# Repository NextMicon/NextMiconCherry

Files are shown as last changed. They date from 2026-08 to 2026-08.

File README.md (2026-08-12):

# NextMicon FPGA

**This repository has been split into per-board repositories and is archived.**
Development continues at
[NextMicon/cherry](https://github.com/NextMicon/cherry),
[NextMicon/grape](https://github.com/NextMicon/grape), and
[NextMicon/melon](https://github.com/NextMicon/melon).

NextMicon is a family of open-source FPGA development boards. Choose the compact Cherry to get started, or Grape for a larger FPGA and more I/O.

| | [🍒 Cherry](boards/cherry/) | [🍇 Grape](boards/grape/) | [🍈 Melon](boards/melon/) |
| ----- | --- | --- | --- |
| FPGA  | Lattice iCE40HX8K-BG121 | AMD Spartan-7 XC7S50-CSGA324 | AMD Artix-7 XC7A100T-1FGG676C |
| Logic | 7,680 (4-input LUT) | 32,600 (6-input LUT) | 63,400 (6-input LUT) |
| BRAM  | 128 Kbit | 2,700 Kbit | 4,860 Kbit |
| DSP | — | 120 | 240 |
| GPIO  | 64 | 128 | 256 |

## 🍒 NextMicon Cherry

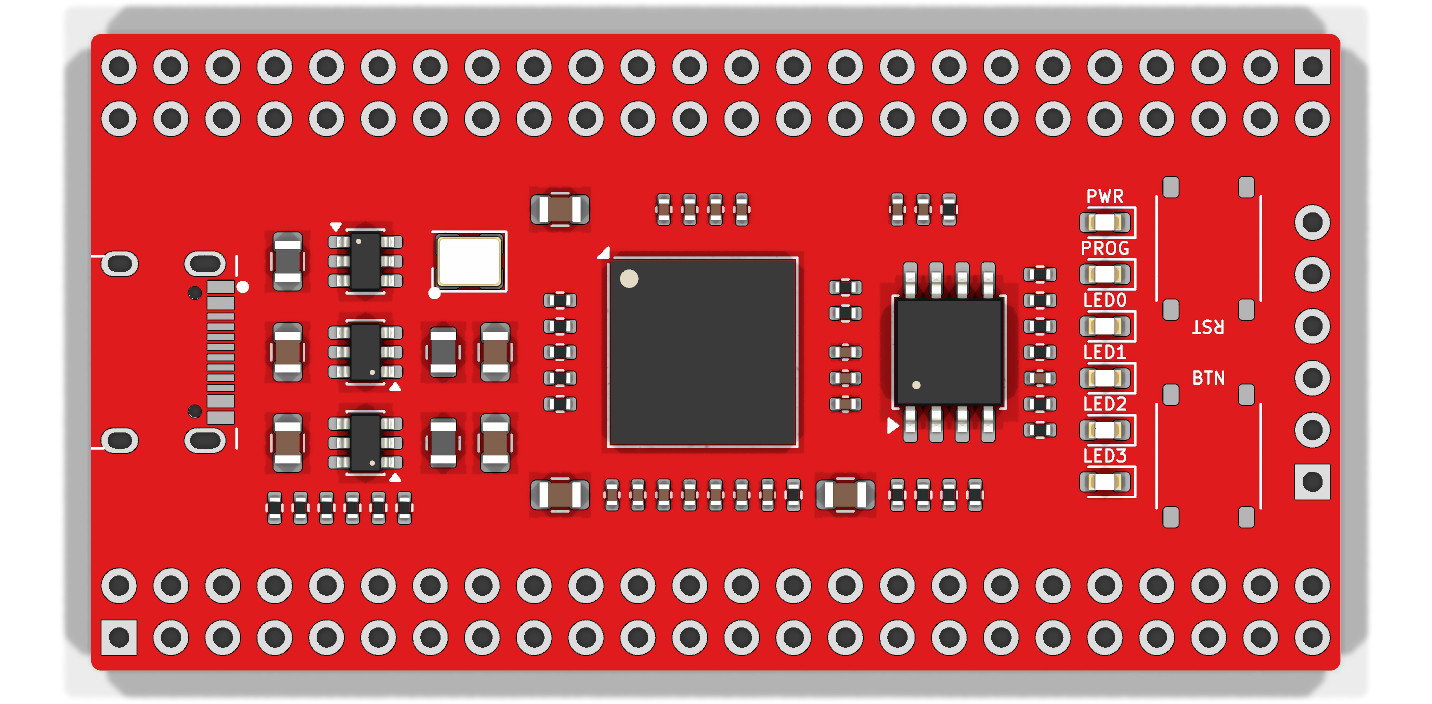
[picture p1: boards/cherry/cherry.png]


**A compact board for learning and small projects.** Cherry is built around the Lattice iCE40HX8K-BG121, with 7,680 LUTs, 64 GPIO pins, native USB Full-Speed, and protected `boot` plus writable `user` FPGA images. The repository includes its KiCad PCB design, fabrication outputs, bootloader HDL, and host application.

[Explore Cherry →](boards/cherry/)

Cherry firmware can be managed with the [`nmb` CLI](flash/cli/README.md) or the
[Web Serial flasher](flash/web/README.md).

## 🍇 NextMicon Grape

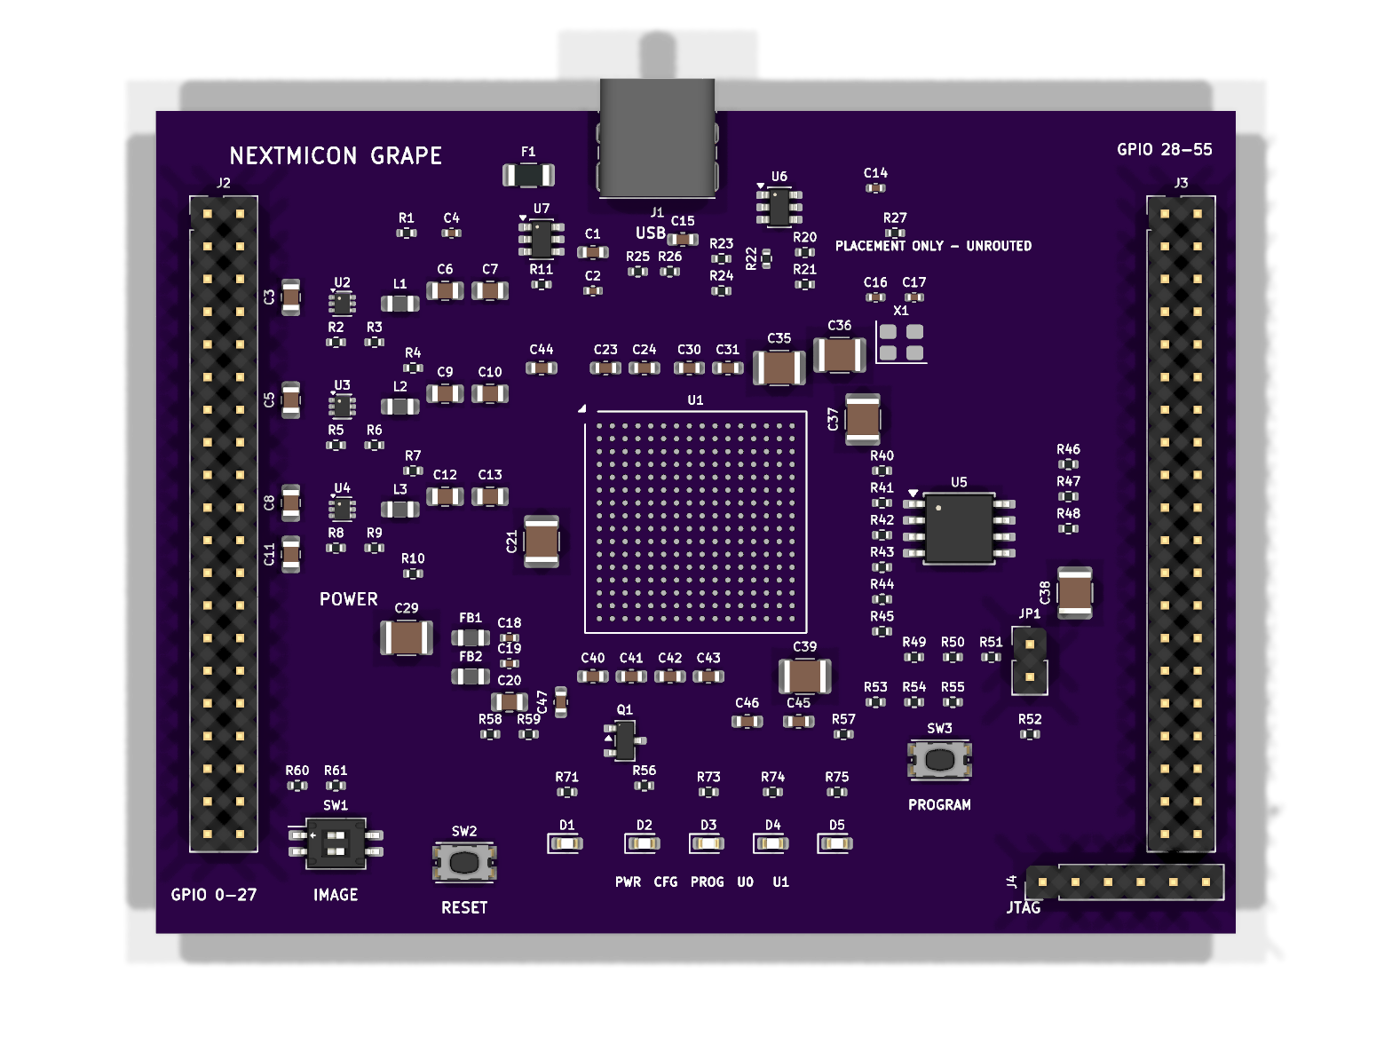
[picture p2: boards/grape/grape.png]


**A mid-range board for multi-channel phased-array acoustic field generation.** Grape uses the AMD Spartan-7 XC7S50-CSGA324 with 128 GPIO outputs and a 128-Mbit QSPI flash. Firmware is built and programmed with a fully open-source Yosys, nextpnr-xilinx, Project X-Ray, and openFPGALoader stack. Its schematic and PCB are being migrated from the earlier Artix-7 prototype.

[Explore Grape →](boards/grape/)

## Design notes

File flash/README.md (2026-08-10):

# NextMicon Flash CLI

`nmb` is the host-side programmer and image manager for NextMicon Cherry. Both
FPGA images enumerate as the same CDC ACM serial device. COBS-delimited frames
inside that serial stream provide independent BOOT, FLASH, and UART channels.

The complete wire format, including Web Serial usage, is documented in
[`doc/flash.md`](../../doc/flash.md).

## Build

```sh
cargo build --release
```

The executable is `target/release/nmb`. Linux users need permission to open the
CDC device, typically through the distribution's serial-port group or a udev
rule. Windows and macOS use their CDC ACM drivers.

### WebAssembly library

The library can also be built for the Web flasher:

```sh
wasm-pack build --target web --out-dir ../web/src/wasm/pkg --release
```

It exports `encodeMessageJson`, `decodeMessageJson`, and `crc32`.
`encodeMessageJson` converts a JSON message to the COBS-delimited wire frame;
`decodeMessageJson` validates and converts a wire frame back to JSON. The
generated package is consumed by `flash/web` and is not committed.

## Commands

List connected boards:

```console
$ nmb ls
cherry-0123

$ nmb ls --verbose
cherry-0123    boot    1234:0001    /dev/ttyACM0    NextMicon Cherry
```

Production VID/PID values are not allocated yet. By default `nmb` recognizes
the `NextMicon` manufacturer and `NextMicon Cherry` product strings. Discovery
can be restricted explicitly:

```sh
nmb --usb-id 1234:0001 ls
```

Warm boot either role:

```sh
nmb boot <board> <boot|user>
```

Erase, program, manifest, and read back the user image:

```sh
nmb flash <board> <bitstream.bin>
```

Start the image after successful verification:

```sh
nmb flash <board> <bitstream.bin> --boot
```

Before programming, `nmb` queries GET_INFO. If `user` is active, it requests
`boot`, waits for the same USB serial number to re-enumerate, verifies GET_INFO,
and then programs the single user image. `boot` is always protected;
factory/recovery updates use the external SPI header.

Use `nmb --help` or `nmb <command> --help` for all options. One framed request
defaults to a 30-second timeout and re-enumeration defaults to 15 seconds.

## Implementation

- `protocol.rs`: COBS framing, CRC32, channels, commands, and flash constants
- `message.rs`: validated JSON representation of a protocol frame
- `wasm.rs`: WASM exports for wire/JSON conversion and CRC32
- `serial.rs`: CDC port discovery, opening, streaming frame parser, and response matching
- `client.rs`: GET_INFO, BOOT, protected FLASH programming, and readback verification
- `manifest.rs`: 32-byte `NMF1` image manifest

The Rust host implementation and mock-device tests are complete. The matching
CDC ACM and frame engine still need to be implemented in Cherry HDL before a
physical board can answer the commands.

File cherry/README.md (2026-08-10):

# 🍒 NextMicon Cherry 🍒

FPGA Board for Beginners

## Schematic





## Specs

- FPGA: Lattice iCE40HX8K-BG121 (7680 LUTs, 9x9mm, 0.8mm pitch)
- GPIO: 36 pins (3.3V logic), 2x24 PinHeader x2 (paired contacts)
- Clock: 48MHz
- Flash: 32Mbit SPI Flash (30MB user area)
- Power: USB 5V → 3.3V → 1.2V
- Signal: 3.3V
- USB ESD Protection
- Switch: RESET / USER buttons, 2-bit Bitstream selector
- LED: PWR / CFG / USER0 / USER1 / PROG
- Board: 61mm x 31mm, 4-layer FR4

## Pinout

| Header | Pins |
| --- | --- |
| J2 (bottom rows, pin 1 = USB side) | 1 = 5V, 2 = 3V3, 3-5 = GND, 6 = CRESET_B, 7-24 = GPIO_1..18 |
| J3 (top rows, pin 24 = USB side) | 24 = 5V, 23 = 3V3, 22-19 = GND, 1-18 = GPIO_19..36 |
| J5 (right edge, pin 1 = bottom) | 1 = GND, 2 = CRESET_B, 3 = QSPI_CS_B, 4 = QSPI_SCK, 5 = QSPI_IO0, 6 = QSPI_IO1 |

J2 and J3 have two contacts for every pin number; the inner and outer contacts at the same position are electrically common.

## BOM

| Ref | Part | Package | Description | Cost | Buy |
| --- | --- | --- | --- | --- | --- |
| U2 | [W25Q32JVSSIM](data/W25Q32JV.pdf) | SOIC-8 208mil | 32Mbit SPI Flash | - | [digikey](https://www.digikey.com/en/products/result?keywords=W25Q32JVSSIM) |
| U3 | [iCE40HX8K-BG121](../parts/iCE40.pdf) | caBGA-121 0.8mm | FPGA 7680 LUTs | - | [digikey](https://www.digikey.com/en/products/result?keywords=ICE40HX8K-BG121) |
| U4-U5 | [TPS62A02](data/TPS62A02.pdf) | SOT-23-6 | 2A DC-DC Converter | $0.25  | [digikey](https://www.digikey.jp/ja/products/detail/texas-instruments/TPS62A02PDDCR/22147220)  |
| Q1 | BSS138 | SOT-23 | CDONE LED buffer | - | generic |
| D5 | USBLC6-2SC6 | SOT-23-6 | USB ESD protection | - | [digikey](https://www.digikey.jp/ja/products/result?keywords=USBLC6-2SC6) |
| X1 | OXETDLJANF-48.000000MHz | 3.2x2.5mm | 48MHz XO | - | generic |
| FB1 | BLM21AG601SH1D | 0805 | Ferrite bead (USB VBUS)| $0.19  | [digikey](https://www.digikey.jp/ja/products/detail/murata-electronics/BLM21AG601SH1D/2588067) |
| J1 | USB4085-GF-A | SMD 16pin | USB-C connector | $1.01  | [digikey](https://www.digikey.jp/ja/products/detail/gct/USB4085-GF-A/9859662) |
| J2-J3 | Pin header 2x24, paired contacts  | 2.54mm Pitch  | GPIO | - | generic |
| J5 | Pin header 1x06 | 2.54mm Pitch  | External SPI programming | - | generic |
### Passives

| Ref | Value | Pkg  | Qty | Notes |
| --- | ----- | ---- | --- | --- |
| C1-C2 | 10uF  | 0805 | 2 | 5V input bulk |
| C3-C4 | 22uF  | 0805 | 2 | 3V3 / 1V2 Buck output |
| C5-C7 | 10uF  | 0805 | 3 | Rail bulk (+3V3A / +1V2 / +3V3) |
| C8-C25  | 100nF | 0402 | 18  | IC Decoupling |
| C27 | 10uF  | 0805 | 1 | FPGA rail bulk |
| C28 | 100nF | 0402 | 1 | iCE40 VCCPLL filter |
| L1-L2 | 1uH | 0805 | 2 | Buck inductor (pick Isat >= 1.5A) |
| R1 | 100k  | 0402 | 1 | 3.3V feedback divider (1%) |
| R2 | 22k | 0402 | 1 | 3.3V feedback divider (1%) |
| R3-R4 | 100k  | 0402 | 2 | 1.2V feedback divider (1%) |
| R5-R6 | 5.1k  | 0402 | 2 | USB-C CC pull-down |
| R8-R11  | 10k | 0402 | 4 | Configuration and button pull-ups |
| R12 | 1k | 0402 | 1 | CDONE pull-up |
| R13 | 100 | 0402 | 1 | iCE40 VCCPLL filter |
| R14-R15 | 68 | 0402 | 2 | USB D+/D- series termination |
| R16 | 1.5k  | 0402 | 1 | Software-controlled USB D+ pull-up |
| R17 | 10k | 0402 | 1 | CRESET_B pull-up |
| R19-R22 | 1k | 0402 | 4 | LED current limiting |
| D1-D4 | LED | 0603 | 4 | PWR / CFG / USER0 / USER1 |
| SW1,SW3 | Tact  | SMD  | 2 | RESET / USER button |
| SW2 | DIP x2| SMD  | 1 | IMAGE cold-boot selector |

## Build

Toolchain: [Yosys](https://github.com/YosysHQ/yosys) + [nextpnr-ice40](https://github.com/YosysHQ/nextpnr) + [icestorm](https://github.com/YosysHQ/icestorm)

The pin and timing constraint files are [`src/cherry.pcf`](src/cherry.pcf) and
[`src/cherry.sdc`](src/cherry.sdc). Yosys produces the JSON netlist and nextpnr
consumes the PCF/SDC:

```bash
mkdir -p build
yosys -p 'synth_ice40 -top top -json build/top.json' rtl/top.v
nextpnr-ice40 --hx8k --package bg121 --freq 48 \
  --json build/top.json --pcf src/cherry.pcf --sdc src/cherry.sdc \
  --asc build/top.asc
icepack build/top.asc build/top.bin
```

Only ports present in the top-level HDL need to be used; nextpnr reports the
other PCF entries as harmless `unmatched constraint` warnings. Keep `clk_48m`
as an input. The commented SPI-flash constraints are intentionally reserved
because the flash and FPGA configuration controller share those four nets.

For recovery programming, power the board from USB and connect a 3.3V SPI
programmer to J5. Hold `CRESET_B` low while accessing the W25Q32, then release
it to boot the newly written image.

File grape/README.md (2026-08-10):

# 🍇 NextMicon Grape 🍇

NextMicon Grape is a FPGA Board for cyuukyusya.
Xilinx Artix-7 has more LUT cores and more fast signal processing units.

## Current design

- FPGA: AMD Artix-7 `XC7A35T-1FTG256C`
- Configuration: W25Q128JV 128-Mbit QSPI, four 4-MiB image slots
- Boot: Golden image at address zero, then `WBSTAR`/`IPROG` through `ICAPE2`
- USB: USB-C Full-Speed device connected directly to 3.3-V FPGA I/O
- Clock: 48 MHz oscillator on an SRCC input
- Power: USB 5 V to sequenced 1.0 V, 1.8 V and 3.3 V TPS62A02 rails
- I/O: 56 named 3.3-V GPIO signals on two 2x20 headers
- Recovery: external six-pin JTAG header, `PROGRAM_B`, and true cold-reset
- FPGA package and decoupling: FTG256, based on AMD UG475/UG483

The KiCad project is in [`pcb/src`](pcb/src).  No PCB layout has been created
yet.

## Important design choices

`M[2:0]` is strapped to `001` for Master SPI.  All VCCO banks, the
configuration bank, and the flash operate at 3.3 V; `CFGBVS` is therefore tied
to 3.3 V.  The two-bit `IMAGE` switch is normal FPGA GPIO sampled by the
Golden image—it is not a direct configuration-mode selector.

`JP1 GOLDEN_LOCK` pulls the flash `/WP/IO2` signal low.  Fit the jumper for
hardware-assisted x1-SPI Golden protection after setting the Winbond block and
status-register protection bits.  Remove it for factory update or future x4
QSPI operation.  Firmware must keep the FPGA IO2 pin high-impedance while the
jumper is fitted.

The TPS22917 load switch limits USB attach inrush into the regulator input
capacitors.  Its CT capacitor `C2` returns to `VBUS_FUSED` as required by the
device topology and is deliberately marked `TUNE`; its final value must be
selected from measured inrush and rise time.  The present design must remain
inside the current advertised by the connected USB-C source.  High-power user
images may require a later auxiliary-power option.

The Master-SPI mode straps and `PUDC_B` use 1-kohm resistors.  Flash IO2 and
IO3 use 4.7-kohm pull-ups for x4 configuration.  The XADC uses its on-chip
reference, with `VREFP`/`VREFN` returned locally to filtered analog ground.

## Generate and check

Requires KiCad 10.0.x and Python 3.  The generated schematic embeds its symbols.

```bash
python3 grape/pcb/tools/generate_schematic.py
kicad-cli sch upgrade --force grape/pcb/src/grape.kicad_sch
kicad-cli sch erc --severity-all \
  -o grape/pcb/erc.rpt grape/pcb/src/grape.kicad_sch
kicad-cli sch export pdf \
  -o grape/pcb/schematic.pdf grape/pcb/src/grape.kicad_sch
```

## Before PCB fabrication

- Recheck every FTG256 ball against the AMD package pin file and UG475.
- Run Xilinx Power Estimator with the intended maximum application image.
- Validate regulator stability, inductors, capacitor DC bias and startup order.
- Tune USB series resistors and load-switch rise time from measurements.
- Decide whether x1 physical Golden protection or x4 boot speed is the product
  default.
- Extend and validate the OSS bitstream writer for configuration rate, x4 SPI,
  CRC watchdog and automatic fallback.

## Primary references

- [AMD UG470: 7 Series FPGAs Configuration User Guide](https://docs.amd.com/v/u/en-US/ug470_7Series_Config)
- [AMD UG475: 7 Series FPGAs Packaging and Pinout](https://docs.amd.com/v/u/en-US/ug475_7Series_Pkg_Pinout)
- [AMD UG480: 7 Series XADC User Guide](https://docs.amd.com/r/en-US/ug480_7Series_XADC)
- [AMD UG483: 7 Series FPGAs PCB Design Guide](https://docs.amd.com/v/u/en-US/ug483_7Series_PCB)
- [TI TPS62A02 data sheet](https://www.ti.com/lit/ds/symlink/tps62a02.pdf)
- [TI TPS22917 data sheet](https://www.ti.com/lit/ds/symlink/tps22917.pdf)
- [Winbond W25Q128JV data sheet](https://www.winbond.com/resource-files/w25q128jv%20revf%2003272018%20plus.pdf)

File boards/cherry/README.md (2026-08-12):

# 🍒 NextMicon Cherry 🍒

FPGA Board for Beginners

## Repository layout

- [`board`](board/): KiCad design and fabrication outputs
- [`breakout`](breakout/): PMod breakout board
- [`firmware`](firmware/): FPGA HDL and constraints

## Schematic





## Specs

- FPGA: Lattice iCE40HX8K-BG121 (7680 LUTs, 9x9mm, 0.8mm pitch)
- GPIO: 64 pins (3.3V logic)
- PLL: 2x sysCLOCK PLL, external reference inputs broken out on J3 position 22 (PLL0_IN/PLL1_IN)
- Clock: 48MHz
- Flash: 32Mbit SPI Flash (3.5 MiB user-data area)
- Power: USB 5V → 3.3V → 1.2V
- Signal: 3.3V
- USB ESD Protection
- Switch: CRESET_B reset / USER buttons
- LED: PWR / PROG / USER0-USER3
- Board: 61mm x 31mm, 4-layer FR4

## Pinout

J2 and J3 are standard 2x24 headers. Each connector position `k` (1..24) has an
inner-row pad `2k-1` (odd) and an outer-row pad `2k` (even); the two rows carry
independent signals.

GPIOs are grouped in blocks of eight: D0-D3 sit on the inner row and D4-D7 sit
directly opposite on the outer row of the same four positions, so every block
forms one contiguous 2x4 window flanked by GND (inner) / 3V3 (outer) columns.
J2 carries GPIO_1..32 and J3 carries GPIO_33..64.

J2 (bottom edge, position 1 = USB side):

| Position | Inner row (odd pads) | Outer row (even pads) |
| --- | --- | --- |
| 1 | 5V | 5V |
| 2 | 3V3 | 3V3 |
| 3 | CRESET_B | 3V3 |
| 4 | GND | 3V3 |
| 5-8 | GPIO_1..4 | GPIO_5..8 |
| 9 | GND | 3V3 |
| 10-13 | GPIO_9..12 | GPIO_13..16 |
| 14 | GND | 3V3 |
| 15-18 | GPIO_17..20 | GPIO_21..24 |
| 19 | GND | 3V3 |
| 20-23 | GPIO_25..28 | GPIO_29..32 |
| 24 | GND | 3V3 |

J3 (top edge, position 24 = USB side):

| Position | Inner row (odd pads) | Outer row (even pads) |
| --- | --- | --- |
| 1 | GND | 3V3 |
| 2-5 | GPIO_33..36 | GPIO_37..40 |
| 6 | GND | 3V3 |
| 7-10 | GPIO_41..44 | GPIO_45..48 |
| 11 | GND | 3V3 |
| 12-15 | GPIO_49..52 | GPIO_53..56 |
| 16 | GND | 3V3 |
| 17-20 | GPIO_57..60 | GPIO_61..64 |
| 21 | GND | 3V3 |
| 22 | PLL0_IN | PLL1_IN |
| 23 | 3V3 | 3V3 |
| 24 | 5V | 5V |

| Header | Pins |
| --- | --- |
| J4 (right edge, pin 1 = bottom) | 1 = GND, 2 = CRESET_B, 3 = QSPI_CS_B, 4 = QSPI_SCK, 5 = QSPI_IO0, 6 = QSPI_IO1 |

The breakout board ([`breakout/`](breakout/)) accepts the Cherry via female
pin sockets (J2/J3/J4 plug straight in) and brings the 64 GPIOs out as eight
standard Pmod ports (8 GPIO each), plus an SPI header and a power/CRESET
utility header.

## BOM

| Ref | Part | Package | Description | Cost  | Buy |
| ----- | --- | --- | --- | ----- | --- |
| U1 | [W25Q32JVSSIQ](../../parts/W25Q32JV.pdf) | SOIC-8 208mil | 32Mbit SPI Flash | - | [digikey](https://www.digikey.com/en/products/result?keywords=W25Q32JVSSIQ) |
| U2 | [iCE40HX8K-BG121](../../parts/iCE40.pdf) | caBGA-121 0.8mm | FPGA 7680 LUTs | - | [digikey](https://www.digikey.com/en/products/result?keywords=ICE40HX8K-BG121) |
| U3-U4 | [TPS62A02](../../parts/TPS62A02.pdf) | SOT-23-6 | 2A DC-DC Converter | $0.25 | [digikey](https://www.digikey.jp/ja/products/detail/texas-instruments/TPS62A02PDDCR/22147220) |
| D1 | USBLC6-2SC6 | SOT-23-6 | USB ESD protection | - | [digikey](https://www.digikey.jp/ja/products/result?keywords=USBLC6-2SC6) |
| X1 | OXETDLJANF-48.000000MHz | 3.2x2.5mm | 48MHz XO | - | generic |
| FB1 | GZ2012D601TF | 0805 | Ferrite bead (USB VBUS)  | - | [lcsc](https://www.lcsc.com/search?q=GZ2012D601TF) |
| J1 | USB4085-GF-A | SMD 16pin | USB-C connector | $1.01 | [digikey](https://www.digikey.jp/ja/products/detail/gct/USB4085-GF-A/9859662) |
| J2-J3 | Pin header 2x24 | 2.54mm Pitch | GPIO | - | generic |
| J4 | Pin header 1x06 | 2.54mm Pitch | External SPI programming | - | generic |
### Passives

| Ref | Value | Pkg  | Qty |
| --- | --- | ---- | --- |
| C1,C3,C5,C14,C17 | 10uF | 0805 | 5 |
| C4,C6 | 22uF | 0805 | 2 |
| C2,C7-C13,C15-C16,C18-C24 | 100nF | 0402 | 17  |
| L1-L2 | TFM201208ALD-1R0MTCA | 0805 | 2 |
| R1-R2 | 5.1k | 0402 | 2 |
| R3,R5-R6 | 100k | 0402 | 3 |
| R4 | 22k | 0402 | 1 |
| R7 | 1.5k | 0402 | 1 |
| R8-R9 | 68 | 0402 | 2 |
| R10-R13,R16-R17,R22-R23 | 10k | 0402 | 8 |
| R14,R18-R21,R24-R25 | 1k | 0402 | 7 |
| R15 | 100 | 0402 | 1 |
| D2-D4,D6-D7 | KT-0603R | 0603 | 5 |
| D5 | LED_AMBER_0603 | 0603 | 1 |
| SW1-SW2 | TS-1187A-B-A-B | SMD  | 2 |
| JP1-JP2 | Solder jumper | SMD  | 2 |

## Build

Toolchain: [Yosys](https://github.com/YosysHQ/yosys) + [nextpnr-ice40](https://github.com/YosysHQ/nextpnr) + [icestorm](https://github.com/YosysHQ/icestorm)

The pin and timing constraint files are
[`firmware/cherry.pcf`](firmware/cherry.pcf) and
[`firmware/cherry.sdc`](firmware/cherry.sdc). Yosys produces the JSON netlist
and nextpnr consumes the PCF/SDC:

```bash
mkdir -p build
yosys -p 'synth_ice40 -top top -json build/top.json' rtl/top.v
nextpnr-ice40 --hx8k --package bg121 --freq 48 \
  --json build/top.json --pcf firmware/cherry.pcf --sdc firmware/cherry.sdc \
  --asc build/top.asc
icepack build/top.asc build/top.bin
```

Only ports present in the top-level HDL need to be used; nextpnr reports the
other PCF entries as harmless `unmatched constraint` warnings. Keep `clk_48m`
as an input. The commented SPI-flash constraints are intentionally reserved
because the flash and FPGA configuration controller share those four nets.

For recovery programming, power the board from USB and connect a 3.3V SPI
programmer to J4. Hold `CRESET_B` low while accessing the W25Q32, then release
it to boot the newly written image.

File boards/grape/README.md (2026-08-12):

# 🍇 NextMicon Grape 🍇

Mid-range FPGA board for multi-channel phased-array acoustic field generation.

## Repository layout

- [`board`](board/): KiCad design and fabrication outputs
- [`breakout`](breakout/): breakout and test-fixture designs
- [`firmware`](firmware/): FPGA HDL and constraints

## Schematic



## Target specs

- FPGA: AMD Spartan-7 `XC7S50-1CSGA324C`
  - 52,160 logic cells
  - 120 DSP48E1 slices
  - 2,764,800 bits of Block RAM
  - 210 user I/O pins in the CSGA324 package
- GPIO: 128 pins reserved for phased-array channel outputs
- GPIO logic level: 3.3 V
- Channel count: 128 channels with one GPIO per channel
- Clock: 100 MHz onboard oscillator; USB 48 MHz and application clocks generated by MMCM/PLL
- Configuration: 128-Mbit QSPI flash
- USB: USB-C for power and control
- Power: USB 5 V input with FPGA core, auxiliary, and I/O rails
- Recovery: external JTAG and `PROGRAM_B`
- FPGA package: CSGA324, 15 mm x 15 mm, 0.8 mm ball pitch
- GPIO connectors: four 2x24, 2.54 mm headers using the Cherry 8-pin group geometry
- Placement study: 140 mm x 70 mm, four layers, deliberately unrouted
- Final regulator sizing: pending electrical implementation verification

The 128 GPIO signals are logic-level timing outputs. External level shifters,
gate drivers, and power stages must be used to drive acoustic transducers; the
transducers must not be driven directly from FPGA pins.

## Intended architecture

Grape receives phase and optional amplitude parameters from a host and produces
phase-synchronous waveforms for up to 128 acoustic channels. The baseline
firmware uses a common phase accumulator and per-channel phase offsets stored in
Block RAM. All channel parameters are double-buffered so that an update can be
applied to every output on the same clock boundary.

The baseline design targets externally calculated phase values. Coordinate-to-
phase calculation, multi-focus synthesis, and closed-loop field control are
reserved for higher-end boards such as Melon.

## I/O allocation

The CSGA324 package provides up to 210 user I/O pins. The checked allocation is:

| Function | Pins | Notes |
| --- | ---: | --- |
| Phased-array outputs | 128 | Banks 15, 34 and 35; 3.3 V |
| Clock and USB | 3 | Bank 14; 100 MHz plus USB D+/D- |
| User strap, button and LEDs | 4 | Bank 14 |
| Configuration and JTAG | Dedicated | Bank 0 and Bank 14 configuration pins |

The generated and machine-checked mapping is [`board/pinout.csv`](board/pinout.csv).
Each set of 32 GPIOs uses one 2x24 header. As on Cherry, every group of eight is
a contiguous 2x4 window with four inner-row and four outer-row signals; group
separators carry GND on the inner row and 3.3 V on the outer row. The mapping
is generated from AMD's official `xc7s50csga324pkg.csv` by
[`board/tools/generate_pinout.py`](board/tools/generate_pinout.py).

If complementary high-side/low-side signals are generated directly by the
FPGA, 128 GPIOs provide 64 channels. The preferred 128-channel implementation
uses one FPGA output per channel and generates complementary drive signals in
the external driver stage.

## Current hardware status

The existing KiCad files under [`board/src`](board/src) describe the earlier
Artix-7 `XC7A35T-1FTG256C`, 56-GPIO prototype. They do not yet implement this
Spartan-7 target specification. The schematic, PCB, power tree, FPGA symbol,
pin assignments, decoupling, and constraints must be migrated to
`XC7S50-1CSGA324C` before fabrication.

The replacement six-unit KiCad symbol
[`board/src/grape-fpga.kicad_sym`](board/src/grape-fpga.kicad_sym) is generated
from AMD's production `xc7s50csga324pkg.csv`; it contains all 324 unique package
balls and uses the matching `Package_BGA:Xilinx_CSGA324` footprint. Regenerate
it with [`board/tools/generate_fpga_symbol.py`](board/tools/generate_fpga_symbol.py).
The symbol and checked 128-GPIO pinout are ready; integration into the new
schematic and PCB is in progress. The old schematic and placement board remain
non-fabrication references until that migration is complete.

## Build

Grape is developed with a fully open-source FPGA toolchain. AMD Vivado is not
used or required by the intended build and programming workflow.

- HDL synthesis: [Yosys](https://github.com/YosysHQ/yosys)
- Place and route: [nextpnr-xilinx](https://github.com/gatecat/nextpnr-xilinx)
- 7-series device database and bitstream support:
  [Project X-Ray](https://github.com/f4pga/prjxray)
- Timing constraints: XDC
- Bitstream and QSPI programming:
  [openFPGALoader](https://github.com/trabucayre/openFPGALoader)

The repository will provide reproducible command-line build scripts and pinned
tool/database revisions. The exact `xc7s50csga324-1` part is present in the
Project X-Ray database; the complete build and programming flow must still be
validated on Grape hardware before release.

The final top-level port names, XDC pin constraints, clock constraints, and
bitstream/flash programming procedure will be documented after the schematic
and connector pinout are fixed.

## Before PCB fabrication

- Assign all 128 outputs using the official CSGA324 package pin file.
- Reserve configuration, JTAG, clock, USB/control, and debug pins first.
- Check every I/O bank voltage and the simultaneous-switching-output limits.
- Establish a worst-case power budget from AMD data-sheet values and measured
  activity from the open-source implementation.
- Verify regulator capacity, startup sequencing, thermal margin, and decoupling.
- Validate that the external driver input load is within the FPGA I/O limits.
- Add source-series termination where signal-integrity analysis requires it.
- Complete schematic ERC and routed-board DRC before generating fabrication data.

## Primary references

- [AMD DS189: Spartan-7 FPGAs Data Sheet](https://docs.amd.com/v/u/en-US/ds189-spartan-7-data-sheet)
- [AMD DS180: 7 Series FPGAs Overview](https://docs.amd.com/v/u/en-US/ds180_7Series_Overview)
- [AMD UG470: 7 Series FPGAs Configuration User Guide](https://docs.amd.com/v/u/en-US/ug470_7Series_Config)
- [AMD UG475: 7 Series FPGAs Packaging and Pinout](https://docs.amd.com/v/u/en-US/ug475_7Series_Pkg_Pinout)
- [AMD UG479: 7 Series DSP48E1 Slice User Guide](https://docs.amd.com/v/u/en-US/ug479_7Series_DSP48E1)
- [AMD UG483: 7 Series FPGAs PCB Design Guide](https://docs.amd.com/v/u/en-US/ug483_7Series_PCB)

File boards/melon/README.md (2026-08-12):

# 🍈 NextMicon Melon 🍈

High-density NextMicon FPGA board placement study.

## Target

- FPGA: AMD Artix-7 `XC7A100T-1FGG676C`
- GPIO: 256 pins, 3.3 V logic
- GPIO connectors: eight 2x24, 2.54 mm headers
- GPIO geometry: 32 groups of eight, using the same contiguous 2x4 windows as Cherry and Grape
- Configuration: protected boot image followed by an ICAPE2/WBSTAR/IPROG user image
- Default user selection: back-side `DEFAULT_USER` solder jumper
- Clock: independent onboard oscillator; not required to match Cherry or Grape
- Placement PCB: 150 mm x 120 mm, six layers, deliberately unrouted

## Placement

The current [`board/src/melon.kicad_pcb`](board/src/melon.kicad_pcb) is a
placement-only board with no schematic nets, tracks, vias, planes, or copper
zones. The eight headers are arranged two per row across four rows. Adjacent
header rows use 7.62 mm center spacing, leaving one 2.54 mm pin-row interval
between their bodies. They provide
32 GPIO positions each, for 256 GPIOs total;
the remaining 16 contacts on every 2x24 header are reserved for GND, 3.3 V and
board utility connections following the Cherry grouping pattern.

The checked FPGA-to-header allocation is [`board/pinout.csv`](board/pinout.csv).
It is generated from AMD's production `xc7a100tfgg676pkg.csv` by
[`board/tools/generate_pinout.py`](board/tools/generate_pinout.py).

Regulator footprints are placement reservations only. Parts and thermal/current
ratings must be selected from a final power estimate before fabrication.

## Regeneration

```bash
python3 board/tools/generate_pinout.py
python3 board/tools/generate_placement.py
kicad-cli pcb drc --all-track-errors \
  -o board/placement-drc.rpt board/src/melon.kicad_pcb
```

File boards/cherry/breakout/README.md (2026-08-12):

# Cherry Pmod breakout board

Cherryのピンヘッダ(J2/J3/J4)を上から**ピンソケット(S2/S3/S4)に挿し込み**、全64本のGPIOを8ポートのPmod(2×6、12ピン)として引き出すブレークアウト基板です。工場テスト(factory-test.sh)と、Pmodモジュールを挿しての動作確認の両方に使えます。

## ポート構成

| ポート | GPIO | 位置 |
| --- | --- | --- |
| PMOD1  | GPIO_1-8 | 下辺 左 |
| PMOD2  | GPIO_9-16  | 下辺 中左 |
| PMOD3  | GPIO_17-24 | 下辺 中右 |
| PMOD4  | GPIO_25-32 | 下辺 右 |
| PMOD5  | GPIO_33-40 | 上辺 右 |
| PMOD6  | GPIO_41-48 | 上辺 中右 |
| PMOD7  | GPIO_49-56 | 上辺 中左 |
| PMOD8  | GPIO_57-64 | 上辺 左 |

Cherry側のGPIOはブロック対配置(D0-D3が内側列、D4-D7がその対向の外側列)なので、各Pmodポートは Cherry の1つの2×4ブロックにそのまま対応します。各ポートのピン配置はPmod標準どおり: 1-4 = D0-D3、5 = GND、6 = 3V3、7-10 = D4-D7、11 = GND、12 = 3V3。D0が各ブロックの最小GPIO番号です(例: PMOD5のD0 = GPIO_33)。Pmodソケットは2×6のライトアングル・メスを基板端向きに実装します(実装前にピン1の向きをシルクの角パッドで確認してください)。

- S2/S3: 2×24ピンソケット。Cherry J2/J3が挿さります(ソケットのピン番号 = Cherryのパッド番号)。
- S4: 1×6ピンソケット。Cherry J4が挿さります。
- J5: Cherry J4のSPI/CRESET/GNDを引き出す1×6ピンヘッダ(右辺)。
- J6: +5V / +3V3 / GND / CRESET_B のユーティリティ、1×6ピンヘッダ(左辺)。
- USB-CはCherry本体へ直接接続します。基板にはUSB回路を載せません。
- F.Fabレイヤの破線はCherry外形、MH1--MH4はM3スタンドオフ用です。

電源はGND(裏面ベタ)と+3V3(表面ベタ)のゾーンで配電し、Cherryの全GND/3V3ピンとPmodの電源ピンを共通ネットに接続しています。GPIOと SPI/CRESET は1:1配線です。ソケットピンと引き出し先の対応は[`pinmap.csv`](pinmap.csv)を参照してください(`fixture_ref`はソケット:パッド番号、`dut_pin`はコネクタ位置1..24、`breakout_pin`は引き出し先)。

[`src/fixture.kicad_pcb`](src/fixture.kicad_pcb)は[`tools/gen_fixture.py`](tools/gen_fixture.py)で生成しています(配線・ゾーン込み。再生成後は pcbnew Python でゾーンを塗り直してください)。座標や割当を変えるときは手編集せずスクリプトを直して再生成してください。

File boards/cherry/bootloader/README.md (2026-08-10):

# NextMicon Cherry firmware

Native USB management, boot, flash, and runtime HDL for the iCE40HX8K-BG121.

## USB transport

Every image enumerates as one CDC ACM serial device with the same endpoint
layout:

| Purpose | Endpoint | Transfer |
| --- | --- | --- |
| CDC notification | EP1 IN (`0x81`) | Interrupt |
| CDC serial host-to-FPGA | EP2 OUT (`0x02`) | Bulk |
| CDC serial FPGA-to-host | EP2 IN (`0x82`) | Bulk |

The CDC byte stream carries COBS-delimited frames. A channel byte inside each
frame selects BOOT, FLASH, or UART, so arbitrary UART data is never scanned for
a reboot escape sequence. The protected `boot` image reports BOOT and FLASH
capabilities; the writable `user` image reports BOOT and UART capabilities.

The protocol constants are in `src/protocol.veryl` and the complete wire
format is documented in [`doc/flash.md`](../../../doc/flash.md).

The current code defines the shared constants, endpoint policy, and final
warm-boot request controller. The USB physical engine, CDC standard/class
request handler, COBS frame codec, flash commands, and UART FIFOs remain to be
implemented.

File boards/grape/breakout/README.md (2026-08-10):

# NextMicon Grape breakout

Grape用のbreakout boardおよびfactory-test fixtureをこのディレクトリで管理します。
設計はまだ未着手です。

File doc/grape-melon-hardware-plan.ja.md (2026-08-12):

# Grape / Melon ハードウェア設計判断

作成日: 2026-08-12

この文書は、Cherryを基準にGrapeおよびMelonの回路図・基板を設計する前に固定した
ハードウェア要件である。対象デバイスはGrapeが`XC7S50-1CSGA324C`、Melonが
`XC7A100T-1FGG676C`である。

## 調査資料

取得したAMD公式資料は[`../parts/amd/`](../parts/amd/)に保存した。

- DS180: 7 Series FPGAs Overview
- DS181: Artix-7 DC and AC Switching Characteristics
- UG470: 7 Series FPGAs Configuration User Guide
- UG475: 7 Series FPGAs Packaging and Pinout
- UG483: 7 Series FPGAs PCB Design Guide
- GrapeのSpartan-7電気特性は[DS189](https://docs.amd.com/r/en-US/ds189-spartan-7-data-sheet)
  revision 1.11も参照する。
- QSPIフラッシュは[`../parts/W25Q128JV.pdf`](../parts/W25Q128JV.pdf)を参照する。

回路図のピン割当を確定する際は、UG475の概略図だけでなく対象デバイス・パッケージの
公式ASCII package pin fileと照合する。Grapeの既存`board/pinout.csv`は照合元を明記して
再生成し、Melonにも同じ生成・検査手順を用いる。

## 固定する構成

### 電源

- USB VBUSから`1.0 V`（VCCINT/VCCBRAM）、`1.8 V`（VCCAUX）、`3.3 V`
  （VCCO）を生成する。
- 推奨投入順序は`VCCINT/VCCBRAM`、`VCCAUX`、`VCCO`、切断時は逆順とする。
- 全GPIOバンクは3.3 V HR I/Oとして用いる。Bank 0も3.3 Vとし、`CFGBVS`は
  `VCCO_0`へ接続する。Master SPIで使うBank 14/15もコンフィグ時の電圧整合を取る。
- 各レールの容量、過渡応答、起動時間、FPGA直下のデカップリング配置は、最終I/O
  トグル率を入力した電力見積り後に確定する。Grape旧回路のレギュレーター定格を
  Melonへ無条件にコピーしない。
- Grapeは4層を最低構成、MelonのFGG676は電源島とBGA escapeの都合から6層以上を
  初期案とし、4層へ縮小しない。

### コンフィグレーションとブート

- モードはMaster SPI x4、フラッシュは128 Mbit以上とする。
- アドレス0に書換え保護した`boot`（AMD文書でいうgolden image）を置く。
- 電源投入時は常に`boot`をコンフィグレーションする。`boot`がUSB Full-Speed CDC
  デバイスとして列挙し、ユーザーイメージの検査・書込みを行う。
- userを起動するときは`boot`内の`ICAPE2`から`WBSTAR`へuser先頭アドレスを書き、
  `IPROG`を発行する。userのコンフィグレーション失敗時はアドレス0のbootへ
  fallbackする。
- 裏面に`DEFAULT_USER`はんだジャンパーを置く。オープンはboot待機、ブリッジは
  bootがUSB D+プルアップを有効にする前に検査済みuserへ進む。これは7-seriesの
  モードピンではなく、bootコンフィグレーション後に読む専用GPIOである。
- `DEFAULT_USER`をブリッジしていてもboot自体は最初に必ずロードされる。復旧のため、
  userマニフェスト不正時と指定ボタン押下時はbootに留まる。
- bootとuserは同じUSB VID/PID、descriptorおよびCDC endpoint構成を使う。切替え前に
  USBを論理切断し、user起動後に再列挙する。
- `PROGRAM_B`は4.7 kΩ以下でpull-upし、押しボタンとJTAGヘッダーへ出す。
  `INIT_B`も4.7 kΩ以下でpull-upする。`DONE`、`INIT_B`は状態確認できるようにする。
- `PROGRAM_B`を電源投入時からLowに保持してコンフィグを止める設計にはしない。
  UG470の指定どおり、必要なら`INIT_B`で初期化後の進行を止める。
- JTAG、QSPI、PROGRAM_B、GND、3.3 Vを復旧用ヘッダーまたはテストパッドへ出す。

### クロック

- GrapeおよびMelonの外部基準クロックをCherryと同じ48 MHzには固定しない。
- USB Full-Speed PHY/プロトコル処理に必要なクロックドメインは、外部基準クロックから
  FPGA内蔵MMCM/PLLで生成する。生成可能な周波数、VCO範囲、入力ジッタ、起動・lock時間を
  実装前に確認する。
- 外部発振器はGrapeとMelonで個別に選定できる。位相配列出力の時間分解能、DSP処理、
  クロック対応ピン、ジッタ、消費電力、部品入手性を比較して周波数を決める。
- 発振器は対象bankのclock-capable inputへ接続し、単端／差動方式とI/O電圧は選定部品に
  合わせる。XDCには入力クロック周期と生成クロックを明記する。
- bootとuserは同じ外部発振器設定およびUSBクロック生成条件を共有する。

### GPIOヘッダー

- Cherryと同じ2列2.54 mmヘッダーを用い、GPIO 8本を連続した`2x4`窓にする。
- 各グループは内列4本、対向する外列4本とし、グループ間に内列GND／外列3.3 Vの
  電源位置を置く。コネクター端にもGND、3.3 V、必要な5 Vを置く。
- Grapeは16グループ、合計128 GPIO、Melonは32グループ、合計256 GPIOとする。
- 1グループを可能な限り同一I/O bankに収める。差動対は対向ピンへ分断せず、クロック
  capable pin、VREF、コンフィグ兼用ピンを先に予約する。
- 初期XDCは`LVCMOS33`、`DRIVE 4`、`SLEW SLOW`とし、128/256本同時スイッチングを
  想定したSSO確認なしに駆動力やslewを上げない。

## 現行ファイルの扱い

Grapeの現行回路図は`XC7A35T-1FTG256C`用であり、目的のSpartan-7 CSGA324回路として
製造してはならない。現行PCBは部品配置のみで、配線、via、plane、zoneがない。
新しい回路図へ移行後、ネットリストから基板を作り直す。

Melonはまだボードディレクトリがないため、Grapeの完成済み共通ブロックをテンプレートに
する。ただしFGG676の電源ピン、bank構成、BGA escape、デカップリングは専用設計にする。

## 完了条件

回路図・基板を「完成」とする条件は次のとおり。

1. 公式package pin fileとの全BGA ball自動照合
2. KiCad ERCエラー0（意図した例外は文書化）
3. 全GPIO、USB、QSPI、JTAG、電源ネットのnetlist検査
4. PCB上の未配線0、DRCエラー0
5. 電源plane、帰路、差動USB、クロック、QSPIの配線レビュー
6. 電源・熱・SSO見積りと、レギュレーター起動順序の確認
7. 製造用出力とは別に回路図PDF、基板表裏PDF、BOM、pinout、XDCを生成

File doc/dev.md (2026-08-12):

# Development guide

KiCad Version = 10.0.3

```
boards/cherry/
├── board/      # KiCad project, libraries, and fabrication outputs
├── breakout/   # Breakout and factory-test fixture
├── firmware/   # FPGA HDL and constraints
└── README.md
```

## 1. Install KiCad

```bash
$ sudo add-apt-repository --yes ppa:kicad/kicad-10.0-releases
$ sudo apt update
$ sudo apt install --install-recommends kicad
$ kicad-cli version
10.0.3
```

## 2. Setup KiCad MCP

TBD

## 3. Open KiCad project

```
$ kicad boards/cherry/board/src/cherry.kicad_pro
```

## 4. Render board image

```bash
$ kicad-cli pcb render -o boards/cherry/cherry.png \
    --side top --width 1440 --height 720 --zoom 1.8 --quality high \
    boards/cherry/board/src/cherry.kicad_pcb
```

# Development Notes

Commands for regenerating documents and fabrication data.
All commands run from the repository root.

## Requirements

- KiCad 10.0+ (`kicad-cli` in PATH)
- On WSL: the Linux `kicad-cli` may fail to read this project's file format.
  Use the Windows binary instead:

```bash
alias kicad-cli='"/mnt/c/Program Files/KiCad/10.0/bin/kicad-cli.exe"'
# Pass Windows-style paths via: $(wslpath -w <path>)
```

## Design checks (run before committing)

```bash
# ERC (expect 0 violations)
kicad-cli sch erc --severity-all -o erc.rpt src/cherry.kicad_sch

# DRC + schematic parity (expect 0 parity issues; baseline warnings are
# 11x lib_footprint_mismatch (intentional local overrides) + 2x silk_edge_clearance)
kicad-cli pcb drc --schematic-parity --severity-all -o drc.rpt src/cherry.kicad_pcb
```

## PDF / images (committed at repo root)

```bash
# Schematic PDF
kicad-cli sch export pdf -o schematic.pdf src/cherry.kicad_sch

# Board PDF (one page per layer, board outline on every page)
kicad-cli pcb export pdf --mode-multipage \
  -l "F.Cu,In1.Cu,In2.Cu,B.Cu,F.Silkscreen,B.Silkscreen,F.Mask,B.Mask,F.Fab,B.Fab" \
  --cl "Edge.Cuts" --include-border-title \
  -o board.pdf src/cherry.kicad_pcb

# Board render for README
kicad-cli pcb render --side top --width 1432 --height 704 \
  -o doc/img/board.png src/cherry.kicad_pcb
```

## Fabrication data (JLCPCB PCBA)

Output goes to `out/` (gitignored). Three deliverables: gerber zip, BOM CSV, CPL CSV.

### 1. Gerbers + drill

```bash
mkdir -p out/gerber

kicad-cli pcb export gerbers \
  -l "F.Cu,In1.Cu,In2.Cu,B.Cu,F.Silkscreen,B.Silkscreen,F.Mask,B.Mask,F.Paste,B.Paste,Edge.Cuts" \
  --no-x2 --subtract-soldermask --use-drill-file-origin \
  -o out/gerber src/cherry.kicad_pcb

kicad-cli pcb export drill \
  --format excellon --excellon-units mm --excellon-separate-th \
  --generate-map --map-format gerberx2 \
  -o out/gerber src/cherry.kicad_pcb

(cd out && zip -r cherry-gerber.zip gerber)
```

### 2. BOM (JLC format)

LCSC part numbers live in an `LCSC` field on each schematic symbol (populated
2026-08-10). Intentionally blank fields:

- `X1` (Abracon ASE XO): not stocked at LCSC - use JLC Global Sourcing /
  consignment, or pick an LCSC-stocked 12 MHz 3225 XO (+/-25 ppm or better).
- `L1-L2`: select a 0805 1 uH inductor with Isat >= 1.5 A at order time.
- `D1-D4`: pick LED colors (0603).
- `J2-J6`: generic headers, normally left unpopulated.

Substitutions used for LCSC availability (same footprint / spec family):
`U2` = C179173 (W25Q32JVSSIQ; SSIM is not listed on LCSC),
`FB1-FB2` = C85837 (BLM21AG601SN1D standard grade; BOM names SH1D).

```bash
kicad-cli sch export bom \
  --fields "Value,Reference,Footprint,LCSC" \
  --labels "Comment,Designator,Footprint,LCSC Part #" \
  --group-by "Value,Footprint" --exclude-dnp \
  -o out/cherry-bom.csv src/cherry.kicad_sch
```

### 3. CPL (component placement)

```bash
kicad-cli pcb export pos \
  --format csv --units mm --side front \
  --use-drill-file-origin --exclude-dnp --smd-only \
  -o out/cherry-cpl.csv src/cherry.kicad_pcb

# Rename header to JLC column names
sed -i '1s/.*/Designator,Val,Package,Mid X,Mid Y,Rotation,Layer/' out/cherry-cpl.csv
```

### Ordering notes

- 4-layer stackup: JLC04161H-7628 (matches the board's stackup settings, ~1.6 mm).
- All SMD parts are on the top side (single-side assembly). Pin headers
  (J2-J6) are through-hole: order unpopulated or add JLC hand-soldering service.
- Component rotations for polarized parts (U1 pin 1, LEDs D1-D4, D5/U4/U5,
  U3 BGA) must be verified in the JLCPCB order preview - JLC rotation
  conventions differ from KiCad for some packages.
- FT2232HL / iCE40 are Extended parts (loading fee applies); most 0402/0805
  passives map to Basic parts.

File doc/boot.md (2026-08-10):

# Boot Sequence

[日本語](boot.ja.md)

Wire protocol: [CDC Flash Protocol](flash.md)

This document defines the intended Cherry boot behavior for the hardware, FPGA
images, and host tool. It does not imply that every transport and manifest
check is already implemented. The flash layout remains subject to final
bitstream-size and `icemulti` verification.

## Images and cold-boot selection

The W25Q32 stores two FPGA images with fixed roles:

| `CBSEL0` | Role | Contents | Framed channels |
| ---: | --- | --- | --- |
| `0` | `boot` | Protected programmer and recovery image | BOOT and FLASH |
| `1` | `user` | User application | BOOT and UART |

The board has one `CBSEL0` solder jumper. Open selects `boot`; bridging it
selects `user`. `CBSEL1` is permanently held low, so cold boot cannot select
the unused iCE40 vectors 2 and 3. Changing the jumper does not affect the
running image; the new value is sampled at the next rail reset.

## Cold boot

1. USB VBUS powers the board. Releasing `RESET` enables the 3.3 V and 1.2 V
   regulators and lets both rails start from a discharged state.
2. The iCE40 configuration controller reads the cold-boot applet and vector
   table at flash address `0x000000`.
3. The controller samples `CBSEL0`. An open jumper loads `boot`; a bridge loads
   `user` directly. The boot image does not run first when `user` is selected.
4. After a valid configuration has loaded, the open-drain `CDONE` pin releases
   high through its pull-up.
5. The selected image initializes its 48 MHz USB logic and asserts the
   controllable D+ pull-up. Both images enumerate with the same CDC ACM
   identity and endpoint layout.

`boot` turns on the amber `PROG` LED and waits indefinitely for a host command.
It never times out into `user`. The `user` image keeps `PROG` off and provides
the common BOOT manager plus the framed UART byte-stream channel.

## USB transport relevant to boot

Both images expose one CDC ACM serial function. EP1 IN carries CDC
notifications and EP2 OUT/IN carries the framed byte stream. Frames contain a
channel number, so BOOT, FLASH, and UART never inspect one another's payload.

| Channel | `boot` | `user` |
| --- | --- | --- |
| BOOT (`0x01`) | Available | Available |
| FLASH (`0x02`) | Available | Unavailable |
| UART (`0x03`) | Unavailable | Available |

GET_INFO reports the active role and capabilities in-band. USB descriptors,
VID/PID, product string, and serial number remain the same in both images.

## Host-requested warm boot

Both valid images implement the BOOT service. A warm boot uses internal
`S1:S0` inputs to `SB_WARMBOOT`; it does not resample the solder jumper. `S1`
is always `0`, and `S0` selects `boot` (`0`) or `user` (`1`).

1. The host sends a framed BOOT SELECT_IMAGE command containing one target
   byte: `0` for `boot` or `1` for `user`.
2. The active image validates the role and, for `user`, its manifest. The
   response contains one status byte:

   | Status | Meaning |
   | ---: | --- |
   | `0` | Request accepted |
   | `1` | Invalid image byte or payload |
   | `2` | Invalid user manifest |
   | `3` | Manager busy |

3. For an accepted request, the response frame and CDC IN transfer finish
   before USB or QSPI is quiesced.
4. The manager blocks new QSPI work, waits for current work and the flash WIP
   bit to clear, restores ordinary one-bit SPI command mode, and raises flash
   `/CS`.
5. The manager disconnects USB, registers the target on `S0` while holding
   `S1=0`, and asserts `SB_WARMBOOT` on a later clock.
6. The selected image loads and enumerates again with the same USB identity.

Selecting the active role deliberately restarts it. Warm boot does not change
the physical jumper, so the next `RESET` again uses the jumper value.

## Development programming loop

1. Open the selector jumper and press `RESET` to start `boot`.
2. Through its FLASH channel, erase the single `user` slot and write the
   bitstream and manifest.
3. Verify the manifest, CRC, and flash readback.
4. Send SELECT_IMAGE `1`; after acknowledgement, wait for `user` to enumerate.
5. To program again, send SELECT_IMAGE `0` and wait for `boot` to enumerate.

The host tools therefore never ask for a destination slot: `user` is the only
USB-writable FPGA image.

## Flash layout

The 4 MiB W25Q32 contains two 256 KiB image regions and a 3.5 MiB user-data
region.

| Flash range | Size | Contents | Write policy |
| --- | ---: | --- | --- |
| `0x000000-0x03FFFF` | 256 KiB | Cold-boot table and protected `boot` image | Factory/recovery tool only |
| `0x040000-0x07FFFF` | 256 KiB | `user` image and manifest | `boot` programmer only |
| `0x080000-0x3FFFFF` | 3.5 MiB | User data | Explicit user-data operations only |

The factory image is assembled at 256 KiB alignment:

```bash
icemulti -c -a18 -o factory.bin boot.bin user.bin
```

Normal USB programming must never erase or program `boot`. User code must not
leave the W25Q32 in persistent QPI mode because cold boot requires ordinary SPI
command framing.

## RESET, external programming, and recovery

The front-panel `RESET` button is a rail reset, not a direct `CRESET_B` reset.
While held, it disables both regulators through `PWR_EN`; releasing it restarts
the rails and samples the selector again. Supplying 3.3 V externally can bypass
this behavior and is not a supported normal operating mode.

`CRESET_B` is pulled high and exposed on J5 for factory programming and
last-resort recovery:

1. Power the board from USB and connect a 3.3 V SPI programmer to J5.
2. Pull `CRESET_B` low so the shared configuration pins are high impedance.
3. Program and verify the complete factory image through CS/SCK/MOSI/MISO.
4. Release `CRESET_B`; the FPGA follows the normal jumper-selected cold boot.

If `user` is invalid or cannot process SELECT_IMAGE `0`, open the jumper and
press `RESET` to start protected `boot`. If `boot` or the cold-boot table is
damaged, use the external SPI procedure.

## Boot-time hardware constraints

- Do not externally drive K10 (`/CS`), L10 (`SCK`), K9 (`IO0`), or J9 (`IO1`)
  during cold boot.
- After configuration, the active image owns all six QSPI signals and must
  quiesce them before warm boot.
- FPGA ball E10 is driven by the 48 MHz oscillator and must remain an HDL clock
  input.

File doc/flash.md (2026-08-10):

# CDC Flash Protocol

[日本語](flash.ja.md)

This document defines the serial framing, boot management, flash programming,
and user-data channels shared by NextMicon Cherry FPGA images, the `nmb` host
tool, and Web Serial applications. The multiboot sequence and flash map are
described in [boot.md](boot.md).

The Rust host in `flash/cli` and the static Web Serial application in
`flash/web` implement this protocol. The corresponding CDC ACM USB engine and
frame handlers in the Cherry HDL remain to be implemented.

## Transport choice

Every image enumerates as the same USB CDC ACM serial device. BOOT, FLASH, and
UART are logical channels inside a framed serial byte stream; they are not
separate USB endpoints. This lets native applications use the operating
system's serial driver and lets compatible browsers program a board through
Web Serial.

The stream is always framed. User UART bytes are carried as UART-channel frame
payloads and are never scanned for a reboot escape sequence.

## USB CDC ACM profile

Cherry is a USB 2.0 Full-Speed, bus-powered device. It uses a 48 MHz FPGA clock
and operates at 12 Mbit/s.

| Purpose | Interface/endpoint | Type | Max packet |
| --- | --- | --- | ---: |
| Standard and CDC requests | EP0 | Control | 64 bytes |
| CDC notification | EP1 IN `0x81` | Interrupt | 16 bytes |
| CDC serial host-to-FPGA | EP2 OUT `0x02` | Bulk | 64 bytes |
| CDC serial FPGA-to-host | EP2 IN `0x82` | Bulk | 64 bytes |

The CDC function contains one Communication Class interface and one Data Class
interface with Header, Call Management, ACM, and Union functional descriptors.
It supports at least:

- standard USB enumeration and endpoint-halt requests;
- `SET_LINE_CODING` and `GET_LINE_CODING`;
- `SET_CONTROL_LINE_STATE`;
- CDC `SERIAL_STATE` notification on EP1 IN.

The nominal host setting is 115200, 8 data bits, no parity, and 1 stop bit.
Because this is a synchronous USB stream, the baud-rate field does not control
wire speed. DTR, RTS, baud-rate changes, and BREAK must never select an FPGA
image or erase flash.

### Stable device identity

The `boot` and `user` images use the same VID, PID, manufacturer, product, and serial
number. Active image and capabilities are obtained with the framed GET_INFO
command. Keeping one USB identity simplifies OS and Web Serial permission
handling across FPGA reconfiguration.

| String | Value/requirement |
| --- | --- |
| Manufacturer | `NextMicon` |
| Product | `NextMicon Cherry` |
| Serial number | Stable and unique for one physical board |

Production VID/PID values are not allocated yet. Example or borrowed IDs must
not ship in a product. Until allocation, `nmb` can recognize the manufacturer
and product strings; `--usb-id VID:PID` provides an explicit filter.

The D+ pull-up remains disabled until the selected image has initialized USB.
For warm boot, the device finishes the response frame and its CDC IN transfer,
disables the pull-up, reconfigures, and enumerates again with the same identity.

## Wire framing

Each message is COBS encoded and terminated by one `0x00` byte:

```text
COBS(decoded frame) 00
```

COBS encoded data never contains zero, so a receiver can recover frame
boundaries after an error by scanning for the next `0x00`. USB read boundaries
have no protocol meaning; a read may contain a partial frame or several frames.

### Decoded frame

| Offset | Size | Field |
| ---: | ---: | --- |
| 0 | 1 | Protocol version, currently `0x01` |
| 1 | 1 | Channel |
| 2 | 1 | Opcode |
| 3 | 1 | Sequence number |
| 4 | 2 | Payload length, little-endian |
| 6 | 0-256 | Payload |
| 6+length | 4 | CRC-32/ISO-HDLC, little-endian |

CRC covers the six-byte header and payload, but not the CRC field, COBS
overhead, or trailing delimiter. Parameters are polynomial `0x04c11db7`,
initial value `0xffffffff`, reflected input/output, and final XOR
`0xffffffff`.

| Limit | Value |
| --- | ---: |
| Maximum payload | 256 bytes |
| Maximum decoded frame | 266 bytes |
| Maximum encoded frame including delimiter | 269 bytes |

A receiver silently discards an invalid COBS frame, unsupported version,
length mismatch, oversized frame, or CRC mismatch. It must continue scanning
at the next delimiter.

### Channels, opcodes, and sequencing

| Channel | Value | `boot` | `user` |
| --- | ---: | --- | --- |
| BOOT | `0x01` | Available | Available |
| FLASH | `0x02` | Available | Unavailable |
| UART | `0x03` | Unavailable | Available |

For BOOT and FLASH, the host sends only one request at a time. The response
copies the channel and sequence number and sets bit 7 of the request opcode:

```text
response opcode = request opcode | 0x80
```

The sequence number wraps modulo 256. It prevents a delayed or stale frame
from satisfying a newer request. UART DATA is unacknowledged; its sequence
number is diagnostic and may wrap independently.

## BOOT channel `0x01`

### GET_INFO `0x00`

Request payload is empty. Response opcode is `0x80` and its payload is:

| Offset | Size | Field |
| ---: | ---: | --- |
| 0 | 1 | BOOT status; `0x00` on success |
| 1 | 1 | Active image: `0` (`boot`) or `1` (`user`) |
| 2 | 1 | Capability bitmap |

Capability bits are `0x01` BOOT, `0x02` FLASH, and `0x04` UART. `boot` reports
`0x03`; `user` reports `0x05`. Reserved bits are zero.

### SELECT_IMAGE `0x01`

Request payload is one target-image byte: `0` for `boot` or `1` for `user`.
Values 2 through 255 are invalid. Response opcode is `0x81`; response payload
is one BOOT status byte.

| Status | Meaning |
| ---: | --- |
| `0x00` | Accepted |
| `0x01` | Invalid image or malformed payload |
| `0x02` | Destination manifest or CRC is invalid |
| `0x03` | Boot/flash manager is busy |

For Accepted, the complete response frame must reach the host before USB is
disconnected. The FPGA then quiesces QSPI, exits persistent QPI mode, raises
flash `/CS`, and asserts `SB_WARMBOOT`. A rejected command leaves the current
image running.

## FLASH channel `0x02`

Every FLASH response payload starts with one status byte.

| Status | Meaning |
| ---: | --- |
| `0x00` | Accepted/completed |
| `0x01` | Invalid or unavailable command |
| `0x02` | Invalid address, length, or slot |
| `0x03` | Write-protected region |
| `0x04` | Flash/boot manager busy |
| `0x05` | SPI flash I/O failure |

### ERASE_SLOT `0x01`

Request payload is the fixed user-slot byte `1`. Response opcode is `0x81` with
one status byte. On success, the complete 256 KiB user slot is erased and WIP
is clear before the response is sent. The boot region is always protected.

### WRITE `0x02`

| Payload offset | Size | Field |
| ---: | ---: | --- |
| 0 | 3 | 24-bit flash address, little-endian |
| 3 | 1-253 | Data |

Response opcode is `0x82` with one status byte. On success, all data is
programmed and WIP is clear before the response. The FPGA splits a frame at SPI
page boundaries when necessary. USB writes are restricted to the user image
(`0x040000-0x07ffff`). The boot region is protected in hardware.

### READ `0x03`

| Payload offset | Size | Field |
| ---: | ---: | --- |
| 0 | 3 | 24-bit flash address, little-endian |
| 3 | 2 | Requested length, little-endian (`1` through `255`) |

Response opcode is `0x83`. Its payload is status `0x00` followed by exactly the
requested bytes. The range must remain inside the 4 MiB main flash. `nmb`
verifies the complete bitstream and manifest through READ.

User-data erase/write commands are reserved for a future protocol revision.

## Image manifest

The final 32 bytes of the 256 KiB user image contain a manifest. Raw
bitstreams may be at most 262,112 bytes. The manifest is programmed last.

| Offset | Size | Field |
| ---: | ---: | --- |
| 0 | 4 | ASCII `NMF1` |
| 4 | 1 | Manifest version `1` |
| 5 | 1 | User image number, always `1` |
| 6 | 2 | Flags, zero |
| 8 | 4 | Bitstream length, little-endian |
| 12 | 4 | CRC-32/ISO-HDLC, little-endian |
| 16 | 16 | Reserved, all `0xff` |

Manifest CRC covers exactly the bitstream-length bytes from the slot base.
Erased padding and the manifest are excluded. BOOT validates magic, version,
image number, bounded nonzero length, and CRC before accepting a target.

## UART channel `0x03`

UART DATA opcode is `0x01`. Its payload contains 0 through 256 user bytes.
Frames in either direction are unacknowledged. Packet and frame boundaries
have no meaning to the user byte stream; bytes remain ordered and must not be
silently dropped. FIFO backpressure must propagate to the CDC Bulk endpoints.

The UART channel is not directly terminal-compatible because its bytes are
framed. A host console must add and remove UART frames. This prevents arbitrary
user data from ever being interpreted as a BOOT command.

## Native `nmb` workflow

`nmb` enumerates CDC ports, filters by USB identity or NextMicon strings, and
uses the stable serial number as `cherry-<serial>`.

```sh
nmb ls
nmb boot cherry-0123 user
nmb flash cherry-0123 image.bin --boot
```

Before flashing, `nmb` sends GET_INFO. If `user` is active, it requests `boot`,
waits for the same serial number to re-enumerate, confirms `boot` with GET_INFO,
then erases, writes, manifests, and reads back the user image. There is no
destination argument because only one user image exists.

## Web Serial flashing

`flash/web` is a pnpm-managed React and Tailwind CSS application. It compiles
the Rust protocol library used by `nmb` to WebAssembly, while JavaScript owns
Web Serial transport and UI state. No native USB driver is required. Browser
requirements and API behavior are defined by the
[Web Serial specification](https://wicg.github.io/serial/). It asks the user
for a serial port and opens the CDC port at the nominal baud rate:

```js
const port = await navigator.serial.requestPort();
await port.open({ baudRate: 115200, bufferSize: 4096 });
```

The application does the following:

1. reads arbitrary chunks from `port.readable` and splits them at `0x00`;
2. passes each frame to Rust WASM for COBS decoding and CRC checking;
3. matches management responses by channel, response opcode, and sequence;
4. selects a local bitstream with a file picker;
5. uses GET_INFO, SELECT_IMAGE, ERASE_SLOT, WRITE, and READ exactly as `nmb`;
6. closes readers/writers on disconnect and reopens after warm-boot enumeration.

Install dependencies and start Vite from a secure localhost context, then open
the displayed URL in a supporting Chromium-based browser:

```sh
cd flash/web
pnpm install
pnpm dev
```

`pnpm build` rebuilds the Rust WASM package and writes a production bundle to
`flash/web/dist`.

### WASM JSON boundary

The WASM library exports `encodeMessageJson`, `decodeMessageJson`, and `crc32`.
The first two functions convert between a complete wire frame and this JSON
representation:

```json
{"version":1,"channel":2,"opcode":3,"sequence":7,"payload":[0,0,4,255,0]}
```

All fields are required, unknown fields are rejected, and `payload` is an array
of byte values. `encodeMessageJson` returns COBS-encoded bytes with the trailing
`0x00`; `decodeMessageJson` validates COBS, length, version, channel, and CRC
before returning JSON. This keeps wire-format validation identical in `nmb`
and the browser.

Web Serial is available only in supporting browsers and secure contexts. Port
selection requires explicit user permission and normally a user gesture.
`navigator.serial.getPorts()` may return previously authorized ports, but a
browser may require the user to select the device again after disconnect. A
web flasher must detect this and present a reconnect action instead of assuming
automatic access.

The app waits up to 15 seconds for an already-authorized port with the same
USB VID/PID and confirms the active image using GET_INFO. If multiple boards
with the same USB identity are authorized, attach only the board being flashed
during automatic re-enumeration.

The web page cannot bypass device-side protection: `boot` remains unwritable,
addresses are checked by the FPGA, and every written byte is read back. The
bitstream can remain entirely local to the browser; uploading it to a server is
not required.

## Incomplete implementation items

- Production USB VID/PID allocation and final power descriptor
- FPGA USB Full-Speed physical/packet engine
- CDC ACM descriptors, standard requests, and notification endpoint
- COBS encoder/decoder and CRC32 frame engine in HDL
- BOOT/FLASH/UART channel dispatch and FIFOs in HDL
- Framed UART console command in `nmb`

These items must preserve the frame and flash formats defined here.

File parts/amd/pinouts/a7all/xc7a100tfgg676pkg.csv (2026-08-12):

Device/Package xc7a100tfgg676 6/6/2012 10:07:15
Pin | Pin Name | Memory Byte Group | Bank | VCCAUX Group | Super Logic Region | I/O Type | No-Connect
W10 | DONE_0 | NA | 0 | NA | NA | CONFIG | NA
H12 | TCK_0 | NA | 0 | NA | NA | CONFIG | NA
G14 | VCCBATT_0 | NA | 0 | NA | NA | CONFIG | NA
P11 | VN_0 | NA | 0 | NA | NA | CONFIG | NA
P12 | VREFP_0 | NA | 0 | NA | NA | CONFIG | NA
M11 | GNDADC_0 | NA | 0 | NA | NA | CONFIG | NA
M12 | VCCADC_0 | NA | 0 | NA | NA | CONFIG | NA
R12 | DXP_0 | NA | 0 | NA | NA | CONFIG | NA
H13 | CCLK_0 | NA | 0 | NA | NA | CONFIG | NA
N12 | VP_0 | NA | 0 | NA | NA | CONFIG | NA
N11 | VREFN_0 | NA | 0 | NA | NA | CONFIG | NA
R11 | DXN_0 | NA | 0 | NA | NA | CONFIG | NA
J10 | TDO_0 | NA | 0 | NA | NA | CONFIG | NA
H10 | TDI_0 | NA | 0 | NA | NA | CONFIG | NA
V11 | INIT_B_0 | NA | 0 | NA | NA | CONFIG | NA
Y9 | M1_0 | NA | 0 | NA | NA | CONFIG | NA
AB7 | M0_0 | NA | 0 | NA | NA | CONFIG | NA
H11 | TMS_0 | NA | 0 | NA | NA | CONFIG | NA
AE16 | PROGRAM_B_0 | NA | 0 | NA | NA | CONFIG | NA
AB15 | CFGBVS_0 | NA | 0 | NA | NA | CONFIG | NA
W9 | M2_0 | NA | 0 | NA | NA | CONFIG | NA
U24 | IO_0_13 | NA | 13 | NA | NA | HR | NA
U25 | IO_L1P_T0_13 | 0 | 13 | NA | NA | HR | NA
U26 | IO_L1N_T0_13 | 0 | 13 | NA | NA | HR | NA
V26 | IO_L2P_T0_13 | 0 | 13 | NA | NA | HR | NA
W26 | IO_L2N_T0_13 | 0 | 13 | NA | NA | HR | NA
AB26 | IO_L3P_T0_DQS_13 | 0 | 13 | NA | NA | HR | NA
AC26 | IO_L3N_T0_DQS_13 | 0 | 13 | NA | NA | HR | NA
W25 | IO_L4P_T0_13 | 0 | 13 | NA | NA | HR | NA
Y26 | IO_L4N_T0_13 | 0 | 13 | NA | NA | HR | NA
Y25 | IO_L5P_T0_13 | 0 | 13 | NA | NA | HR | NA
AA25 | IO_L5N_T0_13 | 0 | 13 | NA | NA | HR | NA
V24 | IO_L6P_T0_13 | 0 | 13 | NA | NA | HR | NA
W24 | IO_L6N_T0_VREF_13 | 0 | 13 | NA | NA | HR | NA
AA24 | IO_L7P_T1_13 | 1 | 13 | NA | NA | HR | NA
AB25 | IO_L7N_T1_13 | 1 | 13 | NA | NA | HR | NA
AA22 | IO_L8P_T1_13 | 1 | 13 | NA | NA | HR | NA
AA23 | IO_L8N_T1_13 | 1 | 13 | NA | NA | HR | NA
AB24 | IO_L9P_T1_DQS_13 | 1 | 13 | NA | NA | HR | NA
AC24 | IO_L9N_T1_DQS_13 | 1 | 13 | NA | NA | HR | NA
V23 | IO_L10P_T1_13 | 1 | 13 | NA | NA | HR | NA
W23 | IO_L10N_T1_13 | 1 | 13 | NA | NA | HR | NA
Y22 | IO_L11P_T1_SRCC_13 | 1 | 13 | NA | NA | HR | NA
Y23 | IO_L11N_T1_SRCC_13 | 1 | 13 | NA | NA | HR | NA
U22 | IO_L12P_T1_MRCC_13 | 1 | 13 | NA | NA | HR | NA
V22 | IO_L12N_T1_MRCC_13 | 1 | 13 | NA | NA | HR | NA
U21 | IO_L13P_T2_MRCC_13 | 2 | 13 | NA | NA | HR | NA
V21 | IO_L13N_T2_MRCC_13 | 2 | 13 | NA | NA | HR | NA
W21 | IO_L14P_T2_SRCC_13 | 2 | 13 | NA | NA | HR | NA
Y21 | IO_L14N_T2_SRCC_13 | 2 | 13 | NA | NA | HR | NA
T20 | IO_L15P_T2_DQS_13 | 2 | 13 | NA | NA | HR | NA
U20 | IO_L15N_T2_DQS_13 | 2 | 13 | NA | NA | HR | NA
W20 | IO_L16P_T2_13 | 2 | 13 | NA | NA | HR | NA
Y20 | IO_L16N_T2_13 | 2 | 13 | NA | NA | HR | NA
T19 | IO_L17P_T2_13 | 2 | 13 | NA | NA | HR | NA
U19 | IO_L17N_T2_13 | 2 | 13 | NA | NA | HR | NA
V19 | IO_L18P_T2_13 | 2 | 13 | NA | NA | HR | NA
W19 | IO_L18N_T2_13 | 2 | 13 | NA | NA | HR | NA
V18 | IO_L19P_T3_13 | 3 | 13 | NA | NA | HR | NA
W18 | IO_L19N_T3_VREF_13 | 3 | 13 | NA | NA | HR | NA
T14 | IO_L20P_T3_13 | 3 | 13 | NA | NA | HR | NA
T15 | IO_L20N_T3_13 | 3 | 13 | NA | NA | HR | NA
T17 | IO_L21P_T3_DQS_13 | 3 | 13 | NA | NA | HR | NA
T18 | IO_L21N_T3_DQS_13 | 3 | 13 | NA | NA | HR | NA
U15 | IO_L22P_T3_13 | 3 | 13 | NA | NA | HR | NA
U16 | IO_L22N_T3_13 | 3 | 13 | NA | NA | HR | NA
U14 | IO_L23P_T3_13 | 3 | 13 | NA | NA | HR | NA
V14 | IO_L23N_T3_13 | 3 | 13 | NA | NA | HR | NA
V16 | IO_L24P_T3_13 | 3 | 13 | NA | NA | HR | NA
V17 | IO_L24N_T3_13 | 3 | 13 | NA | NA | HR | NA
U17 | IO_25_13 | NA | 13 | NA | NA | HR | NA
M19 | IO_0_14 | NA | 14 | NA | NA | HR | NA
R14 | IO_L1P_T0_D00_MOSI_14 | 0 | 14 | NA | NA | HR | NA
R15 | IO_L1N_T0_D01_DIN_14 | 0 | 14 | NA | NA | HR | NA
P14 | IO_L2P_T0_D02_14 | 0 | 14 | NA | NA | HR | NA
N14 | IO_L2N_T0_D03_14 | 0 | 14 | NA | NA | HR | NA
P15 | IO_L3P_T0_DQS_PUDC_B_14 | 0 | 14 | NA | NA | HR | NA
P16 | IO_L3N_T0_DQS_EMCCLK_14 | 0 | 14 | NA | NA | HR | NA
N16 | IO_L4P_T0_D04_14 | 0 | 14 | NA | NA | HR | NA
N17 | IO_L4N_T0_D05_14 | 0 | 14 | NA | NA | HR | NA
R16 | IO_L5P_T0_D06_14 | 0 | 14 | NA | NA | HR | NA
R17 | IO_L5N_T0_D07_14 | 0 | 14 | NA | NA | HR | NA
P18 | IO_L6P_T0_FCS_B_14 | 0 | 14 | NA | NA | HR | NA
N18 | IO_L6N_T0_D08_VREF_14 | 0 | 14 | NA | NA | HR | NA
K25 | IO_L7P_T1_D09_14 | 1 | 14 | NA | NA | HR | NA
K26 | IO_L7N_T1_D10_14 | 1 | 14 | NA | NA | HR | NA
M20 | IO_L8P_T1_D11_14 | 1 | 14 | NA | NA | HR | NA
L20 | IO_L8N_T1_D12_14 | 1 | 14 | NA | NA | HR | NA
L24 | IO_L9P_T1_DQS_14 | 1 | 14 | NA | NA | HR | NA
L25 | IO_L9N_T1_DQS_D13_14 | 1 | 14 | NA | NA | HR | NA
M24 | IO_L10P_T1_D14_14 | 1 | 14 | NA | NA | HR | NA
M25 | IO_L10N_T1_D15_14 | 1 | 14 | NA | NA | HR | NA
L22 | IO_L11P_T1_SRCC_14 | 1 | 14 | NA | NA | HR | NA
L23 | IO_L11N_T1_SRCC_14 | 1 | 14 | NA | NA | HR | NA
M21 | IO_L12P_T1_MRCC_14 | 1 | 14 | NA | NA | HR | NA
M22 | IO_L12N_T1_MRCC_14 | 1 | 14 | NA | NA | HR | NA
N21 | IO_L13P_T2_MRCC_14 | 2 | 14 | NA | NA | HR | NA
N22 | IO_L13N_T2_MRCC_14 | 2 | 14 | NA | NA | HR | NA
P20 | IO_L14P_T2_SRCC_14 | 2 | 14 | NA | NA | HR | NA
P21 | IO_L14N_T2_SRCC_14 | 2 | 14 | NA | NA | HR | NA
N23 | IO_L15P_T2_DQS_RDWR_B_14 | 2 | 14 | NA | NA | HR | NA
N24 | IO_L15N_T2_DQS_DOUT_CSO_B_14 | 2 | 14 | NA | NA | HR | NA
P19 | IO_L16P_T2_CSI_B_14 | 2 | 14 | NA | NA | HR | NA
N19 | IO_L16N_T2_A15_D31_14 | 2 | 14 | NA | NA | HR | NA
P23 | IO_L17P_T2_A14_D30_14 | 2 | 14 | NA | NA | HR | NA
P24 | IO_L17N_T2_A13_D29_14 | 2 | 14 | NA | NA | HR | NA
R20 | IO_L18P_T2_A12_D28_14 | 2 | 14 | NA | NA | HR | NA
R21 | IO_L18N_T2_A11_D27_14 | 2 | 14 | NA | NA | HR | NA
R25 | IO_L19P_T3_A10_D26_14 | 3 | 14 | NA | NA | HR | NA
P25 | IO_L19N_T3_A09_D25_VREF_14 | 3 | 14 | NA | NA | HR | NA
N26 | IO_L20P_T3_A08_D24_14 | 3 | 14 | NA | NA | HR | NA
M26 | IO_L20N_T3_A07_D23_14 | 3 | 14 | NA | NA | HR | NA
T24 | IO_L21P_T3_DQS_14 | 3 | 14 | NA | NA | HR | NA
T25 | IO_L21N_T3_DQS_A06_D22_14 | 3 | 14 | NA | NA | HR | NA
R26 | IO_L22P_T3_A05_D21_14 | 3 | 14 | NA | NA | HR | NA
P26 | IO_L22N_T3_A04_D20_14 | 3 | 14 | NA | NA | HR | NA
T22 | IO_L23P_T3_A03_D19_14 | 3 | 14 | NA | NA | HR | NA
R22 | IO_L23N_T3_A02_D18_14 | 3 | 14 | NA | NA | HR | NA
T23 | IO_L24P_T3_A01_D17_14 | 3 | 14 | NA | NA | HR | NA
R23 | IO_L24N_T3_A00_D16_14 | 3 | 14 | NA | NA | HR | NA
R18 | IO_25_14 | NA | 14 | NA | NA | HR | NA
K18 | IO_0_15 | NA | 15 | NA | NA | HR | NA
K15 | IO_L1P_T0_AD0P_15 | 0 | 15 | NA | NA | HR | NA
J16 | IO_L1N_T0_AD0N_15 | 0 | 15 | NA | NA | HR | NA
J14 | IO_L2P_T0_AD8P_15 | 0 | 15 | NA | NA | HR | NA
J15 | IO_L2N_T0_AD8N_15 | 0 | 15 | NA | NA | HR | NA
K16 | IO_L3P_T0_DQS_AD1P_15 | 0 | 15 | NA | NA | HR | NA
K17 | IO_L3N_T0_DQS_AD1N_15 | 0 | 15 | NA | NA | HR | NA
M14 | IO_L4P_T0_15 | 0 | 15 | NA | NA | HR | NA
L14 | IO_L4N_T0_15 | 0 | 15 | NA | NA | HR | NA
M15 | IO_L5P_T0_AD9P_15 | 0 | 15 | NA | NA | HR | NA
L15 | IO_L5N_T0_AD9N_15 | 0 | 15 | NA | NA | HR | NA
M16 | IO_L6P_T0_15 | 0 | 15 | NA | NA | HR | NA
M17 | IO_L6N_T0_VREF_15 | 0 | 15 | NA | NA | HR | NA
J19 | IO_L7P_T1_AD2P_15 | 1 | 15 | NA | NA | HR | NA
H19 | IO_L7N_T1_AD2N_15 | 1 | 15 | NA | NA | HR | NA
L17 | IO_L8P_T1_AD10P_15 | 1 | 15 | NA | NA | HR | NA
L18 | IO_L8N_T1_AD10N_15 | 1 | 15 | NA | NA | HR | NA
K20 | IO_L9P_T1_DQS_AD3P_15 | 1 | 15 | NA | NA | HR | NA
J20 | IO_L9N_T1_DQS_AD3N_15 | 1 | 15 | NA | NA | HR | NA
J18 | IO_L10P_T1_AD11P_15 | 1 | 15 | NA | NA | HR | NA
H18 | IO_L10N_T1_AD11N_15 | 1 | 15 | NA | NA | HR | NA
G20 | IO_L11P_T1_SRCC_15 | 1 | 15 | NA | NA | HR | NA
G21 | IO_L11N_T1_SRCC_15 | 1 | 15 | NA | NA | HR | NA
K21 | IO_L12P_T1_MRCC_15 | 1 | 15 | NA | NA | HR | NA
J21 | IO_L12N_T1_MRCC_15 | 1 | 15 | NA | NA | HR | NA
H21 | IO_L13P_T2_MRCC_15 | 2 | 15 | NA | NA | HR | NA
H22 | IO_L13N_T2_MRCC_15 | 2 | 15 | NA | NA | HR | NA
J23 | IO_L14P_T2_SRCC_15 | 2 | 15 | NA | NA | HR | NA
H23 | IO_L14N_T2_SRCC_15 | 2 | 15 | NA | NA | HR | NA
G22 | IO_L15P_T2_DQS_15 | 2 | 15 | NA | NA | HR | NA
F22 | IO_L15N_T2_DQS_ADV_B_15 | 2 | 15 | NA | NA | HR | NA
J24 | IO_L16P_T2_A28_15 | 2 | 15 | NA | NA | HR | NA
H24 | IO_L16N_T2_A27_15 | 2 | 15 | NA | NA | HR | NA
F23 | IO_L17P_T2_A26_15 | 2 | 15 | NA | NA | HR | NA
E23 | IO_L17N_T2_A25_15 | 2 | 15 | NA | NA | HR | NA
K22 | IO_L18P_T2_A24_15 | 2 | 15 | NA | NA | HR | NA
K23 | IO_L18N_T2_A23_15 | 2 | 15 | NA | NA | HR | NA
G24 | IO_L19P_T3_A22_15 | 3 | 15 | NA | NA | HR | NA
F24 | IO_L19N_T3_A21_VREF_15 | 3 | 15 | NA | NA | HR | NA
E25 | IO_L20P_T3_A20_15 | 3 | 15 | NA | NA | HR | NA
D25 | IO_L20N_T3_A19_15 | 3 | 15 | NA | NA | HR | NA
E26 | IO_L21P_T3_DQS_15 | 3 | 15 | NA | NA | HR | NA
D26 | IO_L21N_T3_DQS_A18_15 | 3 | 15 | NA | NA | HR | NA
H26 | IO_L22P_T3_A17_15 | 3 | 15 | NA | NA | HR | NA
G26 | IO_L22N_T3_A16_15 | 3 | 15 | NA | NA | HR | NA
G25 | IO_L23P_T3_FOE_B_15 | 3 | 15 | NA | NA | HR | NA
F25 | IO_L23N_T3_FWE_B_15 | 3 | 15 | NA | NA | HR | NA
J25 | IO_L24P_T3_RS1_15 | 3 | 15 | NA | NA | HR | NA
J26 | IO_L24N_T3_RS0_15 | 3 | 15 | NA | NA | HR | NA
L19 | IO_25_15 | NA | 15 | NA | NA | HR | NA
H17 | IO_0_16 | NA | 16 | NA | NA | HR | NA
H14 | IO_L1P_T0_16 | 0 | 16 | NA | NA | HR | NA
H15 | IO_L1N_T0_16 | 0 | 16 | NA | NA | HR | NA
G17 | IO_L2P_T0_16 | 0 | 16 | NA | NA | HR | NA
F17 | IO_L2N_T0_16 | 0 | 16 | NA | NA | HR | NA
F18 | IO_L3P_T0_DQS_16 | 0 | 16 | NA | NA | HR | NA
F19 | IO_L3N_T0_DQS_16 | 0 | 16 | NA | NA | HR | NA
G15 | IO_L4P_T0_16 | 0 | 16 | NA | NA | HR | NA
F15 | IO_L4N_T0_16 | 0 | 16 | NA | NA | HR | NA
G19 | IO_L5P_T0_16 | 0 | 16 | NA | NA | HR | NA
F20 | IO_L5N_T0_16 | 0 | 16 | NA | NA | HR | NA
H16 | IO_L6P_T0_16 | 0 | 16 | NA | NA | HR | NA
G16 | IO_L6N_T0_VREF_16 | 0 | 16 | NA | NA | HR | NA
C17 | IO_L7P_T1_16 | 1 | 16 | NA | NA | HR | NA
B17 | IO_L7N_T1_16 | 1 | 16 | NA | NA | HR | NA
E16 | IO_L8P_T1_16 | 1 | 16 | NA | NA | HR | NA
D16 | IO_L8N_T1_16 | 1 | 16 | NA | NA | HR | NA
A17 | IO_L9P_T1_DQS_16 | 1 | 16 | NA | NA | HR | NA
A18 | IO_L9N_T1_DQS_16 | 1 | 16 | NA | NA | HR | NA
B19 | IO_L10P_T1_16 | 1 | 16 | NA | NA | HR | NA
A19 | IO_L10N_T1_16 | 1 | 16 | NA | NA | HR | NA
E17 | IO_L11P_T1_SRCC_16 | 1 | 16 | NA | NA | HR | NA
E18 | IO_L11N_T1_SRCC_16 | 1 | 16 | NA | NA | HR | NA
D18 | IO_L12P_T1_MRCC_16 | 1 | 16 | NA | NA | HR | NA
C18 | IO_L12N_T1_MRCC_16 | 1 | 16 | NA | NA | HR | NA
D19 | IO_L13P_T2_MRCC_16 | 2 | 16 | NA | NA | HR | NA
C19 | IO_L13N_T2_MRCC_16 | 2 | 16 | NA | NA | HR | NA
E20 | IO_L14P_T2_SRCC_16 | 2 | 16 | NA | NA | HR | NA
D20 | IO_L14N_T2_SRCC_16 | 2 | 16 | NA | NA | HR | NA
B20 | IO_L15P_T2_DQS_16 | 2 | 16 | NA | NA | HR | NA
A20 | IO_L15N_T2_DQS_16 | 2 | 16 | NA | NA | HR | NA
C21 | IO_L16P_T2_16 | 2 | 16 | NA | NA | HR | NA
B21 | IO_L16N_T2_16 | 2 | 16 | NA | NA | HR | NA
B22 | IO_L17P_T2_16 | 2 | 16 | NA | NA | HR | NA
A22 | IO_L17N_T2_16 | 2 | 16 | NA | NA | HR | NA
E21 | IO_L18P_T2_16 | 2 | 16 | NA | NA | HR | NA
D21 | IO_L18N_T2_16 | 2 | 16 | NA | NA | HR | NA
C22 | IO_L19P_T3_16 | 3 | 16 | NA | NA | HR | NA
C23 | IO_L19N_T3_VREF_16 | 3 | 16 | NA | NA | HR | NA
B25 | IO_L20P_T3_16 | 3 | 16 | NA | NA | HR | NA
A25 | IO_L20N_T3_16 | 3 | 16 | NA | NA | HR | NA
A23 | IO_L21P_T3_DQS_16 | 3 | 16 | NA | NA | HR | NA
A24 | IO_L21N_T3_DQS_16 | 3 | 16 | NA | NA | HR | NA
C26 | IO_L22P_T3_16 | 3 | 16 | NA | NA | HR | NA
B26 | IO_L22N_T3_16 | 3 | 16 | NA | NA | HR | NA
C24 | IO_L23P_T3_16 | 3 | 16 | NA | NA | HR | NA
B24 | IO_L23N_T3_16 | 3 | 16 | NA | NA | HR | NA
D23 | IO_L24P_T3_16 | 3 | 16 | NA | NA | HR | NA
D24 | IO_L24N_T3_16 | 3 | 16 | NA | NA | HR | NA
E22 | IO_25_16 | NA | 16 | NA | NA | HR | NA
N8 | IO_0_34 | NA | 34 | NA | NA | HR | NA
K3 | IO_L1P_T0_34 | 0 | 34 | NA | NA | HR | NA
J3 | IO_L1N_T0_34 | 0 | 34 | NA | NA | HR | NA
M7 | IO_L2P_T0_34 | 0 | 34 | NA | NA | HR | NA
L7 | IO_L2N_T0_34 | 0 | 34 | NA | NA | HR | NA
M4 | IO_L3P_T0_DQS_34 | 0 | 34 | NA | NA | HR | NA
L4 | IO_L3N_T0_DQS_34 | 0 | 34 | NA | NA | HR | NA
L5 | IO_L4P_T0_34 | 0 | 34 | NA | NA | HR | NA
K5 | IO_L4N_T0_34 | 0 | 34 | NA | NA | HR | NA
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

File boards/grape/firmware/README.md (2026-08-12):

# NextMicon Grape firmware

AMD Spartan-7 `XC7S50-1CSGA324C`向けのHDL、XDC制約ファイル、
フルOSSビルド設定をこのディレクトリで管理します。対象デバイスは
Project X-Rayの`xc7s50csga324-1`データベースを使用します。
実装はまだ未着手です。

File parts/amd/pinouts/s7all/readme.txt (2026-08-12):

*******************************************************************************
** © Copyright 2018 Xilinx, Inc. All rights reserved.
** This file contains confidential and proprietary information of Xilinx, Inc. and 
** is protected under U.S. and international copyright and other intellectual property laws.
*******************************************************************************
**   ____  ____ 
**  /   /\/   / 
** /___/  \  /   Vendor: Xilinx 
** \   \   \/    
**  \   \        readme.txt Version: 1.4
**  /   /        Date Last Modified: 08/10/18
** /___/   /\    Date Created: 12/05/16
** \   \  /  \   Associated Filename: s7all.zip
**  \___\/\___\ 
** 
**  Device: Spartan-7 FPGA
**  Revision History:
**	v1.0 (12/05/2016):	Initial release
**				Added x7s50csg324
**	v1.1 (01/25/2017):	Replaced x7s50csg324 with x7s50csga324
**				Added x7s50fgga484
**	v1.2 (09/26/2017):	Added packages:
**					xc7s100fgga484
**					xc7s100fgga676
**					xc7s25csga324
**					xc7s25ftgb196
**					xc7s50ftgb196
**					xc7s75fgga484
**					xc7s75fgga676
**				Updated packages:
**					xc7s50csga324
**					xc7s50fgga484
**	v1.3 (12/05/17):	Added packages:
**					xc7s25csga225
**					xc7s6cpga196
**					xc7s6csga225
**					xc7s6ftgb196
**					xc7s15cpga196
**					xc7s15csga225
**					xc7s15ftgb196
**				Updated packages:
**					xc7s25csga324
**					xc7s25ftgb196
**					xc7s50ftgb196
**	v1.4 (08/10/18):	Updated to Production:
**					xc7s100fgga484
**					xc7s100fgga676
**					xc7s15cpga196
**					xc7s15csga225
**					xc7s15ftgb196
**					xc7s6cpga196
**					xc7s6csga225
**					xc7s6ftgb196
**					xc7s75fgga484
**					xc7s75fgga676
*******************************************************************************
**
**  Disclaimer: 
**
**	This disclaimer is not a license and does not grant any rights to the materials 
**             	distributed herewith. Except as otherwise provided in a valid license issued to you 
**	by Xilinx, and to the maximum extent permitted by applicable law: 
**	(1) THESE MATERIALS ARE MADE AVAILABLE "AS IS" AND WITH ALL FAULTS, 
**	AND XILINX HEREBY DISCLAIMS ALL WARRANTIES AND CONDITIONS, EXPRESS, IMPLIED, OR STATUTORY, 
**	INCLUDING BUT NOT LIMITED TO WARRANTIES OF MERCHANTABILITY, NON-INFRINGEMENT, OR 
**	FITNESS FOR ANY PARTICULAR PURPOSE; and (2) Xilinx shall not be liable (whether in contract 
**	or tort, including negligence, or under any other theory of liability) for any loss or damage 
**	of any kind or nature related to, arising under or in connection with these materials, 
**	including for any direct, or any indirect, special, incidental, or consequential loss 
**	or damage (including loss of data, profits, goodwill, or any type of loss or damage suffered 
**	as a result of any action brought by a third party) even if such damage or loss was 
**	reasonably foreseeable or Xilinx had been advised of the possibility of the same.

**  Critical Applications:
**
**	Xilinx products are not designed or intended to be fail-safe, or for use in any application 
**	requiring fail-safe performance, such as life-support or safety devices or systems, 
**	Class III medical devices, nuclear facilities, applications related to the deployment of airbags,
**	or any other applications that could lead to death, personal injury, or severe property or 
**	environmental damage (individually and collectively, "Critical Applications"). Customer assumes 
**	the sole risk and liability of any use of Xilinx products in Critical Applications, subject only 
**	to applicable laws and regulations governing limitations on product liability.

**  THIS COPYRIGHT NOTICE AND DISCLAIMER MUST BE RETAINED AS PART OF THIS FILE AT ALL TIMES.

*******************************************************************************
** IMPORTANT NOTES **

1) These package files contain advance information and are subject to change without notice and are provided solely for information purposes.

2) Please refer to the Spartan-7 Package Files section of UG475, 7-Series Packaging and Pinouts, for detailed information on the contents of the package files.

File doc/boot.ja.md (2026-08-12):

# ブートシーケンス

[English](boot.md)

通信仕様：[CDCフラッシュ・プロトコル](flash.ja.md)

この文書はNextMicon Cherryのハードウェア、FPGAイメージ、ホストツールで共通となる
ブート動作を定義します。フラッシュ配置は、最終ビットストリームのサイズと`icemulti`での
確認が完了するまでは暫定です。

## イメージとコールドブート選択

W25Q32には、役割を固定した2個のFPGAイメージを格納します。

| `CBSEL0` | 役割 | 内容 | フレーム・チャンネル |
| ---: | --- | --- | --- |
| `0` | `boot` | 保護された書き込み・復旧用イメージ | BOOTとFLASH |
| `1` | `user` | ユーザーアプリケーション | BOOTとUART |

基板上のはんだジャンパーは `CBSEL0` です。オープンなら `boot` ブリッジすると `user` を選択します。ジャンパーの変更は次回の電源レール・リセット時に反映され、実行中のイメージには影響しません。`CBSEL1` はオプショナルでユーザイメージを増やせます。

## コールドブート

1. USB VBUSから給電します。`RESET`を離すと3.3 Vと1.2 Vのレギュレーターが有効になり、両電源レールが放電状態から立ち上がります。
2. iCE40のコンフィグレーション・コントローラーが、`0x000000`にあるコールドブート・アプレットとベクターテーブルを読み取ります。
3. `CBSEL[0:1]` をサンプリングしブートイメージを選択します。
4. 有効なコンフィグレーションのロード後、オープンドレインの `CDONE` がプルアップで High になります。
5. 選択されたイメージが 48 MHz の USB ロジックと D+ プルアップを有効にします。両イメージは同じ CDC ACM 識別情報とエンドポイント構成で列挙されます。

`boot` は橙色の `PROG` LEDを点灯し、ホストコマンドを無期限に待ちます。タイムアウトで `user` へ移行しません。`user` は `PROG` を消灯し、共通 BOOT マネージャーとフレーム化 UART バイトストリームを提供します。

## ブートに関係するUSBトランスポート

両イメージが 1 個の CDC ACM シリアル機能を公開します。EP1 IN は CDC 通知 EP2 OUT/IN はフレーム化バイトストリームです。

| チャンネル | `boot` | `user` |
| --- | --- | --- |
| BOOT（`0x01`）  | 利用可 | 利用可 |
| FLASH（`0x02`） | 利用可 | 利用不可 |
| UART（`0x03`）  | 利用不可 | 利用可 |

GET_INFOが実行中の役割とcapabilityを返します。USB descriptor、VID/PID、Product、
Serial Numberは両イメージで同じです。

## ホスト要求によるウォームブート

両イメージがBOOTサービスを実装します。ウォームブートは`SB_WARMBOOT`の内部入力
`S1:S0`を使い、はんだジャンパーを再サンプリングしません。`S1`は常に`0`、`S0`は
`boot`（`0`）または`user`（`1`）を選択します。

1. ホストが対象を1バイト含むBOOT SELECT_IMAGEを送信します。`0`は`boot`、`1`は
   `user`です。
2. 実行中のイメージが役割と、`user`の場合はマニフェストを検証します。

   | ステータス | 意味                          |
   | ---------: | ----------------------------- |
   |        `0` | 要求を受理                    |
   |        `1` | イメージ値またはpayloadが不正 |
   |        `2` | userマニフェストが不正        |
   |        `3` | マネージャーがビジー          |

3. 受理時はUSBやQSPIを停止する前に、レスポンス・フレームとCDC IN転送を完了します。
4. 新しいQSPI処理を禁止し、実行中処理とWIPビットのクリアを待ち、通常の1ビットSPI
   コマンドモードへ戻して`/CS`をHighにします。
5. USBを切断し、`S1=0`のまま対象を`S0`へ登録した後、`SB_WARMBOOT`をアサートします。
6. 選択されたイメージがロードされ、同じUSB識別情報で再列挙されます。

実行中と同じ役割を選択した場合も再起動します。ウォームブートは物理ジャンパーを変更しないため、次回の`RESET`では再びジャンパー値を使います。

## 開発時の書き込み手順

1. ジャンパーをオープンにして`RESET`を押し、`boot`を起動します。
2. FLASHチャンネルで唯一の`user`領域を消去し、ビットストリームとマニフェストを書き込みます。
3. マニフェスト、CRC、フラッシュreadbackを検証します。
4. SELECT_IMAGE `1`を送信し、受理後に`user`の再列挙を待ちます。
5. 再度書き込む場合はSELECT_IMAGE `0`を送り、`boot`の再列挙を待ちます。

USBから書き込めるFPGAイメージは`user`だけなので、ホストツールで書き込み先を指定する
必要はありません。

## フラッシュ配置

4 MiBのW25Q32を、2個の256 KiBイメージ領域と3.5 MiBのユーザーデータ領域に分割します。

| フラッシュ範囲 |  サイズ | 内容 | 書き込み方針 |
| --- | ---: | --- | --- |
| `0x000000-0x03FFFF` | 256 KiB | コールドブート・テーブルと保護された`boot` | 工場／復旧ツールのみ |
| `0x040000-0x07FFFF` | 256 KiB | `user`とマニフェスト | `boot`の書き込み機能のみ |
| `0x080000-0x3FFFFF` | 3.5 MiB | ユーザーデータ | 明示的なユーザーデータ操作のみ |

工場出荷用イメージは 256 KiB 境界に揃えて作成します。

```bash
icemulti -c -a18 -o factory.bin boot.bin user.bin
```

通常のUSB書き込みで`boot`を消去または書き換えてはいけません。コールドブートには通常の
SPIコマンド・フレーミングが必要なため、ユーザーコードはW25Q32を永続QPIモードのままに
してはいけません。

## RESET、外部書き込み、復旧

`RESET`は電源レール・リセットであり、`CRESET_B`を直接操作するリセットではありません。
押している間は`PWR_EN`で両レギュレーターを無効にし、離すと電源レールを再起動して
ジャンパーをサンプリングします。3.3 Vレールの外部給電は通常動作としてサポートしません。

`CRESET_B`はプルアップされ、工場書き込みと復旧用にJ5へ接続されています。

1. USB から給電し 3.3 V 対応 SPI プログラマーを J5 へ接続します。
2. `CRESET_B` を Low にして共有コンフィグレーション・ピンをハイインピーダンスにします。
3. `CS/SCK/MOSI/MISO` で工場出荷用イメージ全体を書き込みます。
4. `CRESET_B` を解放し通常のジャンパー選択によるコールドブートを行います。

`user` が不正、またはSELECT_IMAGE `0` を処理できない場合は、ジャンパーをオープンにして `RESET` を押します。`boot` またはコールドブート・テーブルが破損した場合は外部 SPI で復旧します。

## ブート時のハードウェア制約

- コールドブート中は SPI ピンを外部から駆動してはいけません。
- コンフィグレーション後は実行中イメージが6本のQSPI信号を使用し、ウォームブート前に停止する必要があります。
- FPGAのE10ボールは48 MHz発振器で駆動されるため、HDLではクロック入力にします。

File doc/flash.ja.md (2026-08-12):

# CDCフラッシュ・プロトコル

[English](flash.md)

この文書は NextMicon Cherry の FPGA イメージ、ホストツール`nmb`、Web Serialアプリケーションで共通に使用するシリアル・フレーム、ブート管理、フラッシュ書き込み、ユーザーデータ・チャンネルを定義します。マルチブート手順とフラッシュ配置は[boot.ja.md](boot.ja.md)を参照してください。

`flash/cli`のRustホストと`flash/web`の静的Web Serialアプリケーションは本プロトコルを実装済みです。Cherry HDLのCDC ACM USBエンジンとフレーム処理はまだ未実装です。

## トランスポート方式

すべてのイメージが同一のUSB CDC ACMシリアルデバイスとして列挙されます。BOOT、FLASH、UARTはフレーム化されたシリアル・バイトストリーム内の論理チャンネルであり、個別のUSBエンドポイントではありません。これにより、ネイティブアプリケーションはOS標準の
シリアルドライバーを使用でき、対応ブラウザではWeb Serialから書き込めます。

ストリームは常にフレーム化します。ユーザーUARTデータもUARTチャンネルのpayloadとして運び、再起動用エスケープシーケンスを検索しません。

## USB CDC ACMプロファイル

CherryはUSB VBUSから給電されるUSB 2.0 Full-Speedデバイスです。48 MHzのFPGAクロックを使用し、12 Mbit/sで動作します。

| 用途 | インターフェース／EP | 転送形式  | 最大パケット |
| --- | --- | --- | ---: |
| 標準／CDCリクエスト | EP0 | Control | 64バイト |
| CDC通知 | EP1 IN `0x81` | Interrupt | 16バイト |
| CDCシリアル・ホスト→FPGA | EP2 OUT `0x02` | Bulk | 64バイト |
| CDCシリアル・FPGA→ホスト | EP2 IN `0x82` | Bulk | 64バイト |

CDC機能はCommunication ClassインターフェースとData Classインターフェースを1個ずつ持ち、
Header、Call Management、ACM、Union Functional Descriptorを含みます。少なくとも次を
実装します。

- USB列挙とエンドポイントHALT復旧に必要な標準リクエスト
- `SET_LINE_CODING`と`GET_LINE_CODING`
- `SET_CONTROL_LINE_STATE`
- EP1 INによるCDC `SERIAL_STATE`通知

ホストの公称設定は115200 baud、8 data bits、no parity、1 stop bitです。同期USB
ストリームなのでbaud rateは実際の転送速度を制御しません。DTR、RTS、baud rate変更、
BREAKをイメージ選択やフラッシュ消去に使用してはいけません。

### 不変のデバイス識別情報

`boot`と`user`は同じVID、PID、Manufacturer、Product、Serial Numberを使用します。実行中の
イメージと利用可能機能はフレーム化GET_INFOコマンドで取得します。同じUSB識別情報を使う
ことで、FPGA再コンフィグレーションをまたぐOSとWeb Serialの権限処理を簡単にします。

| 文字列 | 値／要件 |
| --- | --- |
| Manufacturer  | `NextMicon` |
| Product | `NextMicon Cherry` |
| Serial Number | 物理基板ごとに一意かつ不変 |

製品用VID/PIDは未割当です。サンプル値や他製品のIDを使用したまま出荷してはいけません。
割当完了までは`nmb`がManufacturer／Product文字列から検出でき、
`--usb-id VID:PID`で明示的に限定できます。

選択イメージのUSB初期化が終わるまでD+プルアップを無効にします。ウォームブートでは応答
フレームとCDC IN転送を完了し、D+プルアップを無効にして再コンフィグレーションした後、
同じ識別情報で再列挙します。

## ワイヤ・フレーム

各メッセージをCOBSでエンコードし、末尾へ`0x00`を1バイト付けます。

```text
COBS(decoded frame) 00
```

COBSデータ内にはゼロが現れないため、受信エラー後も次の`0x00`を探してフレーム境界へ
復帰できます。USB readの区切りにプロトコル上の意味はなく、1回のreadにフレームの一部、
または複数フレームが含まれることがあります。

### デコード後のフレーム

| オフセット | サイズ | フィールド |
| ---: | -----: | --- |
| 0 | 1 | プロトコル・バージョン、現在`0x01`  |
| 1 | 1 | チャンネル |
| 2 | 1 | オペコード |
| 3 | 1 | シーケンス番号 |
| 4 | 2 | payload長、リトルエンディアン |
| 6 | 0～256 | payload |
| 6+length | 4 | CRC-32/ISO-HDLC、リトルエンディアン |

CRCの対象は6バイトのheaderとpayloadです。CRCフィールド、COBS overhead、末尾delimiterは
除外します。パラメーターは多項式`0x04c11db7`、初期値`0xffffffff`、入出力反転あり、
最終XOR`0xffffffff`です。

| 上限 | 値 |
| --- | ---: |
| 最大payload | 256バイト |
| 最大decoded frame | 266バイト |
| delimiterを含む最大encoded frame | 269バイト |

不正なCOBS、未対応version、length不一致、oversize、CRC不一致のフレームは応答せず破棄し、
次のdelimiterから受信を継続します。

### チャンネル、オペコード、シーケンス

| チャンネル | 値 | `boot` | `user` |
| --- | -----: | --- | --- |
| BOOT | `0x01` | 利用可 | 利用可 |
| FLASH | `0x02` | 利用可 | 利用不可 |
| UART | `0x03` | 利用不可  | 利用可 |

BOOTとFLASHでは、ホストは一度に1個だけリクエストを送ります。レスポンスは同じチャンネルと
シーケンス番号を持ち、リクエスト・オペコードのbit 7をセットします。

```text
response opcode = request opcode | 0x80
```

シーケンス番号は256でwrapし、古いレスポンスと新しいリクエストの誤対応を防ぎます。
UART DATAはACKなしで、独立してwrapできます。

## BOOTチャンネル`0x01`

### GET_INFO `0x00`

リクエストpayloadは空です。レスポンス・オペコードは`0x80`で、payloadは次の3バイトです。

| オフセット | サイズ | フィールド |
| ---: | -----: | --- |
| 0 | 1 | BOOT status、成功時`0x00` |
| 1 | 1 | 実行中イメージ：`0`（`boot`）または`1`（`user`） |
| 2 | 1 | capability bitmap |

Capability bitは`0x01` BOOT、`0x02` FLASH、`0x04` UARTです。`boot`は`0x03`、
`user`は`0x05`を返し、予約bitはゼロです。

### SELECT_IMAGE `0x01`

リクエストpayloadは対象イメージの1バイトで、`0`は`boot`、`1`は`user`です。2～255は
不正です。レスポンス・オペコードは`0x81`、payloadはBOOT statusの1バイトです。

| Status | 意味 |
| -----: | --- |
| `0x00` | Accepted |
| `0x01` | イメージまたはpayloadが不正 |
| `0x02` | 対象マニフェストまたはCRCが不正 |
| `0x03` | Boot／Flash managerがbusy |

Acceptedでは、完全なレスポンス・フレームをホストへ送ってからUSBを切断します。その後QSPIを
停止し、永続QPIモードを終了し、フラッシュ`/CS`をHighにして`SB_WARMBOOT`をアサートします。
拒否した場合は現在のイメージを継続します。

## FLASHチャンネル`0x02`

FLASHレスポンスpayloadの先頭は常にstatusです。

| Status | 意味 |
| -----: | --- |
| `0x00` | Accepted／完了 |
| `0x01` | 不正または利用不可のコマンド |
| `0x02` | アドレス、長さ、スロットが不正 |
| `0x03` | 書き込み保護領域 |
| `0x04` | Flash／Boot managerがbusy |
| `0x05` | SPIフラッシュI/O失敗 |

### ERASE_SLOT `0x01`

リクエストpayloadは固定のuserスロット値`1`です。レスポンス・オペコードは`0x81`で、statusを
1バイト返します。成功時は256 KiBのuser領域全体を消去し、WIPクリア後に応答します。
boot領域は常に保護します。

### WRITE `0x02`

| Payload offset | サイズ | フィールド |
| ---: | -----: | --- |
| 0 | 3 | 24ビット・フラッシュアドレス、リトルエンディアン |
| 3 | 1～253 | データ |

レスポンス・オペコードは`0x82`でstatusを1バイト返します。成功時は全データのprogramと
WIPクリア後に応答します。SPI page境界をまたぐ場合はFPGA内部で分割します。USB書き込みは
user（`0x040000-0x07ffff`）に限定し、boot領域はハードウェアで保護します。

### READ `0x03`

| Payload offset | サイズ | フィールド |
| ---: | -----: | --- |
| 0 | 3 | 24ビット・フラッシュアドレス、リトルエンディアン |
| 3 | 2 | 読み出し長、リトルエンディアン（`1`～`255`） |

レスポンス・オペコードは`0x83`です。payloadはstatus `0x00`と要求したデータで、4 MiBの
メインフラッシュ範囲を越えてはいけません。`nmb`はREADでビットストリームとマニフェスト
全体を検証します。ユーザーデータ領域の消去／書き込みは将来のrevisionへ予約します。

## イメージ・マニフェスト

256 KiBのuser領域の最後の32バイトをマニフェストに使用します。生の
ビットストリームは最大262,112バイトで、マニフェストを最後に書き込みます。

| オフセット | サイズ | フィールド |
| ---: | -----: | --- |
| 0 | 4 | ASCII `NMF1` |
| 4 | 1 | Manifest version `1` |
| 5 | 1 | userイメージ番号、常に`1` |
| 6 | 2 | Flags、ゼロ |
| 8 | 4 | ビットストリーム長、リトルエンディアン |
| 12 | 4 | CRC-32/ISO-HDLC、リトルエンディアン |
| 16 | 16 | 予約、すべて`0xff` |

Manifest CRCはスロット先頭からbitstream lengthで示すデータだけを対象とし、消去済みpaddingと
manifestは除外します。BOOTはmagic、version、image number、範囲内でゼロでないlength、CRCを
検証してから対象を受理します。

## UARTチャンネル`0x03`

UART DATAのオペコードは`0x01`で、payloadは0～256バイトです。双方向ともACKはありません。
packet／frame境界はユーザー・バイトストリーム上の意味を持たず、順序を維持して暗黙に
破棄してはいけません。FIFOのバックプレッシャーをCDC Bulkエンドポイントまで伝えます。

UARTデータもフレーム化されるため、シリアルターミナルを直接接続することはできません。
ホストconsoleがUARTフレームを付加／除去します。これにより任意のユーザーデータがBOOT
コマンドとして解釈されることを防ぎます。

## `nmb`による書き込み

`nmb`はCDCポートを列挙し、USB IDまたはNextMicon文字列で絞り込み、不変のSerial Numberを
`cherry-<serial>`として使用します。

```sh
nmb ls
nmb boot cherry-0123 user
nmb flash cherry-0123 image.bin --boot
```

書き込み前にGET_INFOを送ります。`user`が動作中なら`boot`を要求し、同じSerial Numberの
再列挙を待ち、GET_INFOで`boot`を確認してからerase、write、manifest、readbackを実行します。
user領域は一意なので書き込み先引数はありません。

## Web Serialによる書き込み

`flash/web`はpnpmで管理するReact／Tailwind CSSアプリケーションです。`nmb`と同じRust
プロトコルライブラリをWebAssemblyへコンパイルし、JavaScriptはWeb Serialトランスポートと
UI状態を管理します。ネイティブUSBドライバーは不要です。ブラウザ要件とAPI動作は
[Web Serial仕様](https://wicg.github.io/serial/)で定義されています。

```js
const port = await navigator.serial.requestPort();
await port.open({ baudRate: 115200, bufferSize: 4096 });
```

Webアプリケーションは次を実行します。

1. `port.readable`の任意サイズのchunkを`0x00`で分割します。
2. 各フレームをRust WASMへ渡し、COBS decodeとCRC確認を行います。
3. channel、response opcode、sequenceで管理レスポンスを対応付けます。
4. File Pickerでローカルのbitstreamを選択します。
5. `nmb`と同じGET_INFO、SELECT_IMAGE、ERASE_SLOT、WRITE、READを実行します。
6. 切断時にreader／writerを閉じ、ウォームブート後の再列挙でportを再度開きます。

依存関係をインストールし、Secure ContextになるlocalhostでViteを起動します。対応する
Chromium系ブラウザで表示されたURLを開きます。

```sh
cd flash/web
pnpm install
pnpm dev
```

`pnpm build`はRust WASMを再生成し、本番用bundleを`flash/web/dist`へ出力します。

### WASM JSON境界

WASMライブラリは`encodeMessageJson`、`decodeMessageJson`、`crc32`を公開します。先頭2関数は
完全なwire frameと次のJSON表現を相互変換します。

```json
{"version":1,"channel":2,"opcode":3,"sequence":7,"payload":[0,0,4,255,0]}
```

すべてのフィールドが必須で、未知のフィールドは拒否します。`payload`はbyte値の配列です。
`encodeMessageJson`は末尾`0x00`を含むCOBS encoded bytesを返します。
`decodeMessageJson`はCOBS、length、version、channel、CRCを検証してからJSONを返すため、
`nmb`とブラウザでwire format検証を共通化できます。

Web Serialは対応ブラウザかつSecure Contextでのみ利用できます。ポート選択には明示的な
ユーザー許可と通常はユーザー操作が必要です。`navigator.serial.getPorts()`から許可済み
ポートを取得できる場合がありますが、切断後に再選択が必要なブラウザ動作も考慮し、Web
flasherは自動アクセスを前提にせず「再接続」操作を表示します。

アプリは許可済みで同じUSB VID/PIDを持つportを最大15秒待ち、GET_INFOで実行中イメージを
確認します。同じUSB識別情報の基板を複数許可している場合、自動再列挙中は書き込み対象の
基板だけを接続してください。

Webページからもデバイス側保護は迂回できません。`boot`は書き込み不可で、FPGAが
アドレスを検証し、書き込んだ全バイトをreadbackします。bitstreamはブラウザ内だけで処理
でき、サーバーへのuploadは不要です。

## 未実装項目

- 製品用USB VID/PID割当と最終Power Descriptor
- FPGAのUSB Full-Speed物理層／packet engine
- CDC ACM descriptor、標準request、notification endpoint
- HDLのCOBS codecとCRC32 frame engine
- HDLのBOOT／FLASH／UART dispatchとFIFO
- `nmb`のフレーム化UART consoleコマンド

これらは本書のフレーム形式とフラッシュ形式を維持して実装します。

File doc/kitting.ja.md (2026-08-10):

# キッティング手順

## 1. USB -> QSPI 変換デバイスを用意する

## 2. 基板上のフラッシュピンと接続する

## 3. flash.nextmicon.com で書き込む

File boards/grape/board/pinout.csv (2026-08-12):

channel | signal | fpga_ball | fpga_pin_name | bank | connector | position | connector_pad | row | group
1 | GPIO_001 | G13 | IO_0_15 | 15 | J2 | 5 | 9 | inner | 1
2 | GPIO_002 | B13 | IO_L1P_T0_AD0P_15 | 15 | J2 | 6 | 11 | inner | 1
3 | GPIO_003 | A13 | IO_L1N_T0_AD0N_15 | 15 | J2 | 7 | 13 | inner | 1
4 | GPIO_004 | B14 | IO_L2P_T0_AD8P_15 | 15 | J2 | 8 | 15 | inner | 1
5 | GPIO_005 | A14 | IO_L2N_T0_AD8N_15 | 15 | J2 | 5 | 10 | outer | 1
6 | GPIO_006 | B15 | IO_L3P_T0_DQS_AD1P_15 | 15 | J2 | 6 | 12 | outer | 1
7 | GPIO_007 | A15 | IO_L3N_T0_DQS_AD1N_15 | 15 | J2 | 7 | 14 | outer | 1
8 | GPIO_008 | B16 | IO_L4P_T0_15 | 15 | J2 | 8 | 16 | outer | 1
9 | GPIO_009 | A16 | IO_L4N_T0_15 | 15 | J2 | 10 | 19 | inner | 2
10 | GPIO_010 | E12 | IO_L5P_T0_AD9P_15 | 15 | J2 | 11 | 21 | inner | 2
11 | GPIO_011 | D12 | IO_L5N_T0_AD9N_15 | 15 | J2 | 12 | 23 | inner | 2
12 | GPIO_012 | C13 | IO_L6P_T0_15 | 15 | J2 | 13 | 25 | inner | 2
13 | GPIO_013 | C14 | IO_L6N_T0_VREF_15 | 15 | J2 | 10 | 20 | outer | 2
14 | GPIO_014 | B17 | IO_L7P_T1_AD2P_15 | 15 | J2 | 11 | 22 | outer | 2
15 | GPIO_015 | A17 | IO_L7N_T1_AD2N_15 | 15 | J2 | 12 | 24 | outer | 2
16 | GPIO_016 | C17 | IO_L8P_T1_AD10P_15 | 15 | J2 | 13 | 26 | outer | 2
17 | GPIO_017 | B18 | IO_L8N_T1_AD10N_15 | 15 | J2 | 15 | 29 | inner | 3
18 | GPIO_018 | D16 | IO_L9P_T1_DQS_AD3P_15 | 15 | J2 | 16 | 31 | inner | 3
19 | GPIO_019 | D17 | IO_L9N_T1_DQS_AD3N_15 | 15 | J2 | 17 | 33 | inner | 3
20 | GPIO_020 | E16 | IO_L10P_T1_AD11P_15 | 15 | J2 | 18 | 35 | inner | 3
21 | GPIO_021 | E17 | IO_L10N_T1_AD11N_15 | 15 | J2 | 15 | 30 | outer | 3
22 | GPIO_022 | D18 | IO_L11P_T1_SRCC_15 | 15 | J2 | 16 | 32 | outer | 3
23 | GPIO_023 | C18 | IO_L11N_T1_SRCC_15 | 15 | J2 | 17 | 34 | outer | 3
24 | GPIO_024 | D14 | IO_L12P_T1_MRCC_15 | 15 | J2 | 18 | 36 | outer | 3
25 | GPIO_025 | D15 | IO_L12N_T1_MRCC_15 | 15 | J2 | 20 | 39 | inner | 4
26 | GPIO_026 | F14 | IO_L13P_T2_MRCC_15 | 15 | J2 | 21 | 41 | inner | 4
27 | GPIO_027 | F15 | IO_L13N_T2_MRCC_15 | 15 | J2 | 22 | 43 | inner | 4
28 | GPIO_028 | G16 | IO_L14P_T2_SRCC_15 | 15 | J2 | 23 | 45 | inner | 4
29 | GPIO_029 | G17 | IO_L14N_T2_SRCC_15 | 15 | J2 | 20 | 40 | outer | 4
30 | GPIO_030 | E14 | IO_L15P_T2_DQS_15 | 15 | J2 | 21 | 42 | outer | 4
31 | GPIO_031 | E15 | IO_L15N_T2_DQS_15 | 15 | J2 | 22 | 44 | outer | 4
32 | GPIO_032 | F18 | IO_L16P_T2_15 | 15 | J2 | 23 | 46 | outer | 4
33 | GPIO_033 | E18 | IO_L16N_T2_15 | 15 | J3 | 5 | 9 | inner | 5
34 | GPIO_034 | F13 | IO_L17P_T2_15 | 15 | J3 | 6 | 11 | inner | 5
35 | GPIO_035 | E13 | IO_L17N_T2_15 | 15 | J3 | 7 | 13 | inner | 5
36 | GPIO_036 | H15 | IO_L18P_T2_15 | 15 | J3 | 8 | 15 | inner | 5
37 | GPIO_037 | G15 | IO_L18N_T2_15 | 15 | J3 | 5 | 10 | outer | 5
38 | GPIO_038 | K16 | IO_L19P_T3_15 | 15 | J3 | 6 | 12 | outer | 5
39 | GPIO_039 | J16 | IO_L19N_T3_VREF_15 | 15 | J3 | 7 | 14 | outer | 5
40 | GPIO_040 | H13 | IO_L20P_T3_15 | 15 | J3 | 8 | 16 | outer | 5
41 | GPIO_041 | H14 | IO_L20N_T3_15 | 15 | J3 | 10 | 19 | inner | 6
42 | GPIO_042 | H18 | IO_L21P_T3_DQS_15 | 15 | J3 | 11 | 21 | inner | 6
43 | GPIO_043 | G18 | IO_L21N_T3_DQS_15 | 15 | J3 | 12 | 23 | inner | 6
44 | GPIO_044 | H16 | IO_L22P_T3_15 | 15 | J3 | 13 | 25 | inner | 6
45 | GPIO_045 | H17 | IO_L22N_T3_15 | 15 | J3 | 10 | 20 | outer | 6
46 | GPIO_046 | K14 | IO_L23P_T3_15 | 15 | J3 | 11 | 22 | outer | 6
47 | GPIO_047 | J15 | IO_L23N_T3_15 | 15 | J3 | 12 | 24 | outer | 6
48 | GPIO_048 | J13 | IO_L24P_T3_RS1_15 | 15 | J3 | 13 | 26 | outer | 6
49 | GPIO_049 | J14 | IO_L24N_T3_RS0_15 | 15 | J3 | 15 | 29 | inner | 7
50 | GPIO_050 | K13 | IO_25_15 | 15 | J3 | 16 | 31 | inner | 7
51 | GPIO_051 | J6 | IO_0_34 | 34 | J3 | 17 | 33 | inner | 7
52 | GPIO_052 | K4 | IO_L1P_T0_34 | 34 | J3 | 18 | 35 | inner | 7
53 | GPIO_053 | L4 | IO_L1N_T0_34 | 34 | J3 | 15 | 30 | outer | 7
54 | GPIO_054 | K3 | IO_L2P_T0_34 | 34 | J3 | 16 | 32 | outer | 7
55 | GPIO_055 | K2 | IO_L2N_T0_34 | 34 | J3 | 17 | 34 | outer | 7
56 | GPIO_056 | K1 | IO_L3P_T0_DQS_34 | 34 | J3 | 18 | 36 | outer | 7
57 | GPIO_057 | L1 | IO_L3N_T0_DQS_34 | 34 | J3 | 20 | 39 | inner | 8
58 | GPIO_058 | K6 | IO_L4P_T0_34 | 34 | J3 | 21 | 41 | inner | 8
59 | GPIO_059 | L6 | IO_L4N_T0_34 | 34 | J3 | 22 | 43 | inner | 8
60 | GPIO_060 | L5 | IO_L5P_T0_34 | 34 | J3 | 23 | 45 | inner | 8
61 | GPIO_061 | M4 | IO_L5N_T0_34 | 34 | J3 | 20 | 40 | outer | 8
62 | GPIO_062 | M6 | IO_L6P_T0_34 | 34 | J3 | 21 | 42 | outer | 8
63 | GPIO_063 | M5 | IO_L6N_T0_VREF_34 | 34 | J3 | 22 | 44 | outer | 8
64 | GPIO_064 | M3 | IO_L7P_T1_34 | 34 | J3 | 23 | 46 | outer | 8
65 | GPIO_065 | M2 | IO_L7N_T1_34 | 34 | J4 | 5 | 9 | inner | 9
66 | GPIO_066 | M1 | IO_L8P_T1_34 | 34 | J4 | 6 | 11 | inner | 9
67 | GPIO_067 | N1 | IO_L8N_T1_34 | 34 | J4 | 7 | 13 | inner | 9
68 | GPIO_068 | N3 | IO_L9P_T1_DQS_34 | 34 | J4 | 8 | 15 | inner | 9
69 | GPIO_069 | N2 | IO_L9N_T1_DQS_34 | 34 | J4 | 5 | 10 | outer | 9
70 | GPIO_070 | N5 | IO_L10P_T1_34 | 34 | J4 | 6 | 12 | outer | 9
71 | GPIO_071 | N4 | IO_L10N_T1_34 | 34 | J4 | 7 | 14 | outer | 9
72 | GPIO_072 | P2 | IO_L11P_T1_SRCC_34 | 34 | J4 | 8 | 16 | outer | 9
73 | GPIO_073 | P1 | IO_L11N_T1_SRCC_34 | 34 | J4 | 10 | 19 | inner | 10
74 | GPIO_074 | R2 | IO_L12P_T1_MRCC_34 | 34 | J4 | 11 | 21 | inner | 10
75 | GPIO_075 | R1 | IO_L12N_T1_MRCC_34 | 34 | J4 | 12 | 23 | inner | 10
76 | GPIO_076 | R3 | IO_L13P_T2_MRCC_34 | 34 | J4 | 13 | 25 | inner | 10
77 | GPIO_077 | T2 | IO_L13N_T2_MRCC_34 | 34 | J4 | 10 | 20 | outer | 10
78 | GPIO_078 | T1 | IO_L14P_T2_SRCC_34 | 34 | J4 | 11 | 22 | outer | 10
79 | GPIO_079 | U1 | IO_L14N_T2_SRCC_34 | 34 | J4 | 12 | 24 | outer | 10
80 | GPIO_080 | U3 | IO_L15P_T2_DQS_34 | 34 | J4 | 13 | 26 | outer | 10
81 | GPIO_081 | U2 | IO_L15N_T2_DQS_34 | 34 | J4 | 15 | 29 | inner | 11
82 | GPIO_082 | V3 | IO_L16P_T2_34 | 34 | J4 | 16 | 31 | inner | 11
83 | GPIO_083 | V2 | IO_L16N_T2_34 | 34 | J4 | 17 | 33 | inner | 11
84 | GPIO_084 | V5 | IO_L17P_T2_34 | 34 | J4 | 18 | 35 | inner | 11
85 | GPIO_085 | V4 | IO_L17N_T2_34 | 34 | J4 | 15 | 30 | outer | 11
86 | GPIO_086 | R4 | IO_L18P_T2_34 | 34 | J4 | 16 | 32 | outer | 11
87 | GPIO_087 | T3 | IO_L18N_T2_34 | 34 | J4 | 17 | 34 | outer | 11
88 | GPIO_088 | P6 | IO_L19P_T3_34 | 34 | J4 | 18 | 36 | outer | 11
89 | GPIO_089 | P5 | IO_L19N_T3_VREF_34 | 34 | J4 | 20 | 39 | inner | 12
90 | GPIO_090 | V7 | IO_L20P_T3_34 | 34 | J4 | 21 | 41 | inner | 12
91 | GPIO_091 | V6 | IO_L20N_T3_34 | 34 | J4 | 22 | 43 | inner | 12
92 | GPIO_092 | R5 | IO_L21P_T3_DQS_34 | 34 | J4 | 23 | 45 | inner | 12
93 | GPIO_093 | T4 | IO_L21N_T3_DQS_34 | 34 | J4 | 20 | 40 | outer | 12
94 | GPIO_094 | T6 | IO_L22P_T3_34 | 34 | J4 | 21 | 42 | outer | 12
95 | GPIO_095 | T5 | IO_L22N_T3_34 | 34 | J4 | 22 | 44 | outer | 12
96 | GPIO_096 | R7 | IO_L23P_T3_34 | 34 | J4 | 23 | 46 | outer | 12
97 | GPIO_097 | R6 | IO_L23N_T3_34 | 34 | J5 | 5 | 9 | inner | 13
98 | GPIO_098 | U7 | IO_L24P_T3_34 | 34 | J5 | 6 | 11 | inner | 13
99 | GPIO_099 | U6 | IO_L24N_T3_34 | 34 | J5 | 7 | 13 | inner | 13
100 | GPIO_100 | P7 | IO_25_34 | 34 | J5 | 8 | 15 | inner | 13
101 | GPIO_101 | F6 | IO_0_35 | 35 | J5 | 5 | 10 | outer | 13
102 | GPIO_102 | A8 | IO_L1P_T0_AD4P_35 | 35 | J5 | 6 | 12 | outer | 13
103 | GPIO_103 | A7 | IO_L1N_T0_AD4N_35 | 35 | J5 | 7 | 14 | outer | 13
104 | GPIO_104 | C5 | IO_L2P_T0_AD12P_35 | 35 | J5 | 8 | 16 | outer | 13
105 | GPIO_105 | B5 | IO_L2N_T0_AD12N_35 | 35 | J5 | 10 | 19 | inner | 14
106 | GPIO_106 | D7 | IO_L3P_T0_DQS_AD5P_35 | 35 | J5 | 11 | 21 | inner | 14
107 | GPIO_107 | C7 | IO_L3N_T0_DQS_AD5N_35 | 35 | J5 | 12 | 23 | inner | 14
108 | GPIO_108 | B7 | IO_L4P_T0_35 | 35 | J5 | 13 | 25 | inner | 14
109 | GPIO_109 | A6 | IO_L4N_T0_35 | 35 | J5 | 10 | 20 | outer | 14
110 | GPIO_110 | E6 | IO_L5P_T0_AD13P_35 | 35 | J5 | 11 | 22 | outer | 14
111 | GPIO_111 | D6 | IO_L5N_T0_AD13N_35 | 35 | J5 | 12 | 24 | outer | 14
112 | GPIO_112 | E5 | IO_L6P_T0_35 | 35 | J5 | 13 | 26 | outer | 14
113 | GPIO_113 | D5 | IO_L6N_T0_VREF_35 | 35 | J5 | 15 | 29 | inner | 15
114 | GPIO_114 | C4 | IO_L7P_T1_AD6P_35 | 35 | J5 | 16 | 31 | inner | 15
115 | GPIO_115 | B4 | IO_L7N_T1_AD6N_35 | 35 | J5 | 17 | 33 | inner | 15
116 | GPIO_116 | C3 | IO_L8P_T1_AD14P_35 | 35 | J5 | 18 | 35 | inner | 15
117 | GPIO_117 | B3 | IO_L8N_T1_AD14N_35 | 35 | J5 | 15 | 30 | outer | 15
118 | GPIO_118 | A5 | IO_L9P_T1_DQS_AD7P_35 | 35 | J5 | 16 | 32 | outer | 15
119 | GPIO_119 | A4 | IO_L9N_T1_DQS_AD7N_35 | 35 | J5 | 17 | 34 | outer | 15
120 | GPIO_120 | A3 | IO_L10P_T1_AD15P_35 | 35 | J5 | 18 | 36 | outer | 15
121 | GPIO_121 | A2 | IO_L10N_T1_AD15N_35 | 35 | J5 | 20 | 39 | inner | 16
122 | GPIO_122 | C2 | IO_L11P_T1_SRCC_35 | 35 | J5 | 21 | 41 | inner | 16
123 | GPIO_123 | B2 | IO_L11N_T1_SRCC_35 | 35 | J5 | 22 | 43 | inner | 16
124 | GPIO_124 | C1 | IO_L12P_T1_MRCC_35 | 35 | J5 | 23 | 45 | inner | 16
125 | GPIO_125 | B1 | IO_L12N_T1_MRCC_35 | 35 | J5 | 20 | 40 | outer | 16
126 | GPIO_126 | F4 | IO_L13P_T2_MRCC_35 | 35 | J5 | 21 | 42 | outer | 16
127 | GPIO_127 | E4 | IO_L13N_T2_MRCC_35 | 35 | J5 | 22 | 44 | outer | 16
128 | GPIO_128 | E1 | IO_L14P_T2_SRCC_35 | 35 | J5 | 23 | 46 | outer | 16

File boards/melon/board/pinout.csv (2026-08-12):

channel | signal | fpga_ball | fpga_pin_name | bank | connector | position | connector_pad | row | group
1 | GPIO_001 | U24 | IO_0_13 | 13 | J2 | 5 | 9 | inner | 1
2 | GPIO_002 | U25 | IO_L1P_T0_13 | 13 | J2 | 6 | 11 | inner | 1
3 | GPIO_003 | U26 | IO_L1N_T0_13 | 13 | J2 | 7 | 13 | inner | 1
4 | GPIO_004 | V26 | IO_L2P_T0_13 | 13 | J2 | 8 | 15 | inner | 1
5 | GPIO_005 | W26 | IO_L2N_T0_13 | 13 | J2 | 5 | 10 | outer | 1
6 | GPIO_006 | AB26 | IO_L3P_T0_DQS_13 | 13 | J2 | 6 | 12 | outer | 1
7 | GPIO_007 | AC26 | IO_L3N_T0_DQS_13 | 13 | J2 | 7 | 14 | outer | 1
8 | GPIO_008 | W25 | IO_L4P_T0_13 | 13 | J2 | 8 | 16 | outer | 1
9 | GPIO_009 | Y26 | IO_L4N_T0_13 | 13 | J2 | 10 | 19 | inner | 2
10 | GPIO_010 | Y25 | IO_L5P_T0_13 | 13 | J2 | 11 | 21 | inner | 2
11 | GPIO_011 | AA25 | IO_L5N_T0_13 | 13 | J2 | 12 | 23 | inner | 2
12 | GPIO_012 | V24 | IO_L6P_T0_13 | 13 | J2 | 13 | 25 | inner | 2
13 | GPIO_013 | W24 | IO_L6N_T0_VREF_13 | 13 | J2 | 10 | 20 | outer | 2
14 | GPIO_014 | AA24 | IO_L7P_T1_13 | 13 | J2 | 11 | 22 | outer | 2
15 | GPIO_015 | AB25 | IO_L7N_T1_13 | 13 | J2 | 12 | 24 | outer | 2
16 | GPIO_016 | AA22 | IO_L8P_T1_13 | 13 | J2 | 13 | 26 | outer | 2
17 | GPIO_017 | AA23 | IO_L8N_T1_13 | 13 | J2 | 15 | 29 | inner | 3
18 | GPIO_018 | AB24 | IO_L9P_T1_DQS_13 | 13 | J2 | 16 | 31 | inner | 3
19 | GPIO_019 | AC24 | IO_L9N_T1_DQS_13 | 13 | J2 | 17 | 33 | inner | 3
20 | GPIO_020 | V23 | IO_L10P_T1_13 | 13 | J2 | 18 | 35 | inner | 3
21 | GPIO_021 | W23 | IO_L10N_T1_13 | 13 | J2 | 15 | 30 | outer | 3
22 | GPIO_022 | Y22 | IO_L11P_T1_SRCC_13 | 13 | J2 | 16 | 32 | outer | 3
23 | GPIO_023 | Y23 | IO_L11N_T1_SRCC_13 | 13 | J2 | 17 | 34 | outer | 3
24 | GPIO_024 | U22 | IO_L12P_T1_MRCC_13 | 13 | J2 | 18 | 36 | outer | 3
25 | GPIO_025 | V22 | IO_L12N_T1_MRCC_13 | 13 | J2 | 20 | 39 | inner | 4
26 | GPIO_026 | U21 | IO_L13P_T2_MRCC_13 | 13 | J2 | 21 | 41 | inner | 4
27 | GPIO_027 | V21 | IO_L13N_T2_MRCC_13 | 13 | J2 | 22 | 43 | inner | 4
28 | GPIO_028 | W21 | IO_L14P_T2_SRCC_13 | 13 | J2 | 23 | 45 | inner | 4
29 | GPIO_029 | Y21 | IO_L14N_T2_SRCC_13 | 13 | J2 | 20 | 40 | outer | 4
30 | GPIO_030 | T20 | IO_L15P_T2_DQS_13 | 13 | J2 | 21 | 42 | outer | 4
31 | GPIO_031 | U20 | IO_L15N_T2_DQS_13 | 13 | J2 | 22 | 44 | outer | 4
32 | GPIO_032 | W20 | IO_L16P_T2_13 | 13 | J2 | 23 | 46 | outer | 4
33 | GPIO_033 | Y20 | IO_L16N_T2_13 | 13 | J3 | 5 | 9 | inner | 5
34 | GPIO_034 | T19 | IO_L17P_T2_13 | 13 | J3 | 6 | 11 | inner | 5
35 | GPIO_035 | U19 | IO_L17N_T2_13 | 13 | J3 | 7 | 13 | inner | 5
36 | GPIO_036 | V19 | IO_L18P_T2_13 | 13 | J3 | 8 | 15 | inner | 5
37 | GPIO_037 | W19 | IO_L18N_T2_13 | 13 | J3 | 5 | 10 | outer | 5
38 | GPIO_038 | V18 | IO_L19P_T3_13 | 13 | J3 | 6 | 12 | outer | 5
39 | GPIO_039 | W18 | IO_L19N_T3_VREF_13 | 13 | J3 | 7 | 14 | outer | 5
40 | GPIO_040 | T14 | IO_L20P_T3_13 | 13 | J3 | 8 | 16 | outer | 5
41 | GPIO_041 | T15 | IO_L20N_T3_13 | 13 | J3 | 10 | 19 | inner | 6
42 | GPIO_042 | T17 | IO_L21P_T3_DQS_13 | 13 | J3 | 11 | 21 | inner | 6
43 | GPIO_043 | T18 | IO_L21N_T3_DQS_13 | 13 | J3 | 12 | 23 | inner | 6
44 | GPIO_044 | U15 | IO_L22P_T3_13 | 13 | J3 | 13 | 25 | inner | 6
45 | GPIO_045 | U16 | IO_L22N_T3_13 | 13 | J3 | 10 | 20 | outer | 6
46 | GPIO_046 | U14 | IO_L23P_T3_13 | 13 | J3 | 11 | 22 | outer | 6
47 | GPIO_047 | V14 | IO_L23N_T3_13 | 13 | J3 | 12 | 24 | outer | 6
48 | GPIO_048 | V16 | IO_L24P_T3_13 | 13 | J3 | 13 | 26 | outer | 6
49 | GPIO_049 | V17 | IO_L24N_T3_13 | 13 | J3 | 15 | 29 | inner | 7
50 | GPIO_050 | U17 | IO_25_13 | 13 | J3 | 16 | 31 | inner | 7
51 | GPIO_051 | K18 | IO_0_15 | 15 | J3 | 17 | 33 | inner | 7
52 | GPIO_052 | K15 | IO_L1P_T0_AD0P_15 | 15 | J3 | 18 | 35 | inner | 7
53 | GPIO_053 | J16 | IO_L1N_T0_AD0N_15 | 15 | J3 | 15 | 30 | outer | 7
54 | GPIO_054 | J14 | IO_L2P_T0_AD8P_15 | 15 | J3 | 16 | 32 | outer | 7
55 | GPIO_055 | J15 | IO_L2N_T0_AD8N_15 | 15 | J3 | 17 | 34 | outer | 7
56 | GPIO_056 | K16 | IO_L3P_T0_DQS_AD1P_15 | 15 | J3 | 18 | 36 | outer | 7
57 | GPIO_057 | K17 | IO_L3N_T0_DQS_AD1N_15 | 15 | J3 | 20 | 39 | inner | 8
58 | GPIO_058 | M14 | IO_L4P_T0_15 | 15 | J3 | 21 | 41 | inner | 8
59 | GPIO_059 | L14 | IO_L4N_T0_15 | 15 | J3 | 22 | 43 | inner | 8
60 | GPIO_060 | M15 | IO_L5P_T0_AD9P_15 | 15 | J3 | 23 | 45 | inner | 8
61 | GPIO_061 | L15 | IO_L5N_T0_AD9N_15 | 15 | J3 | 20 | 40 | outer | 8
62 | GPIO_062 | M16 | IO_L6P_T0_15 | 15 | J3 | 21 | 42 | outer | 8
63 | GPIO_063 | M17 | IO_L6N_T0_VREF_15 | 15 | J3 | 22 | 44 | outer | 8
64 | GPIO_064 | J19 | IO_L7P_T1_AD2P_15 | 15 | J3 | 23 | 46 | outer | 8
65 | GPIO_065 | H19 | IO_L7N_T1_AD2N_15 | 15 | J4 | 5 | 9 | inner | 9
66 | GPIO_066 | L17 | IO_L8P_T1_AD10P_15 | 15 | J4 | 6 | 11 | inner | 9
67 | GPIO_067 | L18 | IO_L8N_T1_AD10N_15 | 15 | J4 | 7 | 13 | inner | 9
68 | GPIO_068 | K20 | IO_L9P_T1_DQS_AD3P_15 | 15 | J4 | 8 | 15 | inner | 9
69 | GPIO_069 | J20 | IO_L9N_T1_DQS_AD3N_15 | 15 | J4 | 5 | 10 | outer | 9
70 | GPIO_070 | J18 | IO_L10P_T1_AD11P_15 | 15 | J4 | 6 | 12 | outer | 9
71 | GPIO_071 | H18 | IO_L10N_T1_AD11N_15 | 15 | J4 | 7 | 14 | outer | 9
72 | GPIO_072 | G20 | IO_L11P_T1_SRCC_15 | 15 | J4 | 8 | 16 | outer | 9
73 | GPIO_073 | G21 | IO_L11N_T1_SRCC_15 | 15 | J4 | 10 | 19 | inner | 10
74 | GPIO_074 | K21 | IO_L12P_T1_MRCC_15 | 15 | J4 | 11 | 21 | inner | 10
75 | GPIO_075 | J21 | IO_L12N_T1_MRCC_15 | 15 | J4 | 12 | 23 | inner | 10
76 | GPIO_076 | H21 | IO_L13P_T2_MRCC_15 | 15 | J4 | 13 | 25 | inner | 10
77 | GPIO_077 | H22 | IO_L13N_T2_MRCC_15 | 15 | J4 | 10 | 20 | outer | 10
78 | GPIO_078 | J23 | IO_L14P_T2_SRCC_15 | 15 | J4 | 11 | 22 | outer | 10
79 | GPIO_079 | H23 | IO_L14N_T2_SRCC_15 | 15 | J4 | 12 | 24 | outer | 10
80 | GPIO_080 | G22 | IO_L15P_T2_DQS_15 | 15 | J4 | 13 | 26 | outer | 10
81 | GPIO_081 | F22 | IO_L15N_T2_DQS_ADV_B_15 | 15 | J4 | 15 | 29 | inner | 11
82 | GPIO_082 | J24 | IO_L16P_T2_A28_15 | 15 | J4 | 16 | 31 | inner | 11
83 | GPIO_083 | H24 | IO_L16N_T2_A27_15 | 15 | J4 | 17 | 33 | inner | 11
84 | GPIO_084 | F23 | IO_L17P_T2_A26_15 | 15 | J4 | 18 | 35 | inner | 11
85 | GPIO_085 | E23 | IO_L17N_T2_A25_15 | 15 | J4 | 15 | 30 | outer | 11
86 | GPIO_086 | K22 | IO_L18P_T2_A24_15 | 15 | J4 | 16 | 32 | outer | 11
87 | GPIO_087 | K23 | IO_L18N_T2_A23_15 | 15 | J4 | 17 | 34 | outer | 11
88 | GPIO_088 | G24 | IO_L19P_T3_A22_15 | 15 | J4 | 18 | 36 | outer | 11
89 | GPIO_089 | F24 | IO_L19N_T3_A21_VREF_15 | 15 | J4 | 20 | 39 | inner | 12
90 | GPIO_090 | E25 | IO_L20P_T3_A20_15 | 15 | J4 | 21 | 41 | inner | 12
91 | GPIO_091 | D25 | IO_L20N_T3_A19_15 | 15 | J4 | 22 | 43 | inner | 12
92 | GPIO_092 | E26 | IO_L21P_T3_DQS_15 | 15 | J4 | 23 | 45 | inner | 12
93 | GPIO_093 | D26 | IO_L21N_T3_DQS_A18_15 | 15 | J4 | 20 | 40 | outer | 12
94 | GPIO_094 | H26 | IO_L22P_T3_A17_15 | 15 | J4 | 21 | 42 | outer | 12
95 | GPIO_095 | G26 | IO_L22N_T3_A16_15 | 15 | J4 | 22 | 44 | outer | 12
96 | GPIO_096 | G25 | IO_L23P_T3_FOE_B_15 | 15 | J4 | 23 | 46 | outer | 12
97 | GPIO_097 | F25 | IO_L23N_T3_FWE_B_15 | 15 | J5 | 5 | 9 | inner | 13
98 | GPIO_098 | J25 | IO_L24P_T3_RS1_15 | 15 | J5 | 6 | 11 | inner | 13
99 | GPIO_099 | J26 | IO_L24N_T3_RS0_15 | 15 | J5 | 7 | 13 | inner | 13
100 | GPIO_100 | L19 | IO_25_15 | 15 | J5 | 8 | 15 | inner | 13
101 | GPIO_101 | H17 | IO_0_16 | 16 | J5 | 5 | 10 | outer | 13
102 | GPIO_102 | H14 | IO_L1P_T0_16 | 16 | J5 | 6 | 12 | outer | 13
103 | GPIO_103 | H15 | IO_L1N_T0_16 | 16 | J5 | 7 | 14 | outer | 13
104 | GPIO_104 | G17 | IO_L2P_T0_16 | 16 | J5 | 8 | 16 | outer | 13
105 | GPIO_105 | F17 | IO_L2N_T0_16 | 16 | J5 | 10 | 19 | inner | 14
106 | GPIO_106 | F18 | IO_L3P_T0_DQS_16 | 16 | J5 | 11 | 21 | inner | 14
107 | GPIO_107 | F19 | IO_L3N_T0_DQS_16 | 16 | J5 | 12 | 23 | inner | 14
108 | GPIO_108 | G15 | IO_L4P_T0_16 | 16 | J5 | 13 | 25 | inner | 14
109 | GPIO_109 | F15 | IO_L4N_T0_16 | 16 | J5 | 10 | 20 | outer | 14
110 | GPIO_110 | G19 | IO_L5P_T0_16 | 16 | J5 | 11 | 22 | outer | 14
111 | GPIO_111 | F20 | IO_L5N_T0_16 | 16 | J5 | 12 | 24 | outer | 14
112 | GPIO_112 | H16 | IO_L6P_T0_16 | 16 | J5 | 13 | 26 | outer | 14
113 | GPIO_113 | G16 | IO_L6N_T0_VREF_16 | 16 | J5 | 15 | 29 | inner | 15
114 | GPIO_114 | C17 | IO_L7P_T1_16 | 16 | J5 | 16 | 31 | inner | 15
115 | GPIO_115 | B17 | IO_L7N_T1_16 | 16 | J5 | 17 | 33 | inner | 15
116 | GPIO_116 | E16 | IO_L8P_T1_16 | 16 | J5 | 18 | 35 | inner | 15
117 | GPIO_117 | D16 | IO_L8N_T1_16 | 16 | J5 | 15 | 30 | outer | 15
118 | GPIO_118 | A17 | IO_L9P_T1_DQS_16 | 16 | J5 | 16 | 32 | outer | 15
119 | GPIO_119 | A18 | IO_L9N_T1_DQS_16 | 16 | J5 | 17 | 34 | outer | 15
120 | GPIO_120 | B19 | IO_L10P_T1_16 | 16 | J5 | 18 | 36 | outer | 15
121 | GPIO_121 | A19 | IO_L10N_T1_16 | 16 | J5 | 20 | 39 | inner | 16
122 | GPIO_122 | E17 | IO_L11P_T1_SRCC_16 | 16 | J5 | 21 | 41 | inner | 16
123 | GPIO_123 | E18 | IO_L11N_T1_SRCC_16 | 16 | J5 | 22 | 43 | inner | 16
124 | GPIO_124 | D18 | IO_L12P_T1_MRCC_16 | 16 | J5 | 23 | 45 | inner | 16
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

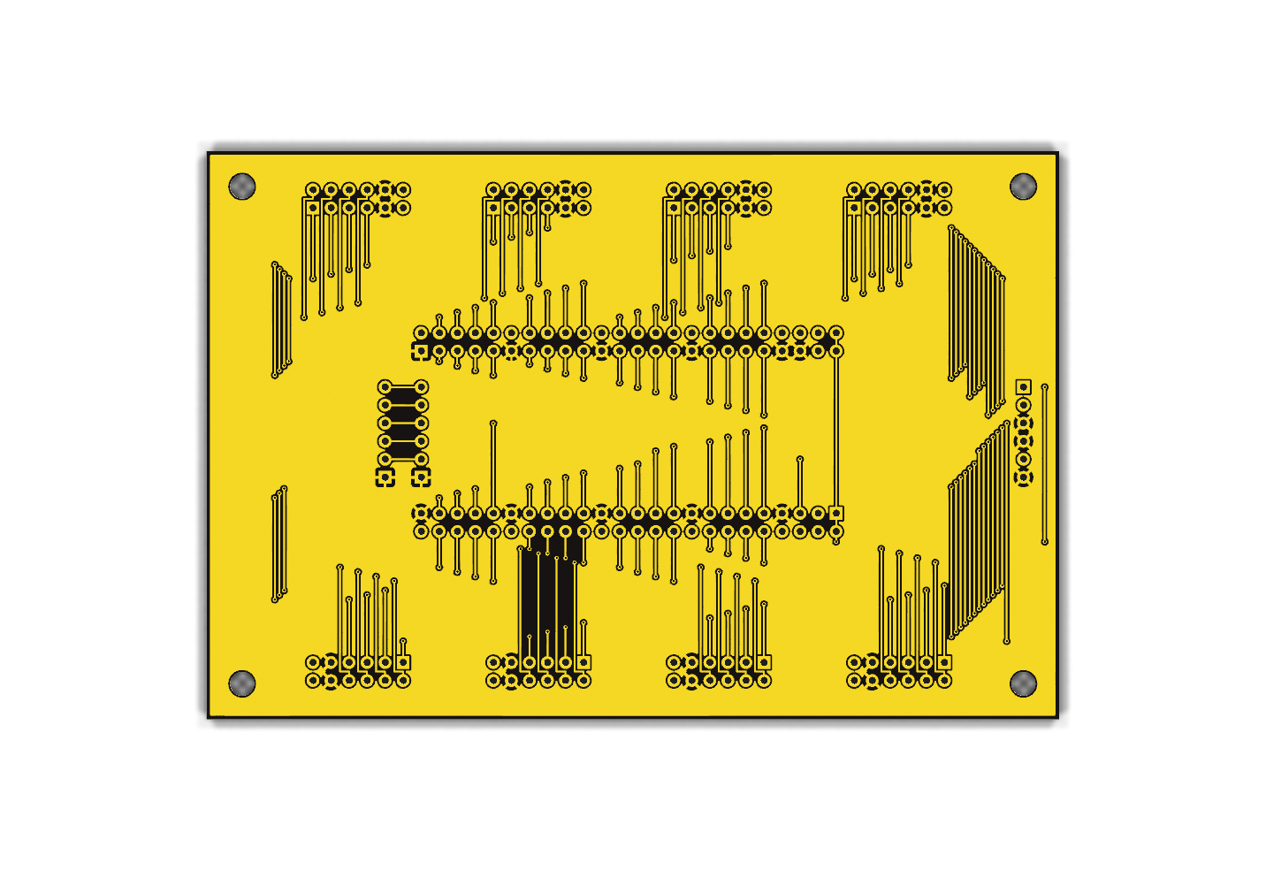
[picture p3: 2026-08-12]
boards/cherry/breakout/render/fixture-all-signal.png

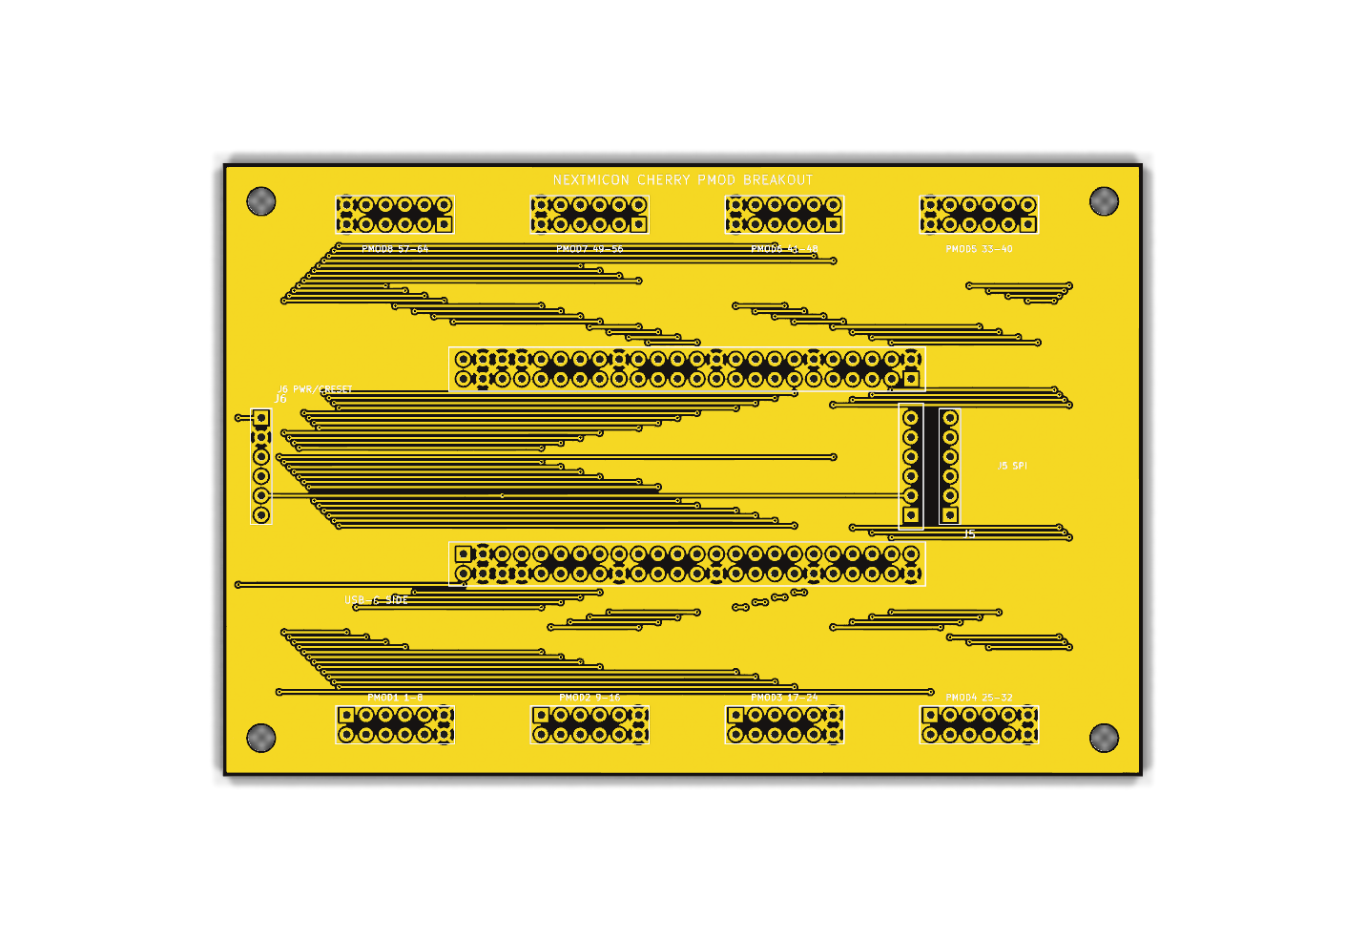
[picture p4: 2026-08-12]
boards/cherry/breakout/render/fixture.png

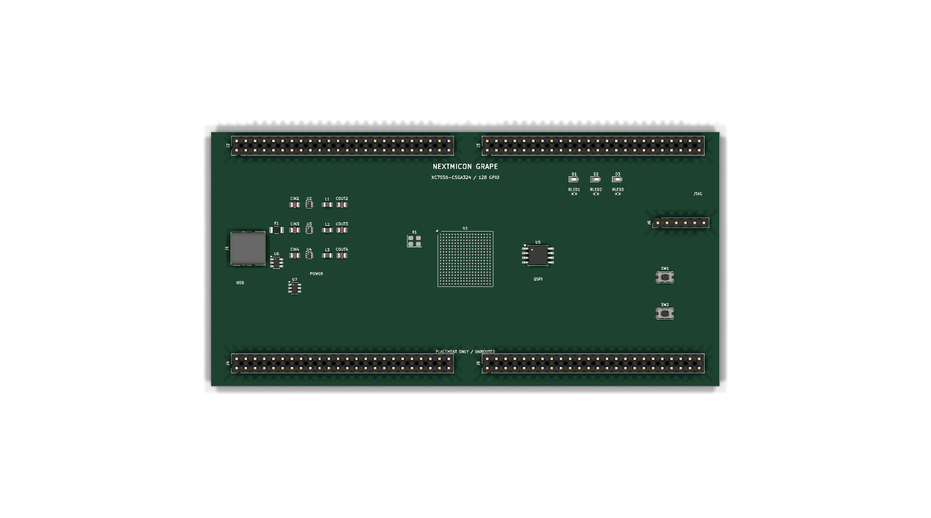
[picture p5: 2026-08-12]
boards/grape/board/grape-placement.png

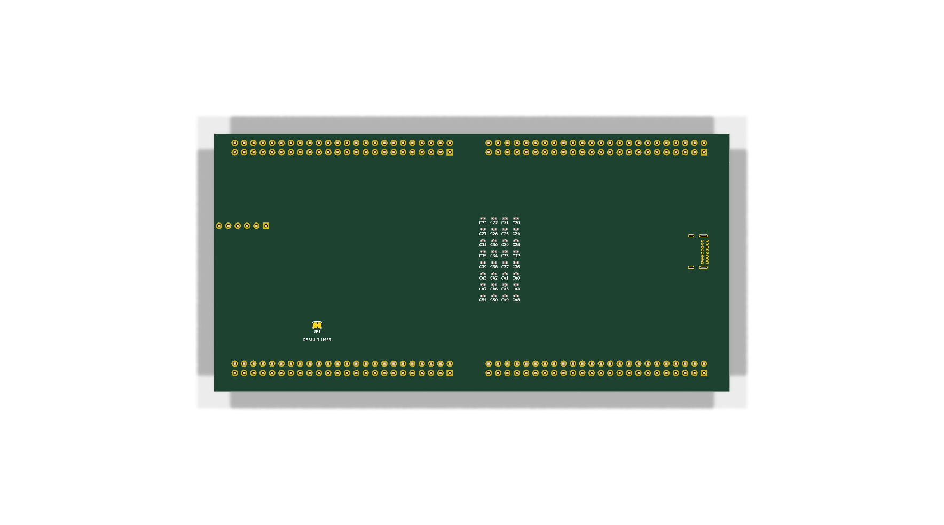
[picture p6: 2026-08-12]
boards/grape/board/grape-placement-back.png

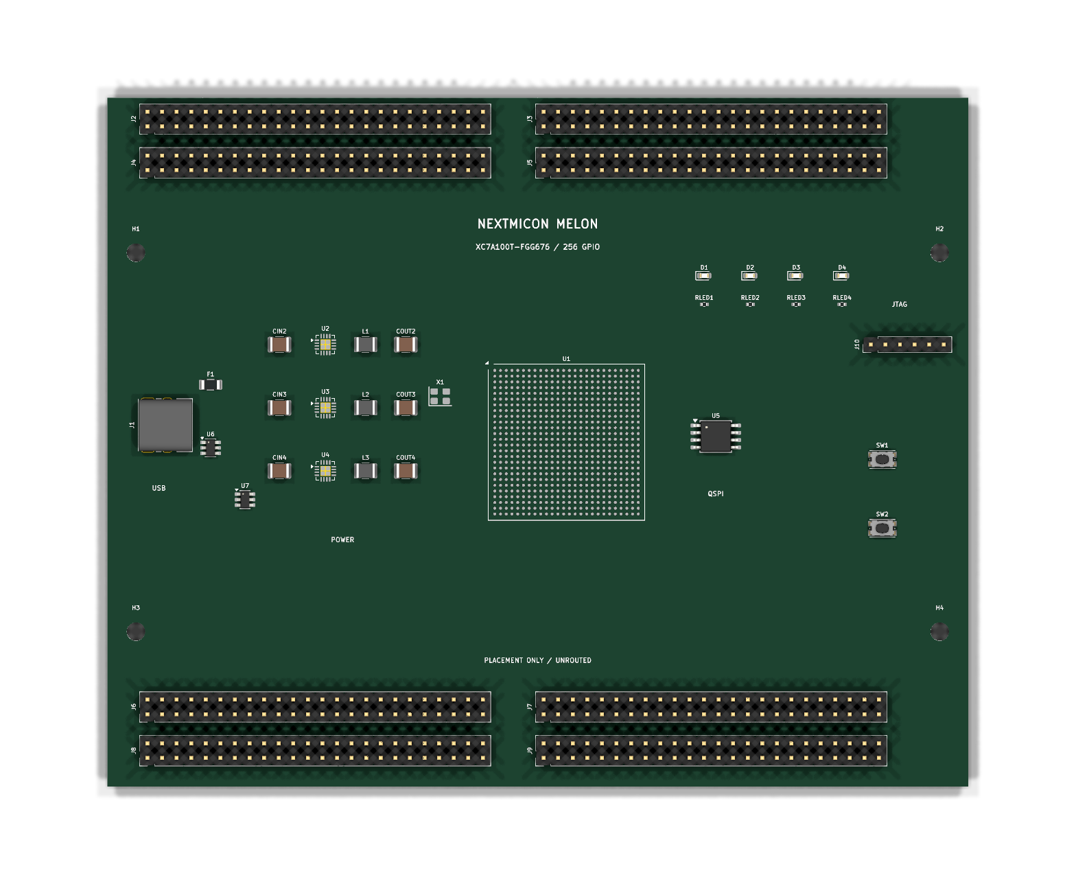
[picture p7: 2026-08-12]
boards/melon/board/melon-placement.png

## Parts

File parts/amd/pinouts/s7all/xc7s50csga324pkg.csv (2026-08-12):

# (c) Copyright 2016 Xilinx | Inc. All rights reserved.
#
# This file contains confidential and proprietary information
# of Xilinx | Inc. and is protected under U.S. and
# international copyright and other intellectual property
# laws.
#
# DISCLAIMER
# This disclaimer is not a license and does not grant any
# rights to the materials distributed herewith. Except as
# otherwise provided in a valid license issued to you by
# Xilinx | and to the maximum extent permitted by applicable
# law: (1) THESE MATERIALS ARE MADE AVAILABLE "AS IS" AND
# WITH ALL FAULTS | AND XILINX HEREBY DISCLAIMS ALL WARRANTIES
# AND CONDITIONS | EXPRESS | IMPLIED | OR STATUTORY | INCLUDING
# BUT NOT LIMITED TO WARRANTIES OF MERCHANTABILITY | NON-
# INFRINGEMENT | OR FITNESS FOR ANY PARTICULAR PURPOSE; and
# (2) Xilinx shall not be liable (whether in contract or tort
# including negligence | or under any other theory of
# liability) for any loss or damage of any kind or nature
# related to | arising under or in connection with these
# materials | including for any direct | or any indirect
# special | incidental | or consequential loss or damage
# (including loss of data | profits | goodwill | or any type of
# loss or damage suffered as a result of any action brought
# by a third party) even if such damage or loss was
# reasonably foreseeable or Xilinx had been advised of the
# possibility of the same.
#
# CRITICAL APPLICATIONS
# Xilinx products are not designed or intended to be fail-
# safe | or for use in any application requiring fail-safe
# performance | such as life-support or safety devices or
# systems | Class III medical devices | nuclear facilities
# applications related to the deployment of airbags | or any
# other applications that could lead to death | personal
# injury | or severe property or environmental damage
# (individually and collectively | "Critical
# Applications"). Customer assumes the sole risk and
# liability of any use of Xilinx products in Critical
# Applications | subject only to applicable laws and
# regulations governing limitations on product liability.
#
# THIS COPYRIGHT NOTICE AND DISCLAIMER MUST BE RETAINED AS
# PART OF THIS FILE AT ALL TIMES.
#
#----------------------------------------------------------------------
# ASCII Pinout File
#
# Device : xc7s50csga324
# Date : 7/13/2017 14:27:11
# Revision : 1.1
# Status : Production
#
# These package specifications are released coincident with production
# release of a particular device. Customers receive formal notification
# of any subsequent changes.
#
#----------------------------------------------------------------------
# Modification History
# | Date : 09/29/2016
# | Revision: 1.0
# | Status : Engineering Sample
# | Details : Initial creation.
#----------------------------------------------------------------------
# | Date : 05/04/2016
# | Revision: 1.1
# | Status : Production
# | Details : Status changed to Production
#----------------------------------------------------------------------
#----------------------------------------------------------------------
Pin | Pin Name | Memory Byte Group | Bank | VCCAUX Group | Super Logic Region | I/O Type | No-Connect
V8 | DONE_0 | NA | 0 | NA | NA | CONFIG | NA
L10 | DXP_0 | NA | 0 | NA | NA | CONFIG | NA
H9 | GNDADC_0 | NA | 0 | NA | NA | CONFIG | NA
H10 | VCCADC_0 | NA | 0 | NA | NA | CONFIG | NA
K10 | VREFP_0 | NA | 0 | NA | NA | CONFIG | NA
K9 | VN_0 | NA | 0 | NA | NA | CONFIG | NA
B8 | VCCBATT_0 | NA | 0 | NA | NA | CONFIG | NA
D9 | TCK_0 | NA | 0 | NA | NA | CONFIG | NA
L9 | DXN_0 | NA | 0 | NA | NA | CONFIG | NA
J9 | VREFN_0 | NA | 0 | NA | NA | CONFIG | NA
J10 | VP_0 | NA | 0 | NA | NA | CONFIG | NA
C8 | CCLK_0 | NA | 0 | NA | NA | CONFIG | NA
T10 | M0_0 | NA | 0 | NA | NA | CONFIG | NA
U10 | M1_0 | NA | 0 | NA | NA | CONFIG | NA
U8 | INIT_B_0 | NA | 0 | NA | NA | CONFIG | NA
R9 | TDI_0 | NA | 0 | NA | NA | CONFIG | NA
T8 | TDO_0 | NA | 0 | NA | NA | CONFIG | NA
U9 | M2_0 | NA | 0 | NA | NA | CONFIG | NA
V9 | CFGBVS_0 | NA | 0 | NA | NA | CONFIG | NA
R8 | PROGRAM_B_0 | NA | 0 | NA | NA | CONFIG | NA
T9 | TMS_0 | NA | 0 | NA | NA | CONFIG | NA
L13 | IO_0_14 | NA | 14 | NA | NA | HR | NA
K17 | IO_L1P_T0_D00_MOSI_14 | 0 | 14 | NA | NA | HR | NA
K18 | IO_L1N_T0_D01_DIN_14 | 0 | 14 | NA | NA | HR | NA
L14 | IO_L2P_T0_D02_14 | 0 | 14 | NA | NA | HR | NA
M15 | IO_L2N_T0_D03_14 | 0 | 14 | NA | NA | HR | NA
L15 | IO_L3P_T0_DQS_PUDC_B_14 | 0 | 14 | NA | NA | HR | NA
L16 | IO_L3N_T0_DQS_EMCCLK_14 | 0 | 14 | NA | NA | HR | NA
L17 | IO_L4P_T0_D04_14 | 0 | 14 | NA | NA | HR | NA
L18 | IO_L4N_T0_D05_14 | 0 | 14 | NA | NA | HR | NA
M14 | IO_L5P_T0_D06_14 | 0 | 14 | NA | NA | HR | NA
N14 | IO_L5N_T0_D07_14 | 0 | 14 | NA | NA | HR | NA
M13 | IO_L6P_T0_FCS_B_14 | 0 | 14 | NA | NA | HR | NA
N13 | IO_L6N_T0_D08_VREF_14 | 0 | 14 | NA | NA | HR | NA
M16 | IO_L7P_T1_D09_14 | 1 | 14 | NA | NA | HR | NA
M17 | IO_L7N_T1_D10_14 | 1 | 14 | NA | NA | HR | NA
M18 | IO_L8P_T1_D11_14 | 1 | 14 | NA | NA | HR | NA
N18 | IO_L8N_T1_D12_14 | 1 | 14 | NA | NA | HR | NA
P17 | IO_L9P_T1_DQS_14 | 1 | 14 | NA | NA | HR | NA
P18 | IO_L9N_T1_DQS_D13_14 | 1 | 14 | NA | NA | HR | NA
R18 | IO_L10P_T1_D14_14 | 1 | 14 | NA | NA | HR | NA
T18 | IO_L10N_T1_D15_14 | 1 | 14 | NA | NA | HR | NA
P14 | IO_L11P_T1_SRCC_14 | 1 | 14 | NA | NA | HR | NA
P15 | IO_L11N_T1_SRCC_14 | 1 | 14 | NA | NA | HR | NA
N15 | IO_L12P_T1_MRCC_14 | 1 | 14 | NA | NA | HR | NA
P16 | IO_L12N_T1_MRCC_14 | 1 | 14 | NA | NA | HR | NA
R14 | IO_L13P_T2_MRCC_14 | 2 | 14 | NA | NA | HR | NA
T14 | IO_L13N_T2_MRCC_14 | 2 | 14 | NA | NA | HR | NA
R16 | IO_L14P_T2_SRCC_14 | 2 | 14 | NA | NA | HR | NA
R17 | IO_L14N_T2_SRCC_14 | 2 | 14 | NA | NA | HR | NA
U17 | IO_L15P_T2_DQS_RDWR_B_14 | 2 | 14 | NA | NA | HR | NA
U18 | IO_L15N_T2_DQS_DOUT_CSO_B_14 | 2 | 14 | NA | NA | HR | NA
U16 | IO_L16P_T2_CSI_B_14 | 2 | 14 | NA | NA | HR | NA
V17 | IO_L16N_T2_D31_14 | 2 | 14 | NA | NA | HR | NA
R15 | IO_L17P_T2_D30_14 | 2 | 14 | NA | NA | HR | NA
T15 | IO_L17N_T2_D29_14 | 2 | 14 | NA | NA | HR | NA
U15 | IO_L18P_T2_D28_14 | 2 | 14 | NA | NA | HR | NA
V16 | IO_L18N_T2_D27_14 | 2 | 14 | NA | NA | HR | NA
P13 | IO_L19P_T3_D26_14 | 3 | 14 | NA | NA | HR | NA
R13 | IO_L19N_T3_D25_VREF_14 | 3 | 14 | NA | NA | HR | NA
V14 | IO_L20P_T3_D24_14 | 3 | 14 | NA | NA | HR | NA
V15 | IO_L20N_T3_D23_14 | 3 | 14 | NA | NA | HR | NA
U12 | IO_L21P_T3_DQS_14 | 3 | 14 | NA | NA | HR | NA
V13 | IO_L21N_T3_DQS_D22_14 | 3 | 14 | NA | NA | HR | NA
T12 | IO_L22P_T3_D21_14 | 3 | 14 | NA | NA | HR | NA
T13 | IO_L22N_T3_D20_14 | 3 | 14 | NA | NA | HR | NA
R11 | IO_L23P_T3_D19_14 | 3 | 14 | NA | NA | HR | NA
T11 | IO_L23N_T3_D18_14 | 3 | 14 | NA | NA | HR | NA
U11 | IO_L24P_T3_D17_14 | 3 | 14 | NA | NA | HR | NA
V12 | IO_L24N_T3_D16_14 | 3 | 14 | NA | NA | HR | NA
R12 | IO_25_14 | NA | 14 | NA | NA | HR | NA
G13 | IO_0_15 | NA | 15 | NA | NA | HR | NA
B13 | IO_L1P_T0_AD0P_15 | 0 | 15 | NA | NA | HR | NA
A13 | IO_L1N_T0_AD0N_15 | 0 | 15 | NA | NA | HR | NA
B14 | IO_L2P_T0_AD8P_15 | 0 | 15 | NA | NA | HR | NA
A14 | IO_L2N_T0_AD8N_15 | 0 | 15 | NA | NA | HR | NA
B15 | IO_L3P_T0_DQS_AD1P_15 | 0 | 15 | NA | NA | HR | NA
A15 | IO_L3N_T0_DQS_AD1N_15 | 0 | 15 | NA | NA | HR | NA
B16 | IO_L4P_T0_15 | 0 | 15 | NA | NA | HR | NA
A16 | IO_L4N_T0_15 | 0 | 15 | NA | NA | HR | NA
E12 | IO_L5P_T0_AD9P_15 | 0 | 15 | NA | NA | HR | NA
D12 | IO_L5N_T0_AD9N_15 | 0 | 15 | NA | NA | HR | NA
C13 | IO_L6P_T0_15 | 0 | 15 | NA | NA | HR | NA
C14 | IO_L6N_T0_VREF_15 | 0 | 15 | NA | NA | HR | NA
B17 | IO_L7P_T1_AD2P_15 | 1 | 15 | NA | NA | HR | NA
A17 | IO_L7N_T1_AD2N_15 | 1 | 15 | NA | NA | HR | NA
C17 | IO_L8P_T1_AD10P_15 | 1 | 15 | NA | NA | HR | NA
B18 | IO_L8N_T1_AD10N_15 | 1 | 15 | NA | NA | HR | NA
D16 | IO_L9P_T1_DQS_AD3P_15 | 1 | 15 | NA | NA | HR | NA
D17 | IO_L9N_T1_DQS_AD3N_15 | 1 | 15 | NA | NA | HR | NA
E16 | IO_L10P_T1_AD11P_15 | 1 | 15 | NA | NA | HR | NA
E17 | IO_L10N_T1_AD11N_15 | 1 | 15 | NA | NA | HR | NA
D18 | IO_L11P_T1_SRCC_15 | 1 | 15 | NA | NA | HR | NA
C18 | IO_L11N_T1_SRCC_15 | 1 | 15 | NA | NA | HR | NA
D14 | IO_L12P_T1_MRCC_15 | 1 | 15 | NA | NA | HR | NA
D15 | IO_L12N_T1_MRCC_15 | 1 | 15 | NA | NA | HR | NA
F14 | IO_L13P_T2_MRCC_15 | 2 | 15 | NA | NA | HR | NA
F15 | IO_L13N_T2_MRCC_15 | 2 | 15 | NA | NA | HR | NA
G16 | IO_L14P_T2_SRCC_15 | 2 | 15 | NA | NA | HR | NA
G17 | IO_L14N_T2_SRCC_15 | 2 | 15 | NA | NA | HR | NA
E14 | IO_L15P_T2_DQS_15 | 2 | 15 | NA | NA | HR | NA
E15 | IO_L15N_T2_DQS_15 | 2 | 15 | NA | NA | HR | NA
F18 | IO_L16P_T2_15 | 2 | 15 | NA | NA | HR | NA
E18 | IO_L16N_T2_15 | 2 | 15 | NA | NA | HR | NA
F13 | IO_L17P_T2_15 | 2 | 15 | NA | NA | HR | NA
E13 | IO_L17N_T2_15 | 2 | 15 | NA | NA | HR | NA
H15 | IO_L18P_T2_15 | 2 | 15 | NA | NA | HR | NA
G15 | IO_L18N_T2_15 | 2 | 15 | NA | NA | HR | NA
K16 | IO_L19P_T3_15 | 3 | 15 | NA | NA | HR | NA
J16 | IO_L19N_T3_VREF_15 | 3 | 15 | NA | NA | HR | NA
H13 | IO_L20P_T3_15 | 3 | 15 | NA | NA | HR | NA
H14 | IO_L20N_T3_15 | 3 | 15 | NA | NA | HR | NA
H18 | IO_L21P_T3_DQS_15 | 3 | 15 | NA | NA | HR | NA
G18 | IO_L21N_T3_DQS_15 | 3 | 15 | NA | NA | HR | NA
H16 | IO_L22P_T3_15 | 3 | 15 | NA | NA | HR | NA
H17 | IO_L22N_T3_15 | 3 | 15 | NA | NA | HR | NA
K14 | IO_L23P_T3_15 | 3 | 15 | NA | NA | HR | NA
J15 | IO_L23N_T3_15 | 3 | 15 | NA | NA | HR | NA
J13 | IO_L24P_T3_RS1_15 | 3 | 15 | NA | NA | HR | NA
J14 | IO_L24N_T3_RS0_15 | 3 | 15 | NA | NA | HR | NA
K13 | IO_25_15 | NA | 15 | NA | NA | HR | NA
D11 | IO_L6N_T0_VREF_16 | 0 | 16 | NA | NA | HR | 7S25T
C10 | IO_L11P_T1_SRCC_16 | 1 | 16 | NA | NA | HR | 7S25T
C9 | IO_L11N_T1_SRCC_16 | 1 | 16 | NA | NA | HR | 7S25T
A10 | IO_L12P_T1_MRCC_16 | 1 | 16 | NA | NA | HR | 7S25T
A9 | IO_L12N_T1_MRCC_16 | 1 | 16 | NA | NA | HR | 7S25T
C12 | IO_L13P_T2_MRCC_16 | 2 | 16 | NA | NA | HR | 7S25T
C11 | IO_L13N_T2_MRCC_16 | 2 | 16 | NA | NA | HR | 7S25T
B11 | IO_L14P_T2_SRCC_16 | 2 | 16 | NA | NA | HR | 7S25T
A11 | IO_L14N_T2_SRCC_16 | 2 | 16 | NA | NA | HR | 7S25T
D10 | IO_L19N_T3_VREF_16 | 3 | 16 | NA | NA | HR | 7S25T
J6 | IO_0_34 | NA | 34 | NA | NA | HR | NA
K4 | IO_L1P_T0_34 | 0 | 34 | NA | NA | HR | NA
L4 | IO_L1N_T0_34 | 0 | 34 | NA | NA | HR | NA
K3 | IO_L2P_T0_34 | 0 | 34 | NA | NA | HR | NA
K2 | IO_L2N_T0_34 | 0 | 34 | NA | NA | HR | NA
K1 | IO_L3P_T0_DQS_34 | 0 | 34 | NA | NA | HR | NA
L1 | IO_L3N_T0_DQS_34 | 0 | 34 | NA | NA | HR | NA
K6 | IO_L4P_T0_34 | 0 | 34 | NA | NA | HR | NA
L6 | IO_L4N_T0_34 | 0 | 34 | NA | NA | HR | NA
L5 | IO_L5P_T0_34 | 0 | 34 | NA | NA | HR | NA
M4 | IO_L5N_T0_34 | 0 | 34 | NA | NA | HR | NA
M6 | IO_L6P_T0_34 | 0 | 34 | NA | NA | HR | NA
M5 | IO_L6N_T0_VREF_34 | 0 | 34 | NA | NA | HR | NA
M3 | IO_L7P_T1_34 | 1 | 34 | NA | NA | HR | NA
M2 | IO_L7N_T1_34 | 1 | 34 | NA | NA | HR | NA
M1 | IO_L8P_T1_34 | 1 | 34 | NA | NA | HR | NA
N1 | IO_L8N_T1_34 | 1 | 34 | NA | NA | HR | NA
N3 | IO_L9P_T1_DQS_34 | 1 | 34 | NA | NA | HR | NA
N2 | IO_L9N_T1_DQS_34 | 1 | 34 | NA | NA | HR | NA
N5 | IO_L10P_T1_34 | 1 | 34 | NA | NA | HR | NA
N4 | IO_L10N_T1_34 | 1 | 34 | NA | NA | HR | NA
P2 | IO_L11P_T1_SRCC_34 | 1 | 34 | NA | NA | HR | NA
P1 | IO_L11N_T1_SRCC_34 | 1 | 34 | NA | NA | HR | NA
R2 | IO_L12P_T1_MRCC_34 | 1 | 34 | NA | NA | HR | NA
R1 | IO_L12N_T1_MRCC_34 | 1 | 34 | NA | NA | HR | NA
R3 | IO_L13P_T2_MRCC_34 | 2 | 34 | NA | NA | HR | NA
T2 | IO_L13N_T2_MRCC_34 | 2 | 34 | NA | NA | HR | NA
T1 | IO_L14P_T2_SRCC_34 | 2 | 34 | NA | NA | HR | NA
U1 | IO_L14N_T2_SRCC_34 | 2 | 34 | NA | NA | HR | NA
U3 | IO_L15P_T2_DQS_34 | 2 | 34 | NA | NA | HR | NA
U2 | IO_L15N_T2_DQS_34 | 2 | 34 | NA | NA | HR | NA
V3 | IO_L16P_T2_34 | 2 | 34 | NA | NA | HR | NA
V2 | IO_L16N_T2_34 | 2 | 34 | NA | NA | HR | NA
V5 | IO_L17P_T2_34 | 2 | 34 | NA | NA | HR | NA
V4 | IO_L17N_T2_34 | 2 | 34 | NA | NA | HR | NA
R4 | IO_L18P_T2_34 | 2 | 34 | NA | NA | HR | NA
T3 | IO_L18N_T2_34 | 2 | 34 | NA | NA | HR | NA
P6 | IO_L19P_T3_34 | 3 | 34 | NA | NA | HR | NA
P5 | IO_L19N_T3_VREF_34 | 3 | 34 | NA | NA | HR | NA
V7 | IO_L20P_T3_34 | 3 | 34 | NA | NA | HR | NA
V6 | IO_L20N_T3_34 | 3 | 34 | NA | NA | HR | NA
R5 | IO_L21P_T3_DQS_34 | 3 | 34 | NA | NA | HR | NA
T4 | IO_L21N_T3_DQS_34 | 3 | 34 | NA | NA | HR | NA
T6 | IO_L22P_T3_34 | 3 | 34 | NA | NA | HR | NA
T5 | IO_L22N_T3_34 | 3 | 34 | NA | NA | HR | NA
R7 | IO_L23P_T3_34 | 3 | 34 | NA | NA | HR | NA
R6 | IO_L23N_T3_34 | 3 | 34 | NA | NA | HR | NA
U7 | IO_L24P_T3_34 | 3 | 34 | NA | NA | HR | NA
U6 | IO_L24N_T3_34 | 3 | 34 | NA | NA | HR | NA
P7 | IO_25_34 | NA | 34 | NA | NA | HR | NA
F6 | IO_0_35 | NA | 35 | NA | NA | HR | 7S25T
A8 | IO_L1P_T0_AD4P_35 | 0 | 35 | NA | NA | HR | 7S25T
A7 | IO_L1N_T0_AD4N_35 | 0 | 35 | NA | NA | HR | 7S25T
C5 | IO_L2P_T0_AD12P_35 | 0 | 35 | NA | NA | HR | 7S25T
B5 | IO_L2N_T0_AD12N_35 | 0 | 35 | NA | NA | HR | 7S25T
D7 | IO_L3P_T0_DQS_AD5P_35 | 0 | 35 | NA | NA | HR | 7S25T
C7 | IO_L3N_T0_DQS_AD5N_35 | 0 | 35 | NA | NA | HR | 7S25T
B7 | IO_L4P_T0_35 | 0 | 35 | NA | NA | HR | 7S25T
A6 | IO_L4N_T0_35 | 0 | 35 | NA | NA | HR | 7S25T
E6 | IO_L5P_T0_AD13P_35 | 0 | 35 | NA | NA | HR | 7S25T
D6 | IO_L5N_T0_AD13N_35 | 0 | 35 | NA | NA | HR | 7S25T
E5 | IO_L6P_T0_35 | 0 | 35 | NA | NA | HR | 7S25T
D5 | IO_L6N_T0_VREF_35 | 0 | 35 | NA | NA | HR | 7S25T
C4 | IO_L7P_T1_AD6P_35 | 1 | 35 | NA | NA | HR | 7S25T
B4 | IO_L7N_T1_AD6N_35 | 1 | 35 | NA | NA | HR | 7S25T
C3 | IO_L8P_T1_AD14P_35 | 1 | 35 | NA | NA | HR | 7S25T
B3 | IO_L8N_T1_AD14N_35 | 1 | 35 | NA | NA | HR | 7S25T
A5 | IO_L9P_T1_DQS_AD7P_35 | 1 | 35 | NA | NA | HR | 7S25T
A4 | IO_L9N_T1_DQS_AD7N_35 | 1 | 35 | NA | NA | HR | 7S25T
A3 | IO_L10P_T1_AD15P_35 | 1 | 35 | NA | NA | HR | 7S25T
A2 | IO_L10N_T1_AD15N_35 | 1 | 35 | NA | NA | HR | 7S25T
C2 | IO_L11P_T1_SRCC_35 | 1 | 35 | NA | NA | HR | 7S25T
B2 | IO_L11N_T1_SRCC_35 | 1 | 35 | NA | NA | HR | 7S25T
C1 | IO_L12P_T1_MRCC_35 | 1 | 35 | NA | NA | HR | 7S25T
B1 | IO_L12N_T1_MRCC_35 | 1 | 35 | NA | NA | HR | 7S25T
F4 | IO_L13P_T2_MRCC_35 | 2 | 35 | NA | NA | HR | 7S25T
E4 | IO_L13N_T2_MRCC_35 | 2 | 35 | NA | NA | HR | 7S25T
E1 | IO_L14P_T2_SRCC_35 | 2 | 35 | NA | NA | HR | 7S25T
D1 | IO_L14N_T2_SRCC_35 | 2 | 35 | NA | NA | HR | 7S25T
F3 | IO_L15P_T2_DQS_35 | 2 | 35 | NA | NA | HR | 7S25T
E3 | IO_L15N_T2_DQS_35 | 2 | 35 | NA | NA | HR | 7S25T
E2 | IO_L16P_T2_35 | 2 | 35 | NA | NA | HR | 7S25T
D2 | IO_L16N_T2_35 | 2 | 35 | NA | NA | HR | 7S25T
G5 | IO_L17P_T2_35 | 2 | 35 | NA | NA | HR | 7S25T
F5 | IO_L17N_T2_35 | 2 | 35 | NA | NA | HR | 7S25T
F2 | IO_L18P_T2_35 | 2 | 35 | NA | NA | HR | 7S25T
F1 | IO_L18N_T2_35 | 2 | 35 | NA | NA | HR | 7S25T
J4 | IO_L19P_T3_35 | 3 | 35 | NA | NA | HR | 7S25T
J3 | IO_L19N_T3_VREF_35 | 3 | 35 | NA | NA | HR | 7S25T
H3 | IO_L20P_T3_35 | 3 | 35 | NA | NA | HR | 7S25T
H2 | IO_L20N_T3_35 | 3 | 35 | NA | NA | HR | 7S25T
G2 | IO_L21P_T3_DQS_35 | 3 | 35 | NA | NA | HR | 7S25T
G1 | IO_L21N_T3_DQS_35 | 3 | 35 | NA | NA | HR | 7S25T
H5 | IO_L22P_T3_35 | 3 | 35 | NA | NA | HR | 7S25T
H4 | IO_L22N_T3_35 | 3 | 35 | NA | NA | HR | 7S25T
J2 | IO_L23P_T3_35 | 3 | 35 | NA | NA | HR | 7S25T
J1 | IO_L23N_T3_35 | 3 | 35 | NA | NA | HR | 7S25T
H6 | IO_L24P_T3_35 | 3 | 35 | NA | NA | HR | 7S25T
G6 | IO_L24N_T3_35 | 3 | 35 | NA | NA | HR | 7S25T
J5 | IO_25_35 | NA | 35 | NA | NA | HR | 7S25T
A1 | GND | NA | NA | NA | NA | NA | NA
A12 | GND | NA | NA | NA | NA | NA | NA
A18 | GND | NA | NA | NA | NA | NA | NA
B9 | GND | NA | NA | NA | NA | NA | NA
C6 | GND | NA | NA | NA | NA | NA | NA
C16 | GND | NA | NA | NA | NA | NA | NA
D3 | GND | NA | NA | NA | NA | NA | NA
D13 | GND | NA | NA | NA | NA | NA | NA
E8 | GND | NA | NA | NA | NA | NA | NA
E10 | GND | NA | NA | NA | NA | NA | NA
F7 | GND | NA | NA | NA | NA | NA | NA
F9 | GND | NA | NA | NA | NA | NA | NA
F11 | GND | NA | NA | NA | NA | NA | NA
F17 | GND | NA | NA | NA | NA | NA | NA
G4 | GND | NA | NA | NA | NA | NA | NA
G8 | GND | NA | NA | NA | NA | NA | NA
G10 | GND | NA | NA | NA | NA | NA | NA
G12 | GND | NA | NA | NA | NA | NA | NA
G14 | GND | NA | NA | NA | NA | NA | NA
H1 | GND | NA | NA | NA | NA | NA | NA
H7 | GND | NA | NA | NA | NA | NA | NA
H11 | GND | NA | NA | NA | NA | NA | NA
J8 | GND | NA | NA | NA | NA | NA | NA
J12 | GND | NA | NA | NA | NA | NA | NA
J18 | GND | NA | NA | NA | NA | NA | NA
K5 | GND | NA | NA | NA | NA | NA | NA
K7 | GND | NA | NA | NA | NA | NA | NA
K11 | GND | NA | NA | NA | NA | NA | NA
K15 | GND | NA | NA | NA | NA | NA | NA
L2 | GND | NA | NA | NA | NA | NA | NA
L8 | GND | NA | NA | NA | NA | NA | NA
L12 | GND | NA | NA | NA | NA | NA | NA
M7 | GND | NA | NA | NA | NA | NA | NA
M9 | GND | NA | NA | NA | NA | NA | NA
M11 | GND | NA | NA | NA | NA | NA | NA
N6 | GND | NA | NA | NA | NA | NA | NA
N8 | GND | NA | NA | NA | NA | NA | NA
N10 | GND | NA | NA | NA | NA | NA | NA
N12 | GND | NA | NA | NA | NA | NA | NA
N16 | GND | NA | NA | NA | NA | NA | NA
P3 | GND | NA | NA | NA | NA | NA | NA
P9 | GND | NA | NA | NA | NA | NA | NA
P11 | GND | NA | NA | NA | NA | NA | NA
R10 | GND | NA | NA | NA | NA | NA | NA
T7 | GND | NA | NA | NA | NA | NA | NA
T17 | GND | NA | NA | NA | NA | NA | NA
U4 | GND | NA | NA | NA | NA | NA | NA
U14 | GND | NA | NA | NA | NA | NA | NA
V1 | GND | NA | NA | NA | NA | NA | NA
V11 | GND | NA | NA | NA | NA | NA | NA
V18 | GND | NA | NA | NA | NA | NA | NA
E7 | VCCINT | NA | NA | NA | NA | NA | NA
E9 | VCCINT | NA | NA | NA | NA | NA | NA
E11 | VCCINT | NA | NA | NA | NA | NA | NA
F8 | VCCINT | NA | NA | NA | NA | NA | NA
F10 | VCCINT | NA | NA | NA | NA | NA | NA
G7 | VCCINT | NA | NA | NA | NA | NA | NA
G9 | VCCINT | NA | NA | NA | NA | NA | NA
G11 | VCCINT | NA | NA | NA | NA | NA | NA
H8 | VCCINT | NA | NA | NA | NA | NA | NA
J7 | VCCINT | NA | NA | NA | NA | NA | NA
J11 | VCCINT | NA | NA | NA | NA | NA | NA
K8 | VCCINT | NA | NA | NA | NA | NA | NA
L11 | VCCINT | NA | NA | NA | NA | NA | NA
M8 | VCCINT | NA | NA | NA | NA | NA | NA
M10 | VCCINT | NA | NA | NA | NA | NA | NA
N9 | VCCINT | NA | NA | NA | NA | NA | NA
N11 | VCCINT | NA | NA | NA | NA | NA | NA
P8 | VCCINT | NA | NA | NA | NA | NA | NA
P10 | VCCINT | NA | NA | NA | NA | NA | NA
F12 | VCCAUX | NA | NA | NA | NA | NA | NA
H12 | VCCAUX | NA | NA | NA | NA | NA | NA
K12 | VCCAUX | NA | NA | NA | NA | NA | NA
M12 | VCCAUX | NA | NA | NA | NA | NA | NA
P12 | VCCAUX | NA | NA | NA | NA | NA | NA
D8 | VCCO_0 | NA | 0 | NA | NA | NA | NA
V10 | VCCO_0 | NA | 0 | NA | NA | NA | NA
N17 | VCCO_14 | NA | 14 | NA | NA | NA | NA
T16 | VCCO_14 | NA | 14 | NA | NA | NA | NA
U13 | VCCO_14 | NA | 14 | NA | NA | NA | NA
C15 | VCCO_15 | NA | 15 | NA | NA | NA | NA
F16 | VCCO_15 | NA | 15 | NA | NA | NA | NA
J17 | VCCO_15 | NA | 15 | NA | NA | NA | NA
B10 | VCCO_16 | NA | 16 | NA | NA | NA | NA
B12 | VCCO_16 | NA | 16 | NA | NA | NA | NA
L3 | VCCO_34 | NA | 34 | NA | NA | NA | NA
P4 | VCCO_34 | NA | 34 | NA | NA | NA | NA
U5 | VCCO_34 | NA | 34 | NA | NA | NA | NA
B6 | VCCO_35 | NA | 35 | NA | NA | NA | NA
D4 | VCCO_35 | NA | 35 | NA | NA | NA | NA
G3 | VCCO_35 | NA | 35 | NA | NA | NA | NA
L7 | VCCBRAM | NA | NA | NA | NA | NA | NA
N7 | VCCBRAM | NA | NA | NA | NA | NA | NA
Total Number of Pins | 324

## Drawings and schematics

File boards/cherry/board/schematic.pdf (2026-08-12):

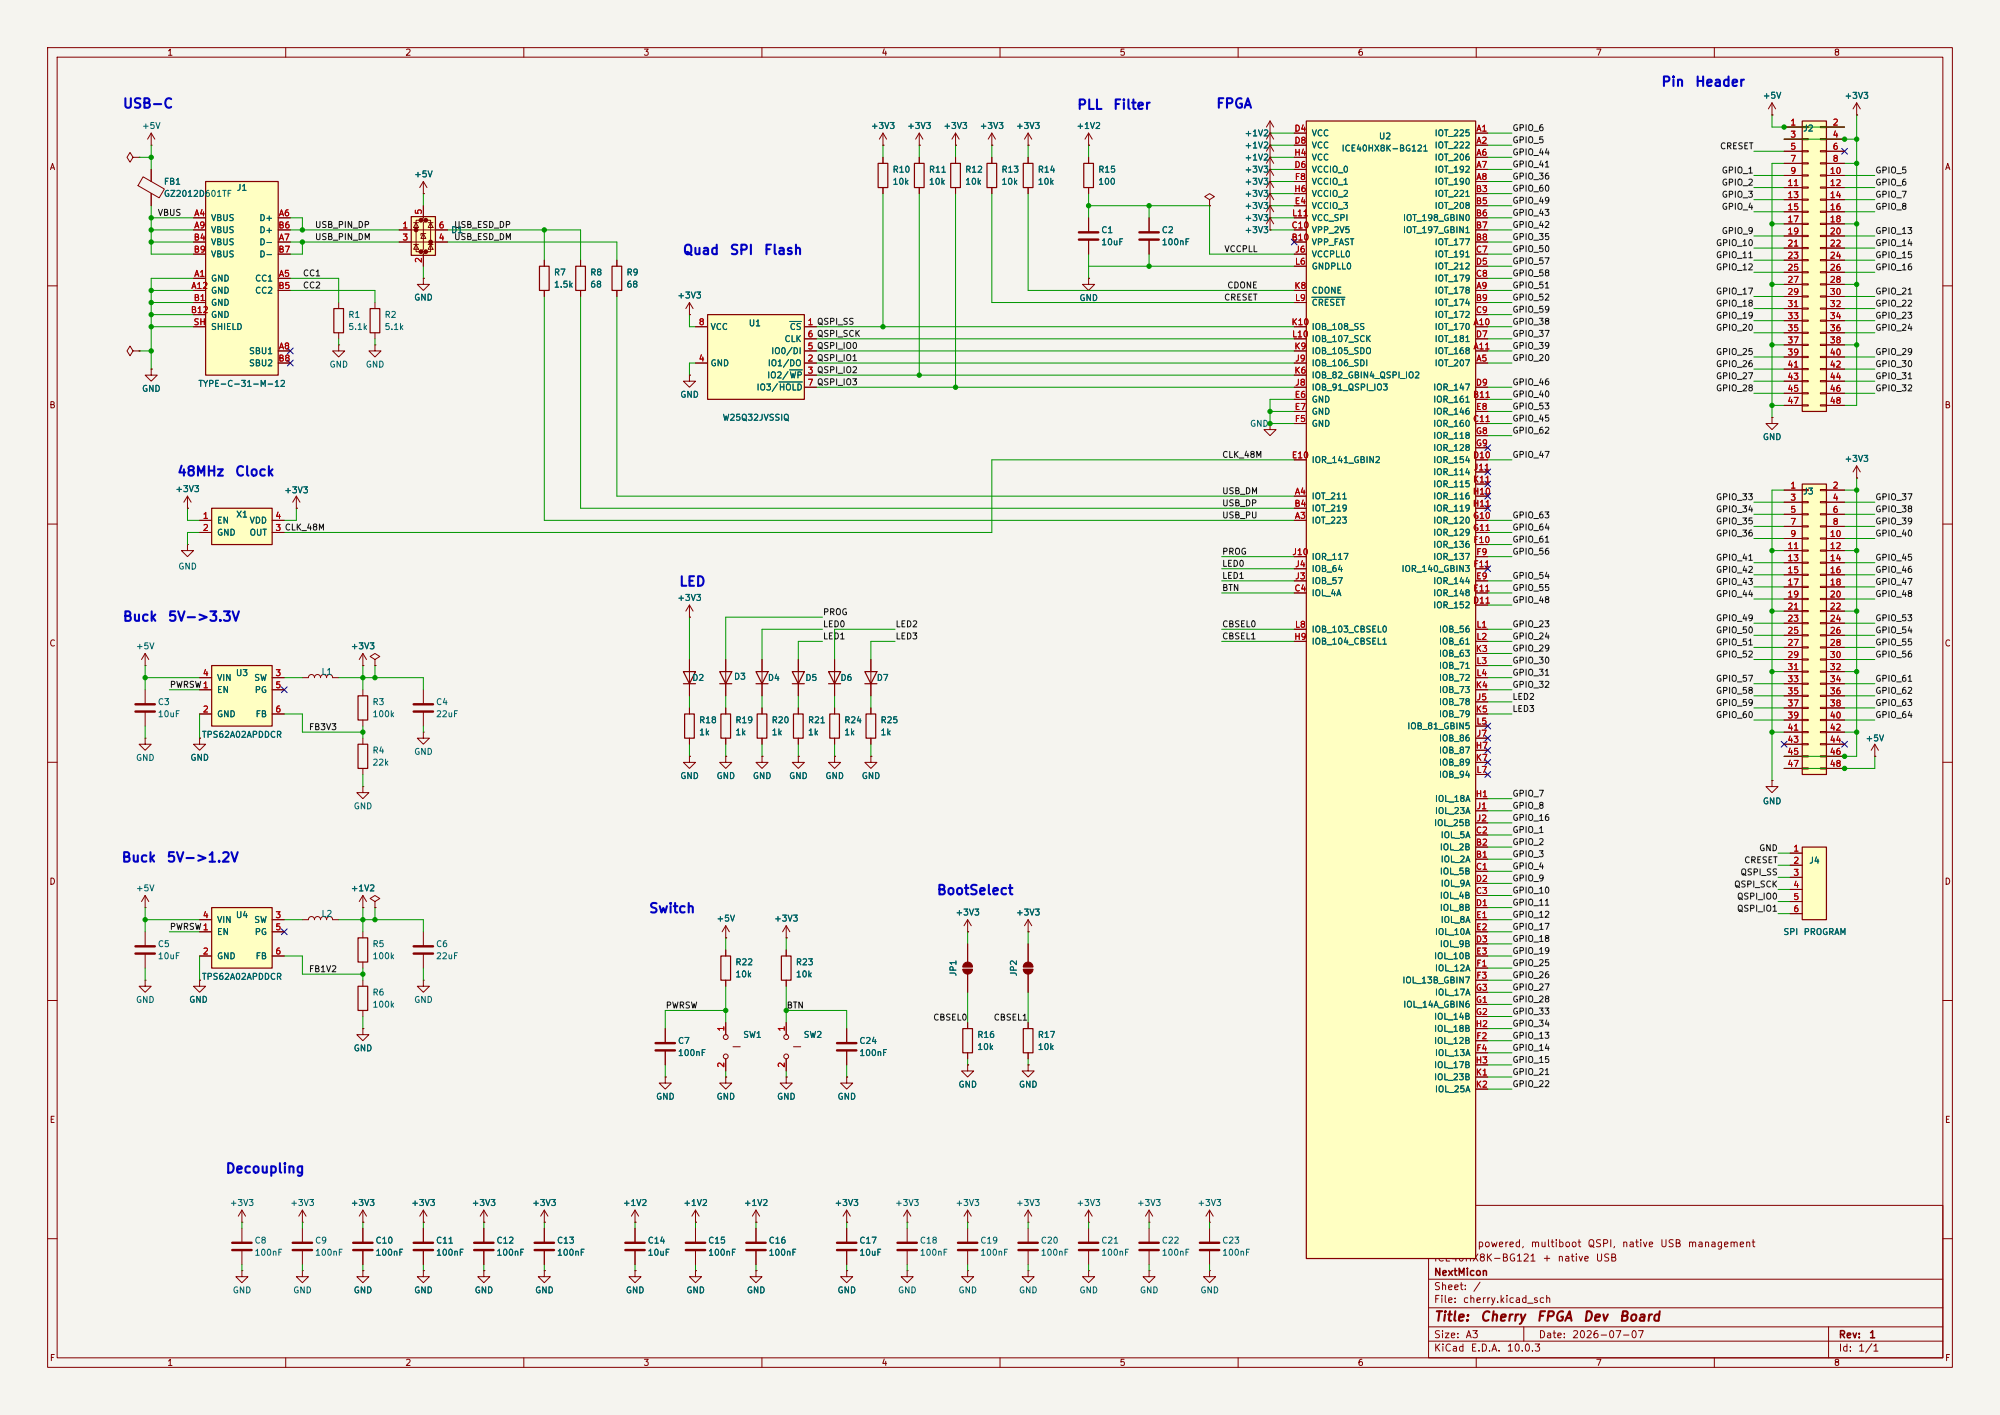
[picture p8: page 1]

iCE40HX8K-BG121 + native USB
NextMicon
Sheet: /
File: cherry.kicad_sch
Title: Cherry FPGA Dev Board

Size: A3 | Rev: 1 | F Date: 2026-07-07
KiCad E.D.A. 10.0.3 | Id: 1/1

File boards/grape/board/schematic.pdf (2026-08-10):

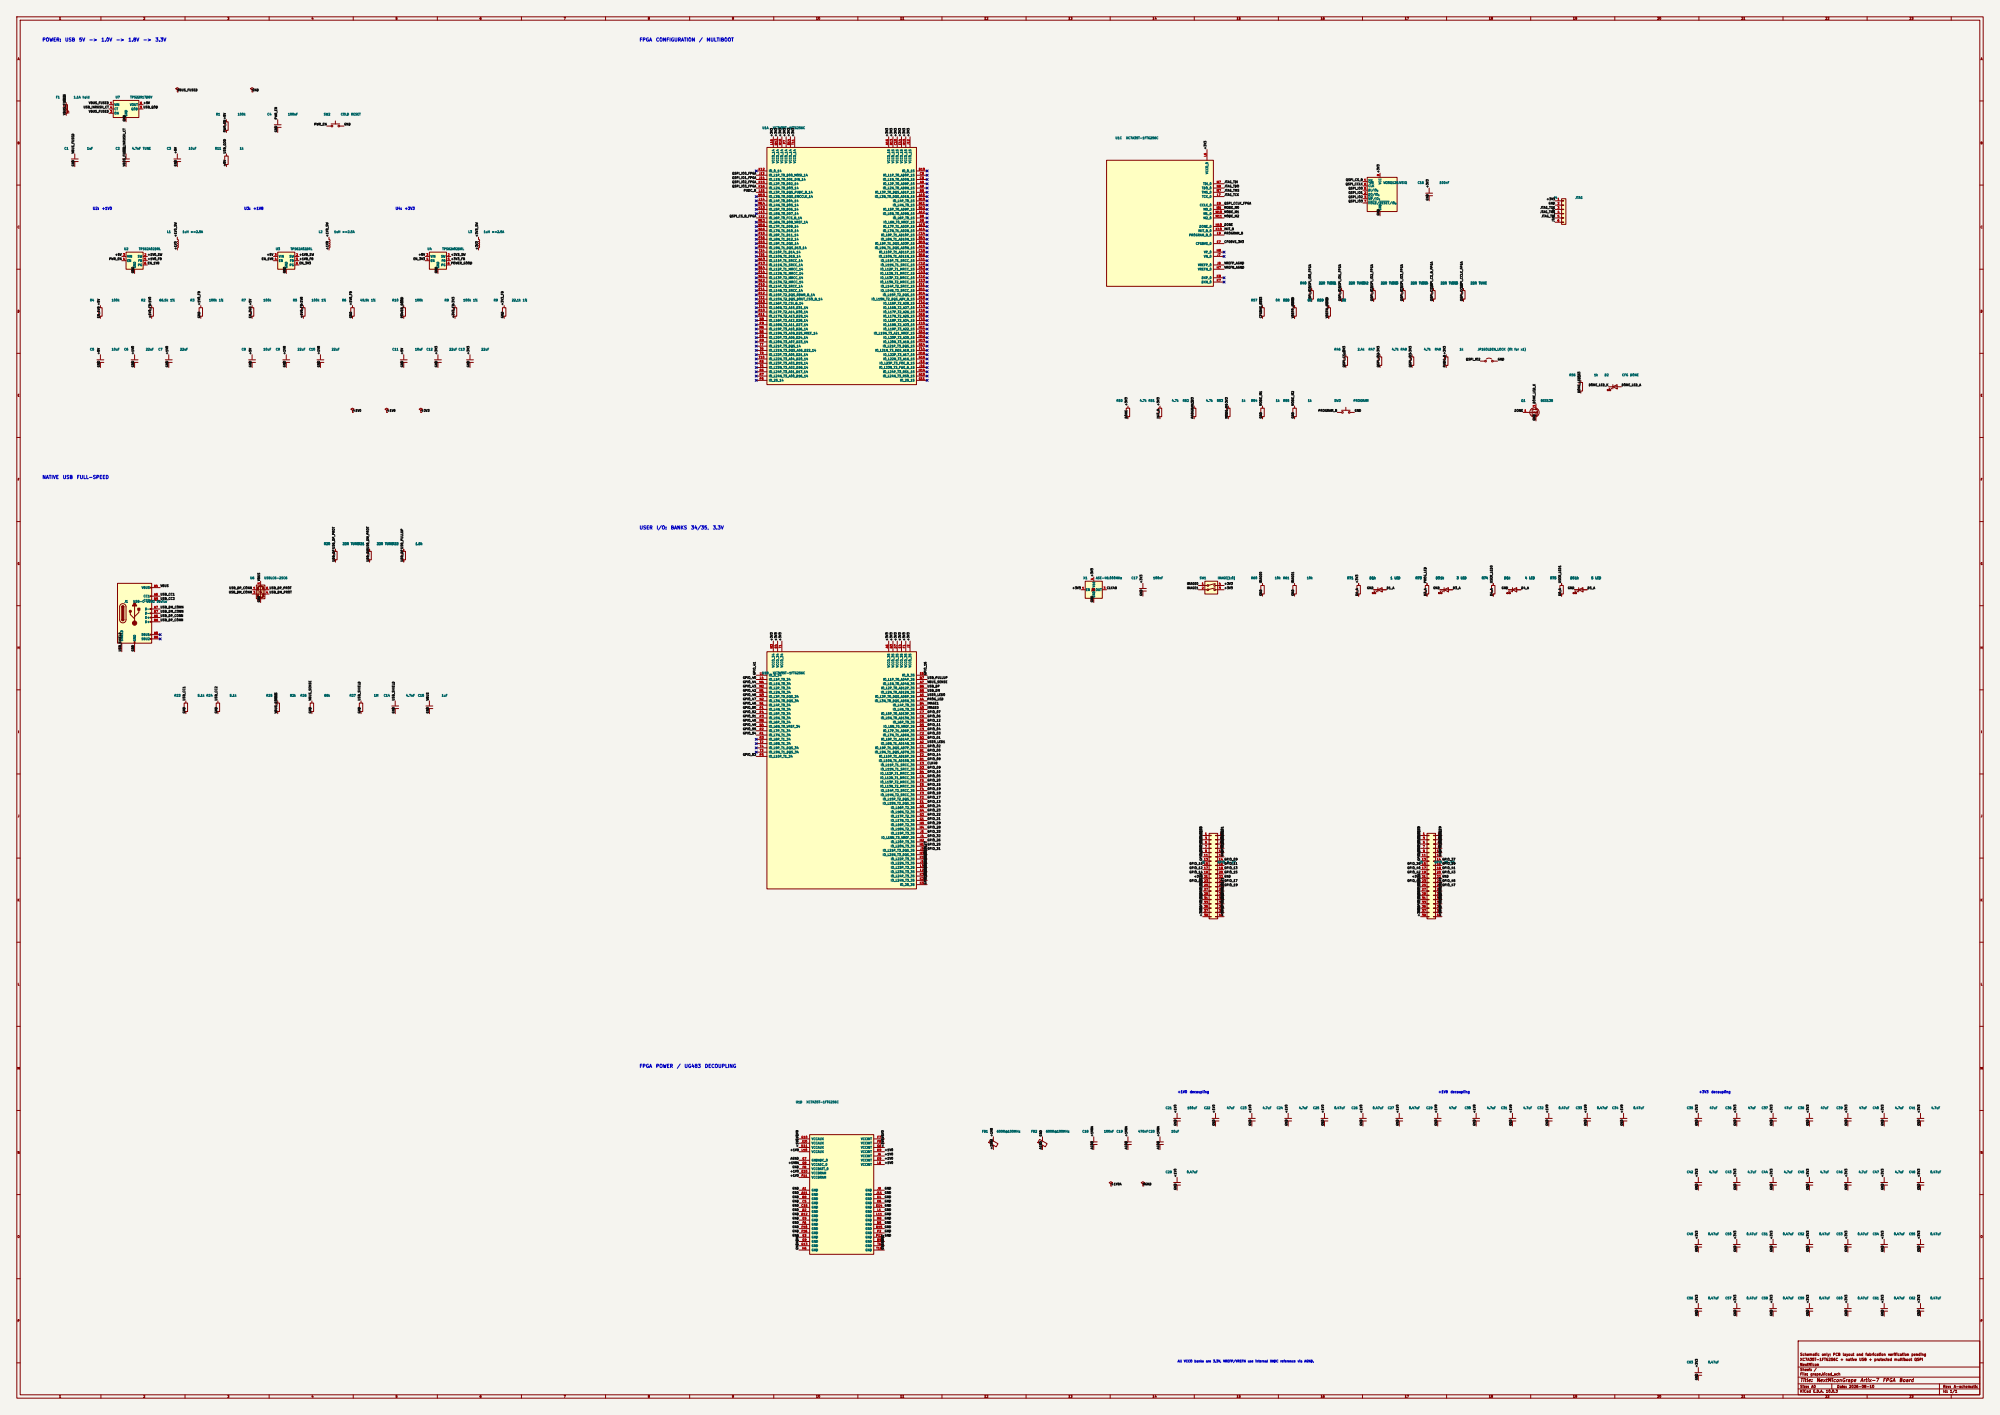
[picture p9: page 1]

NATIVE USB FULL-SPEED

Schematic only; PCB layout and fabrication verification pending
XC7A35T-1FTG256C + native USB + protected multiboot QSPI
NextMicon
Sheet: /
File: grape.kicad_sch
Title: NextMiconGrape Artix-7 FPGA Board

All VCCO banks are 3.3V. VREFP/VREFN use internal XADC reference via AGND.

Size: A0 | Rev: A-schematic
KiCad E.D.A. 10.0.3 | Id: 1/1

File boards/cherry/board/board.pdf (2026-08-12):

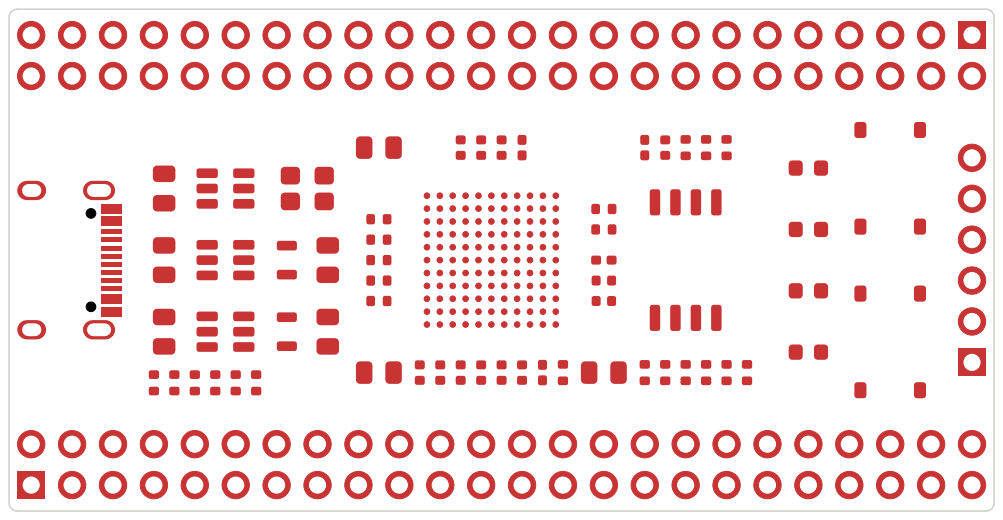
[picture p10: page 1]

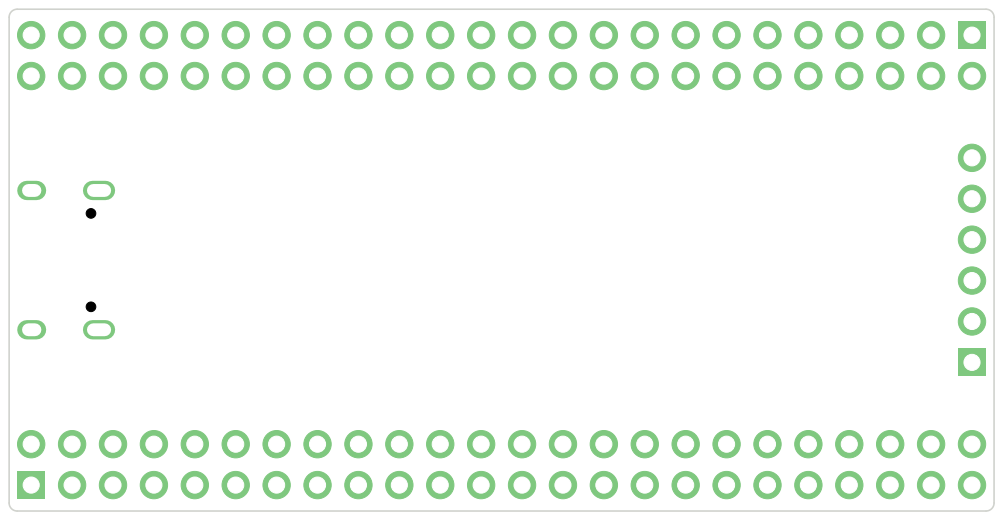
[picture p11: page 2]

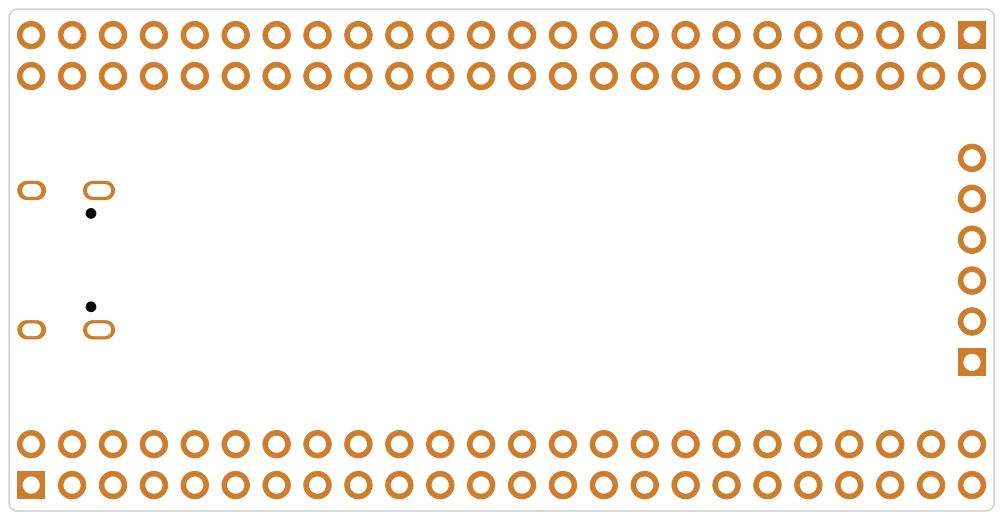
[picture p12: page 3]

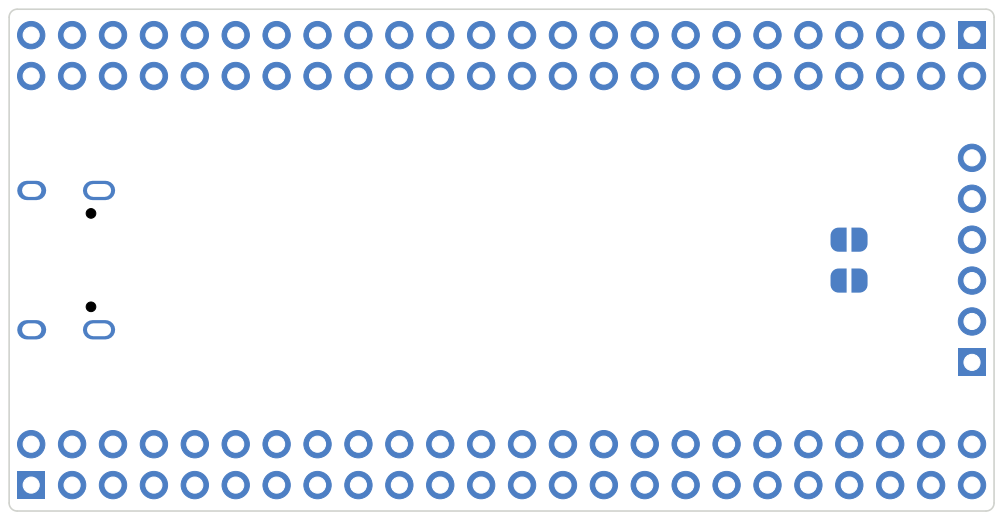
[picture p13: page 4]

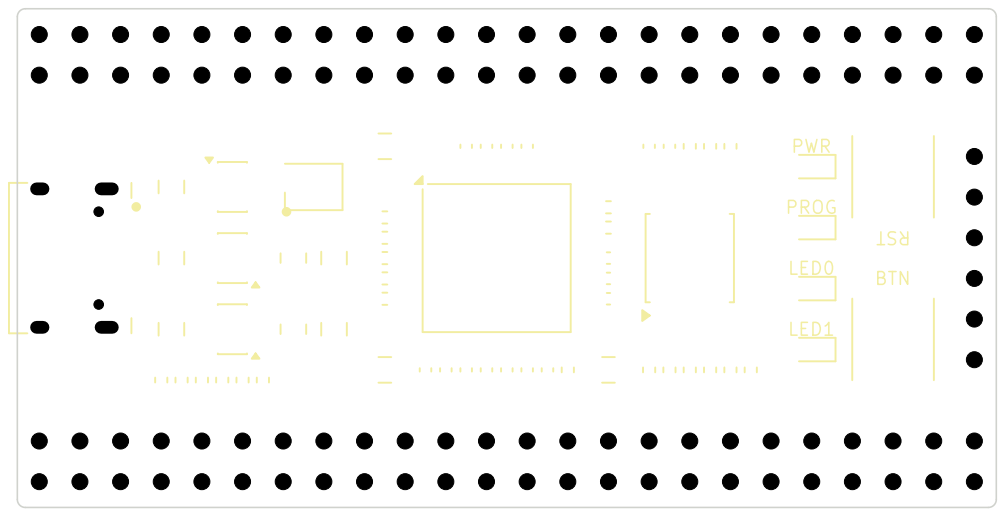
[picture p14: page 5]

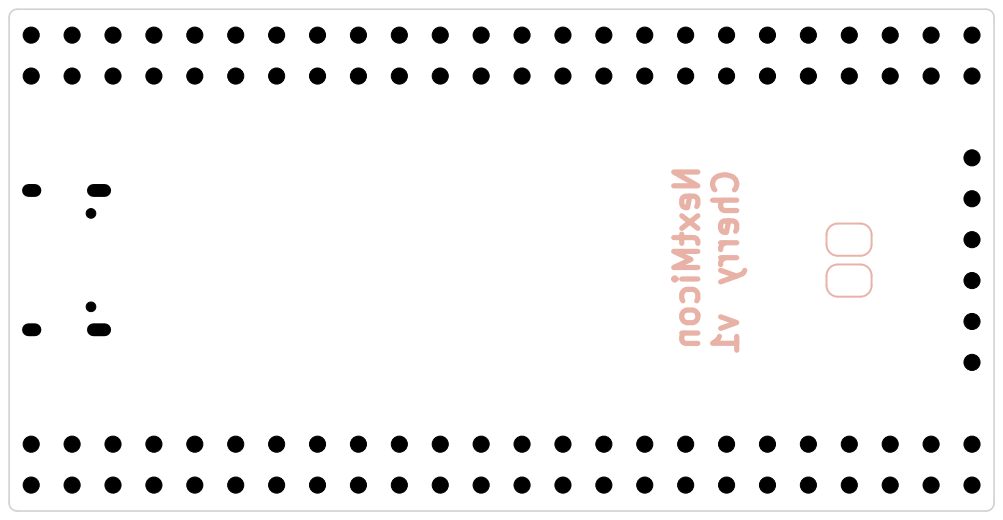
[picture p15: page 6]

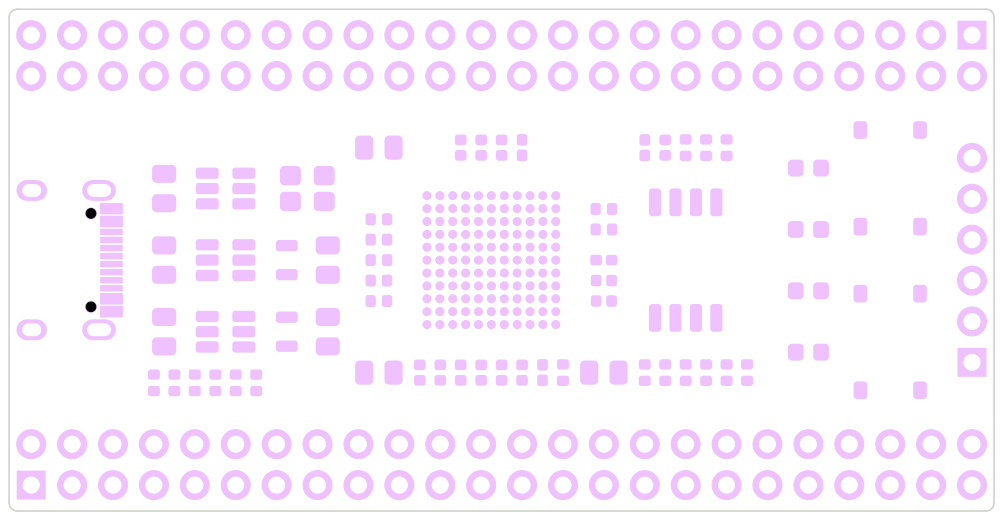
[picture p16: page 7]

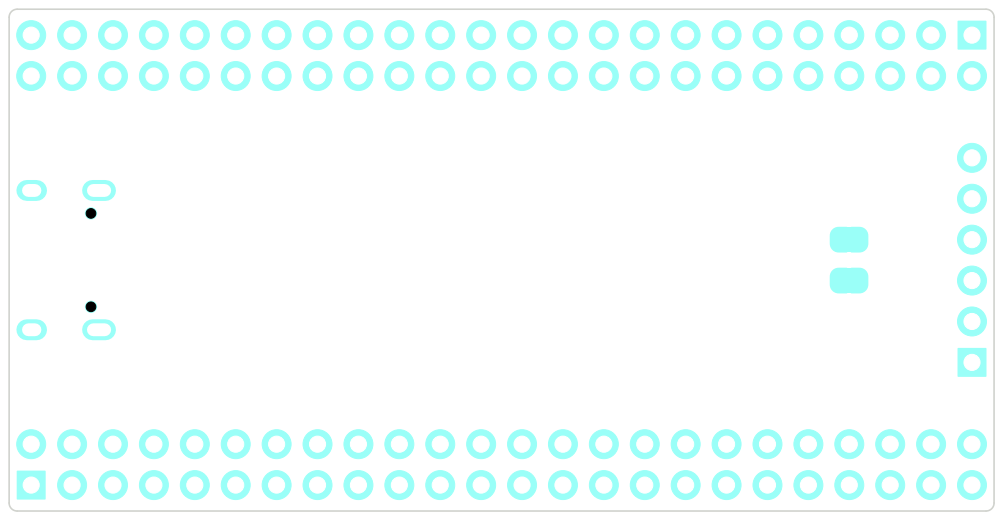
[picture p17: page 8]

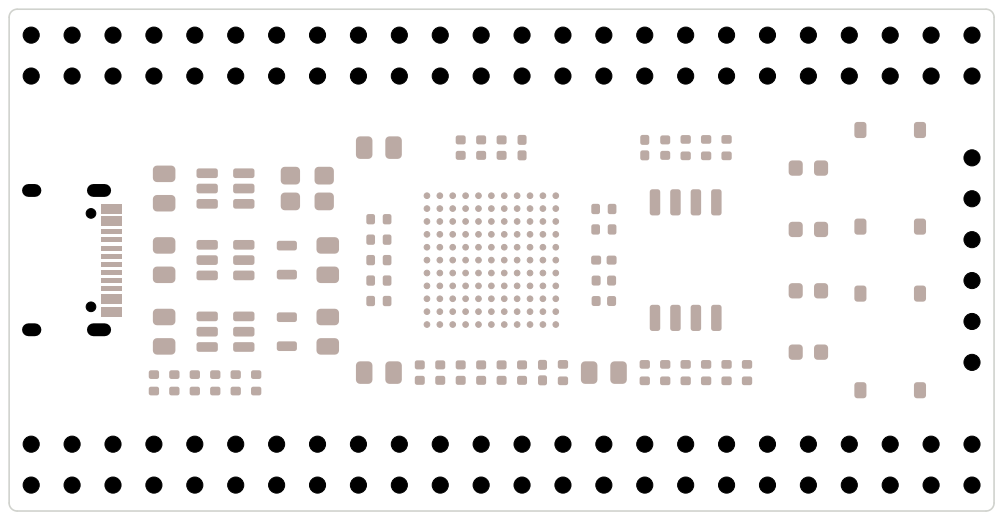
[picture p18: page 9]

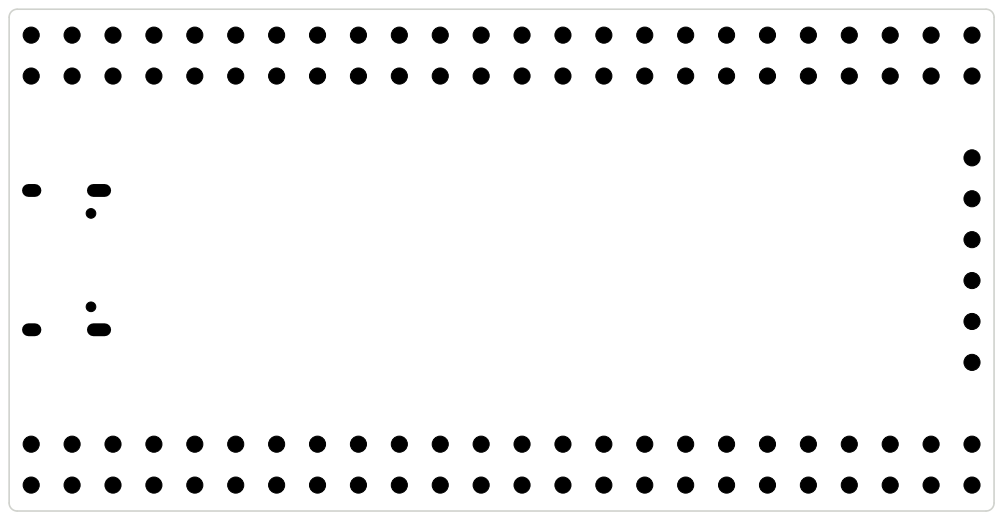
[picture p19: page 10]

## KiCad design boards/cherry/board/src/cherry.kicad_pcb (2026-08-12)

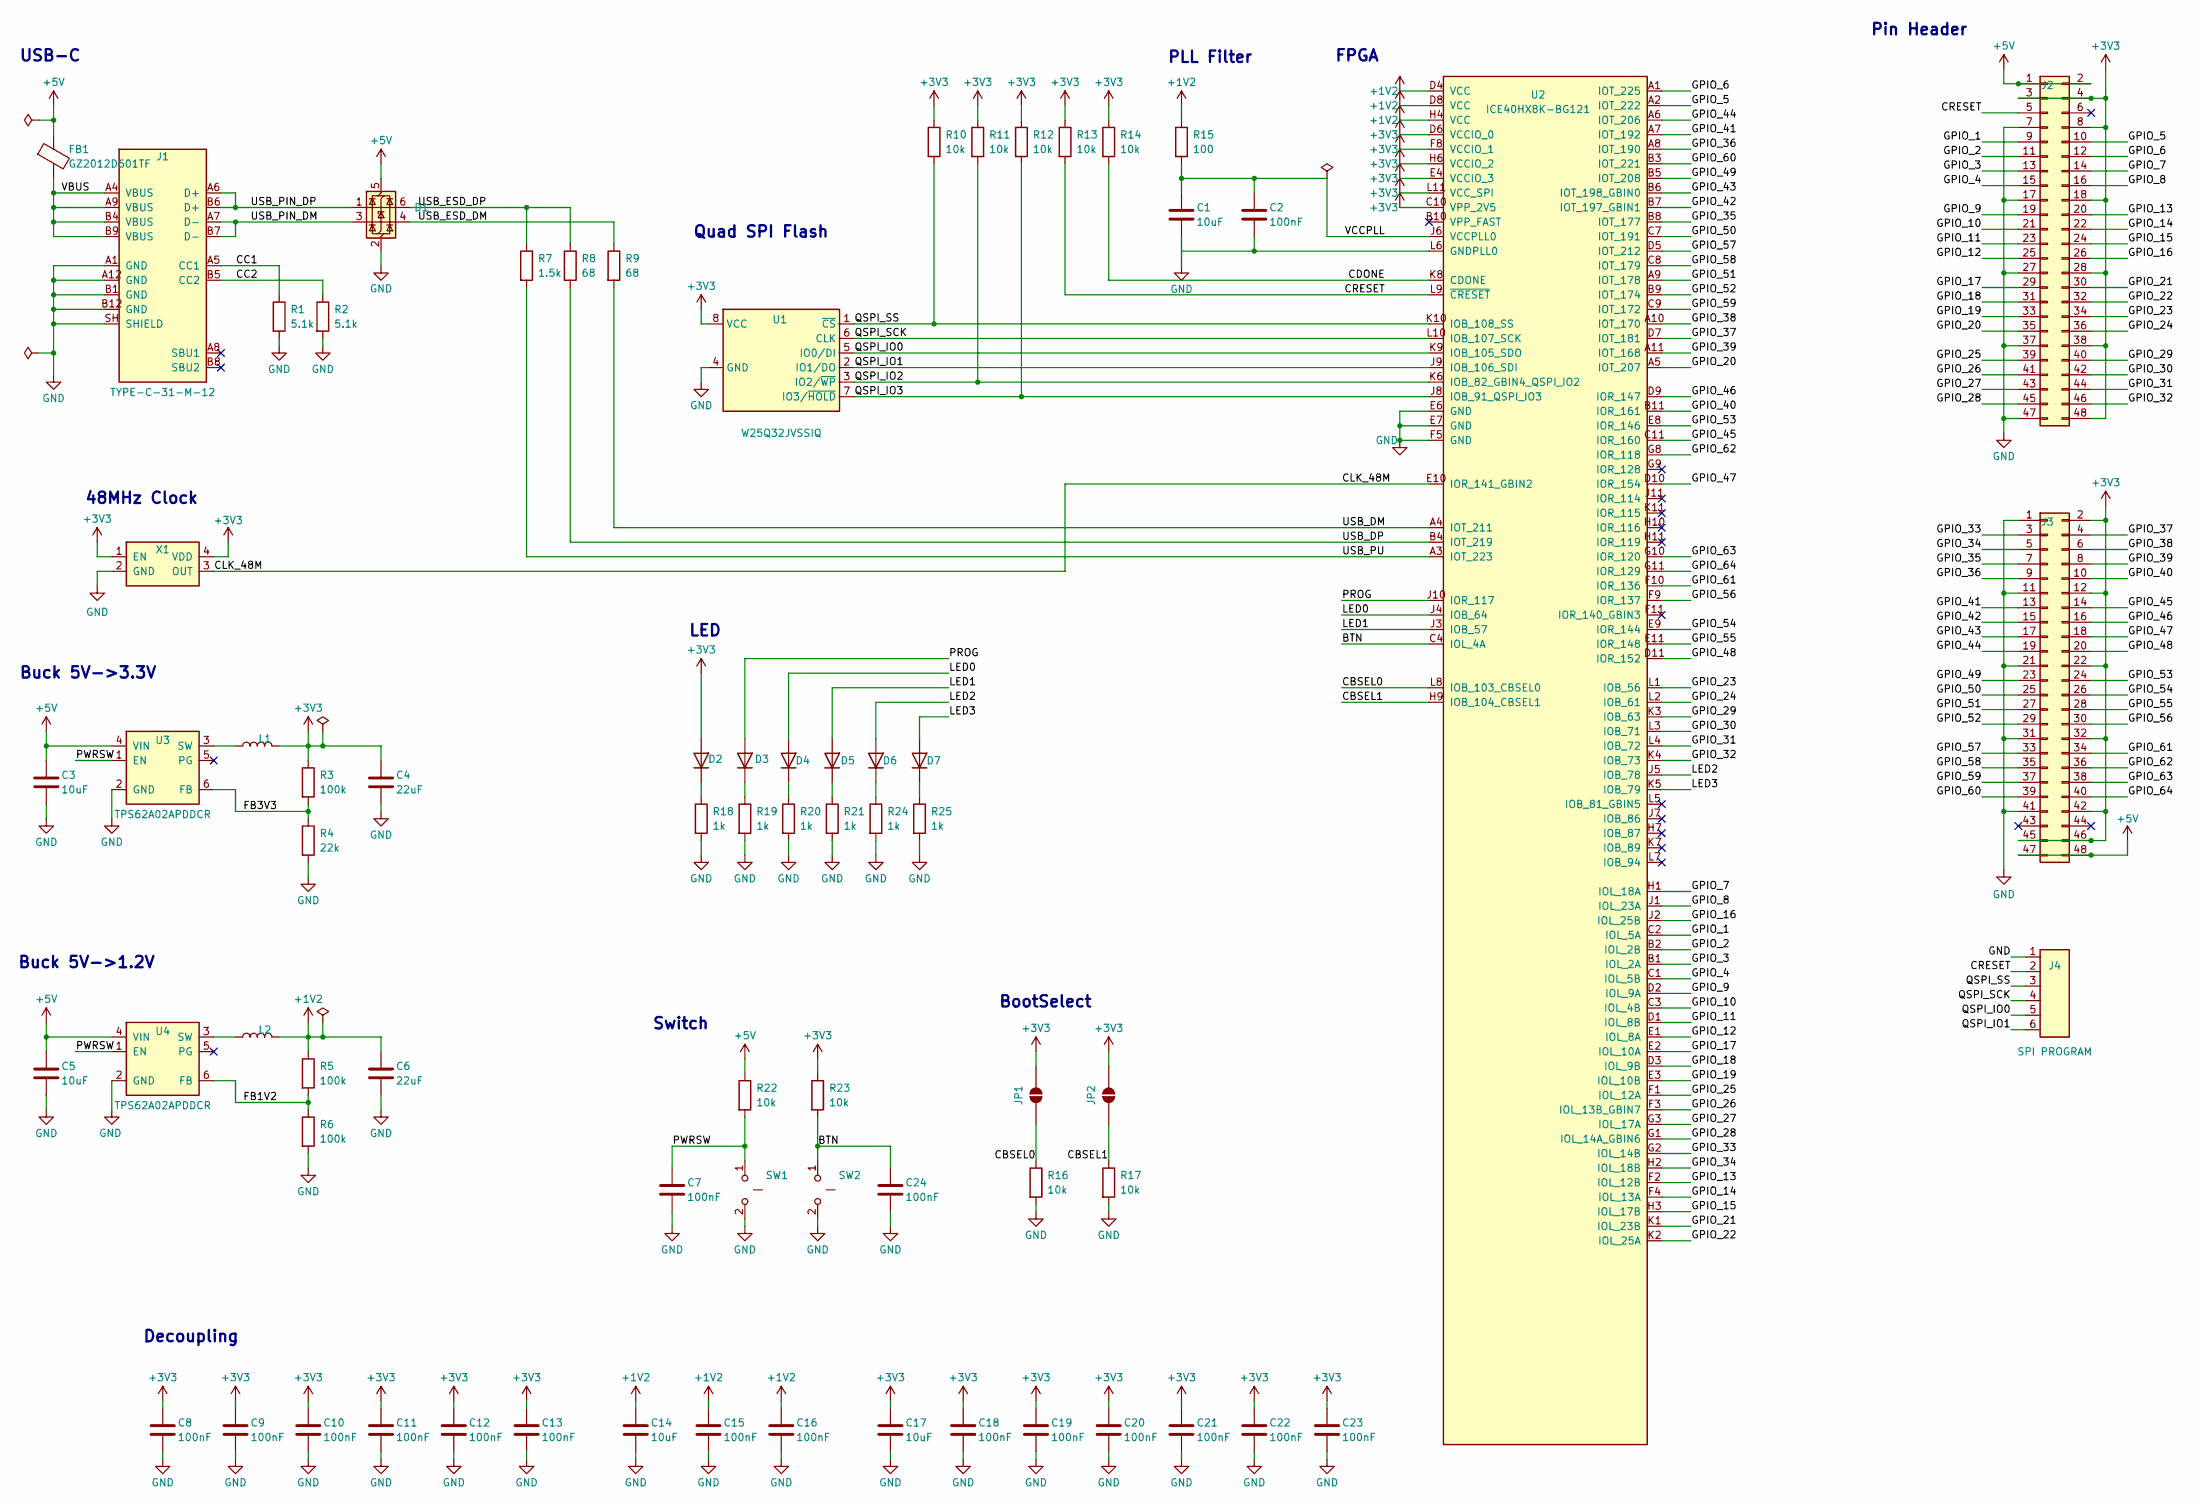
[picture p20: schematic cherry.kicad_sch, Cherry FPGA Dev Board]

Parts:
C1, C3, C5, C14, C17: 10uF; C_0805_2012Metric; LCSC C15850
C2, C7, C8, C9, C10, C11, C12, C13, C15, C16, C18, C19, C20, C21, C22, C23, C24: 100nF; C_0402_1005Metric; LCSC C1525
C4, C6: 22uF; C_0805_2012Metric; LCSC C45783
D1: USBLC6-2SC6; SOT-23-6; LCSC C2687116
D2, D3, D4, D6, D7: KT-0603R; LED_0603_1608Metric; LCSC C2286
D5: LED_AMBER_0603; LED_0603_1608Metric
FB1: GZ2012D601TF; L_0805_2012Metric; LCSC C1017
J1: TYPE-C-31-M-12; USB_C_Receptacle_Hroparts_TYPE-C-31-M-12; LCSC C165948
J2, J3: Conn_02x24_Odd_Even; PinHeader_2x24_P2.54mm_Vertical
J4: SPI PROGRAM; PinHeader_1x06_P2.54mm_Vertical
JP1, JP2: USER; SolderJumper-2_P1.3mm_Open_RoundedPad1.0x1.5mm
L1, L2: TFM201208ALD-1R0MTCA; L_TDK_TFM201208ALD; LCSC C433051
R1, R2: 5.1k; R_0402_1005Metric; LCSC C25905
R3, R5, R6: 100k; R_0402_1005Metric; LCSC C25741
R4: 22k; R_0402_1005Metric; LCSC C25768
R7: 1.5k; R_0402_1005Metric; LCSC C25117
R8, R9: 68; R_0402_1005Metric; LCSC C25117
R10, R11, R12, R13, R16, R17, R23: 10k; R_0402_1005Metric; LCSC C25744
R14: 10k; R_0402_1005Metric; LCSC C11702
R15: 100; R_0402_1005Metric; LCSC C25076
R18, R19, R20, R21, R24, R25: 1k; R_0402_1005Metric; LCSC C11702
R22: 10k; R_0402_1005Metric; LCSC C25741
SW1: TS-1187A-B-A-B; SW_Tactile_XKB_TS-1187A; LCSC C318884
SW2: USER; SW_Tactile_XKB_TS-1187A; LCSC C318884
U1: W25Q32JVSSIQ; SOIC-8_5.3x5.3mm_P1.27mm; LCSC C179173
U2: ICE40HX8K-BG121; BGA-121_9.0x9.0mm_Layout11x11_P0.8mm_Ball0.4mm_Pad0.35mm_NS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
U3, U4: TPS62A02APDDCR; SOT-23-6; LCSC C25687169
X1: OXETDLJANF-48.000000MHz; Oscillator_SMD_Taitien_OX_3.2x2.5mm; LCSC C5173414

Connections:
+1V2: C6.1, C14.1, C15.1, C16.1, L2.2, R5.1, R15.1, U2.D4 (VCC), U2.D8 (VCC), U2.H4 (VCC), U2.H8 (VCC)
+3V3: C4.1, C8.1, C9.1, C10.1, C11.1, C12.1, C13.1, C17.1, C18.1, C19.1, C20.1, C21.1, C22.1, C23.1, D2.2 (A), J2.3, J2.4, J2.8, J2.18, J2.28, J2.38, J2.48, J3.2, J3.12, J3.22, J3.32, J3.42, J3.45, J3.46, JP1.2 (B), JP2.2 (B), L1.2, R3.1, R10.1, R11.1, R12.1, R13.1, R14.1, R23.1, U1.8 (VCC), U2.C10 (VPP_2V5), U2.D6 (VCCIO_0), U2.E4 (VCCIO_3), U2.F8 (VCCIO_1), U2.G4 (VCCIO_3), U2.H6 (VCCIO_2), U2.L11 (VCC_SPI), X1.1 (EN), X1.4 (VDD)
+5V: C3.1, C5.1, D1.5 (VBUS), FB1.1, J2.1, J2.2, J3.47, J3.48, R22.1, U3.4 (VIN), U4.4 (VIN)
/BTN: C24.1, R23.2, SW2.1, U2.C4 (IOL_4A)
/CBSEL0: JP1.1 (A), R16.1, U2.L8 (IOB_103_CBSEL0)
/CBSEL1: JP2.1 (A), R17.1, U2.H9 (IOB_104_CBSEL1)
/CC1: J1.A5 (CC1), R1.1
/CC2: J1.B5 (CC2), R2.1
/CDONE: R14.2, U2.K8 (CDONE)
/CLK_48M: U2.E10 (IOR_141_GBIN2), X1.3 (OUT)
/CRESET: J2.5, J4.2, R13.2, U2.L9 (~CRESET)
/FB1V2: R5.2, R6.1, U4.6 (FB)
/FB3V3: R3.2, R4.1, U3.6 (FB)
/GPIO_1: J2.9, U2.C2 (IOL_5A)
/GPIO_2: J2.11, U2.B2 (IOL_2B)
/GPIO_3: J2.13, U2.B1 (IOL_2A)
/GPIO_4: J2.15, U2.C1 (IOL_5B)
/GPIO_5: J2.10, U2.A2 (IOT_222)
/GPIO_6: J2.12, U2.A1 (IOT_225)
/GPIO_7: J2.14, U2.H1 (IOL_18A)
/GPIO_8: J2.16, U2.J1 (IOL_23A)
/GPIO_9: J2.19, U2.D2 (IOL_9A)
/GPIO_10: J2.21, U2.C3 (IOL_4B)
/GPIO_11: J2.23, U2.D1 (IOL_8B)
/GPIO_12: J2.25, U2.E1 (IOL_8A)
/GPIO_13: J2.20, U2.F2 (IOL_12B)
/GPIO_14: J2.22, U2.F4 (IOL_13A)
/GPIO_15: J2.24, U2.H3 (IOL_17B)
/GPIO_16: J2.26, U2.J2 (IOL_25B)
/GPIO_17: J2.29, U2.E2 (IOL_10A)
/GPIO_18: J2.31, U2.D3 (IOL_9B)
/GPIO_19: J2.33, U2.E3 (IOL_10B)
/GPIO_20: J2.35, U2.A5 (IOT_207)
/GPIO_21: J2.30, U2.K1 (IOL_23B)
/GPIO_22: J2.32, U2.K2 (IOL_25A)
/GPIO_23: J2.34, U2.L1 (IOB_56)
/GPIO_24: J2.36, U2.L2 (IOB_61)
/GPIO_25: J2.39, U2.F1 (IOL_12A)
/GPIO_26: J2.41, U2.F3 (IOL_13B_GBIN7)
/GPIO_27: J2.43, U2.G3 (IOL_17A)
/GPIO_28: J2.45, U2.G1 (IOL_14A_GBIN6)
/GPIO_29: J2.40, U2.K3 (IOB_63)
/GPIO_30: J2.42, U2.L3 (IOB_71)
/GPIO_31: J2.44, U2.L4 (IOB_72)
/GPIO_32: J2.46, U2.K4 (IOB_73)
/GPIO_33: J3.3, U2.G2 (IOL_14B)
/GPIO_34: J3.5, U2.H2 (IOL_18B)
/GPIO_35: J3.7, U2.B8 (IOT_177)
/GPIO_36: J3.9, U2.A8 (IOT_190)
/GPIO_37: J3.4, U2.D7 (IOT_181)
/GPIO_38: J3.6, U2.A10 (IOT_170)
/GPIO_39: J3.8, U2.A11 (IOT_168)
/GPIO_40: J3.10, U2.B11 (IOR_161)
/GPIO_41: J3.13, U2.A7 (IOT_192)
/GPIO_42: J3.15, U2.B7 (IOT_197_GBIN1)
/GPIO_43: J3.17, U2.B6 (IOT_198_GBIN0)
/GPIO_44: J3.19, U2.A6 (IOT_206)
/GPIO_45: J3.14, U2.C11 (IOR_160)
/GPIO_46: J3.16, U2.D9 (IOR_147)
/GPIO_47: J3.18, U2.D10 (IOR_154)
/GPIO_48: J3.20, U2.D11 (IOR_152)
/GPIO_49: J3.23, U2.B5 (IOT_208)
/GPIO_50: J3.25, U2.C7 (IOT_191)
/GPIO_51: J3.27, U2.A9 (IOT_178)
/GPIO_52: J3.29, U2.B9 (IOT_174)
/GPIO_53: J3.24, U2.E8 (IOR_146)
/GPIO_54: J3.26, U2.E9 (IOR_144)
/GPIO_55: J3.28, U2.E11 (IOR_148)
/GPIO_56: J3.30, U2.F9 (IOR_137)
/GPIO_57: J3.33, U2.D5 (IOT_212)
/GPIO_58: J3.35, U2.C8 (IOT_179)
/GPIO_59: J3.37, U2.C9 (IOT_172)
/GPIO_60: J3.39, U2.B3 (IOT_221)
/GPIO_61: J3.34, U2.F10 (IOR_136)
/GPIO_62: J3.36, U2.G8 (IOR_118)
/GPIO_63: J3.38, U2.G10 (IOR_120)
/GPIO_64: J3.40, U2.G11 (IOR_129)
/LED0: D4.2 (A), U2.J4 (IOB_64)
/LED1: D5.2 (A), U2.J3 (IOB_57)
/LED2: D6.2 (A), U2.J5 (IOB_78)
/LED3: D7.2 (A), U2.K5 (IOB_79)
/PROG: D3.2 (A), U2.J10 (IOR_117)
/PWRSW: C7.1, R22.2, SW1.1, U3.1 (EN), U4.1 (EN)
/QSPI_IO0: J4.5, U1.5 (IO0/DI), U2.K9 (IOB_105_SDO)
/QSPI_IO1: J4.6, U1.2 (IO1/DO), U2.J9 (IOB_106_SDI)
/QSPI_IO2: R11.2, U1.3 (IO2/~WP), U2.K6 (IOB_82_GBIN4_QSPI_IO2)
/QSPI_IO3: R12.2, U1.7 (IO3/~HOLD), U2.J8 (IOB_91_QSPI_IO3)
/QSPI_SCK: J4.4, U1.6 (CLK), U2.L10 (IOB_107_SCK)
/QSPI_SS: J4.3, R10.2, U1.1 (~CS), U2.K10 (IOB_108_SS)
/USB_DM: R9.2, U2.A4 (IOT_211)
/USB_DP: R8.2, U2.B4 (IOT_219)
/USB_ESD_DM: D1.4 (I/O2), R9.1
/USB_ESD_DP: D1.6 (I/O1), R7.1, R8.1
/USB_PIN_DM: D1.3 (I/O2), J1.A7 (D-), J1.B7 (D-)
/USB_PIN_DP: D1.1 (I/O1), J1.A6 (D+), J1.B6 (D+)
/USB_PU: R7.2, U2.A3 (IOT_223)
/VBUS: FB1.2, J1.A4 (VBUS), J1.A9 (VBUS), J1.B4 (VBUS), J1.B9 (VBUS)
/VCCPLL: C1.1, C2.1, R15.2, U2.C6 (VCCPLL1), U2.J6 (VCCPLL0)
GND: C1.2, C2.2, C3.2, C4.2, C5.2, C6.2, C7.2, C8.2, C9.2, C10.2, C11.2, C12.2, C13.2, C14.2, C15.2, C16.2, C17.2, C18.2, C19.2, C20.2, C21.2, C22.2, C23.2, C24.2, D1.2 (GND), J1.A1 (GND), J1.A12 (GND), J1.B1 (GND), J1.B12 (GND), J1.SH (SHIELD), J2.7, J2.17, J2.27, J2.37, J2.47, J3.1, J3.11, J3.21, J3.31, J3.41, J4.1, R1.2, R2.2, R4.2, R6.2, R16.2, R17.2, R18.2, R19.2, R20.2, R21.2, R24.2, R25.2, SW1.2, SW2.2, U1.4 (GND), U2.C5 (GNDPLL1), U2.E5 (GND), U2.E6 (GND), U2.E7 (GND), U2.F5 (GND), U2.F6 (GND), U2.F7 (GND), U2.G5 (GND), U2.G6 (GND), U2.G7 (GND), U2.H5 (GND), U2.L6 (GNDPLL0), U3.2 (GND), U4.2 (GND), X1.2 (GND)
unnamed: D2.1 (K), R18.1
unnamed: D3.1 (K), R19.1
unnamed: D4.1 (K), R20.1
unnamed: D5.1 (K), R21.1
unnamed: D6.1 (K), R24.1
unnamed: D7.1 (K), R25.1
unnamed: L1.1, U3.3 (SW)
unnamed: L2.1, U4.3 (SW)

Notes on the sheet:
Switch
Buck 5V->3.3V
BootSelect
Pin Header
Buck 5V->1.2V
FPGA
PLL Filter
LED
USB-C
48MHz Clock
Quad SPI Flash
Decoupling

Board: 4 copper layers, 72 parts (2 on the bottom side), 107 nets, no tracks yet.

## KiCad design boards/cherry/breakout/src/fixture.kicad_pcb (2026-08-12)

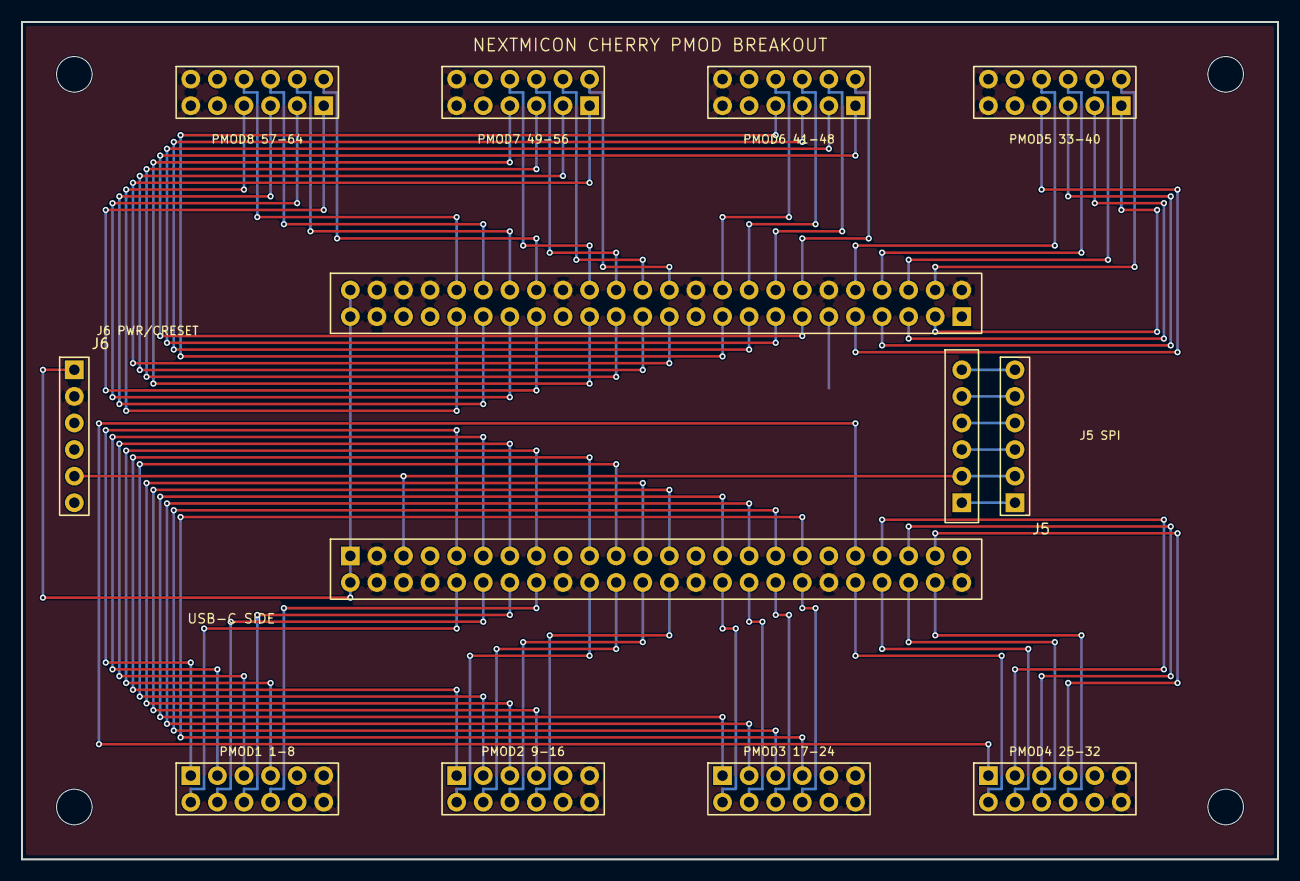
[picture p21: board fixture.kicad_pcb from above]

Board: 2 copper layers, 120.0 x 80.0 mm, 13 parts (0 on the bottom side), 72 nets.

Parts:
J5, J6: Header_1x6
PMOD1, PMOD2, PMOD3, PMOD4, PMOD5, PMOD6, PMOD7, PMOD8: Pmod_2x6
S2: Socket_S2
S3: Socket_S3
S4: Socket_S4

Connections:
+3V3: J6.2 (+3V3), PMOD1.6 (+3V3), PMOD1.12 (+3V3), PMOD2.6 (+3V3), PMOD2.12 (+3V3), PMOD3.6 (+3V3), PMOD3.12 (+3V3), PMOD4.6 (+3V3), PMOD4.12 (+3V3), PMOD5.6 (+3V3), PMOD5.12 (+3V3), PMOD6.6 (+3V3), PMOD6.12 (+3V3), PMOD7.6 (+3V3), PMOD7.12 (+3V3), PMOD8.6 (+3V3), PMOD8.12 (+3V3), S2.3 (+3V3), S2.4 (+3V3), S2.6 (+3V3), S2.8 (+3V3), S2.18 (+3V3), S2.28 (+3V3), S2.38 (+3V3), S2.48 (+3V3), S3.2 (+3V3), S3.12 (+3V3), S3.22 (+3V3), S3.32 (+3V3), S3.42 (+3V3), S3.44 (+3V3), S3.45 (+3V3), S3.46 (+3V3)
+5V: J6.1 (+5V), S2.1 (+5V), S2.2 (+5V), S3.47 (+5V), S3.48 (+5V)
CRESET_B: J5.2 (CRESET_B), J6.5 (CRESET_B), S2.5 (CRESET_B), S4.2 (CRESET_B)
GND: J5.1 (GND), J6.3 (GND), J6.4 (GND), J6.6 (GND), PMOD1.5 (GND), PMOD1.11 (GND), PMOD2.5 (GND), PMOD2.11 (GND), PMOD3.5 (GND), PMOD3.11 (GND), PMOD4.5 (GND), PMOD4.11 (GND), PMOD5.5 (GND), PMOD5.11 (GND), PMOD6.5 (GND), PMOD6.11 (GND), PMOD7.5 (GND), PMOD7.11 (GND), PMOD8.5 (GND), PMOD8.11 (GND), S2.7 (GND), S2.17 (GND), S2.27 (GND), S2.37 (GND), S2.47 (GND), S3.1 (GND), S3.11 (GND), S3.21 (GND), S3.31 (GND), S3.41 (GND), S3.43 (GND), S4.1 (GND)
GPIO1: PMOD1.1 (GPIO1), S2.9 (GPIO1)
GPIO2: PMOD1.2 (GPIO2), S2.11 (GPIO2)
GPIO3: PMOD1.3 (GPIO3), S2.13 (GPIO3)
GPIO4: PMOD1.4 (GPIO4), S2.15 (GPIO4)
GPIO5: PMOD1.7 (GPIO5), S2.10 (GPIO5)
GPIO6: PMOD1.8 (GPIO6), S2.12 (GPIO6)
GPIO7: PMOD1.9 (GPIO7), S2.14 (GPIO7)
GPIO8: PMOD1.10 (GPIO8), S2.16 (GPIO8)
GPIO9: PMOD2.1 (GPIO9), S2.19 (GPIO9)
GPIO10: PMOD2.2 (GPIO10), S2.21 (GPIO10)
GPIO11: PMOD2.3 (GPIO11), S2.23 (GPIO11)
GPIO12: PMOD2.4 (GPIO12), S2.25 (GPIO12)
GPIO13: PMOD2.7 (GPIO13), S2.20 (GPIO13)
GPIO14: PMOD2.8 (GPIO14), S2.22 (GPIO14)
GPIO15: PMOD2.9 (GPIO15), S2.24 (GPIO15)
GPIO16: PMOD2.10 (GPIO16), S2.26 (GPIO16)
GPIO17: PMOD3.1 (GPIO17), S2.29 (GPIO17)
GPIO18: PMOD3.2 (GPIO18), S2.31 (GPIO18)
GPIO19: PMOD3.3 (GPIO19), S2.33 (GPIO19)
GPIO20: PMOD3.4 (GPIO20), S2.35 (GPIO20)
GPIO21: PMOD3.7 (GPIO21), S2.30 (GPIO21)
GPIO22: PMOD3.8 (GPIO22), S2.32 (GPIO22)
GPIO23: PMOD3.9 (GPIO23), S2.34 (GPIO23)
GPIO24: PMOD3.10 (GPIO24), S2.36 (GPIO24)
GPIO25: PMOD4.1 (GPIO25), S2.39 (GPIO25)
GPIO26: PMOD4.2 (GPIO26), S2.41 (GPIO26)
GPIO27: PMOD4.3 (GPIO27), S2.43 (GPIO27)
GPIO28: PMOD4.4 (GPIO28), S2.45 (GPIO28)
GPIO29: PMOD4.7 (GPIO29), S2.40 (GPIO29)
GPIO30: PMOD4.8 (GPIO30), S2.42 (GPIO30)
GPIO31: PMOD4.9 (GPIO31), S2.44 (GPIO31)
GPIO32: PMOD4.10 (GPIO32), S2.46 (GPIO32)
GPIO33: PMOD5.1 (GPIO33), S3.3 (GPIO33)
GPIO34: PMOD5.2 (GPIO34), S3.5 (GPIO34)
GPIO35: PMOD5.3 (GPIO35), S3.7 (GPIO35)
GPIO36: PMOD5.4 (GPIO36), S3.9 (GPIO36)
GPIO37: PMOD5.7 (GPIO37), S3.4 (GPIO37)
GPIO38: PMOD5.8 (GPIO38), S3.6 (GPIO38)
GPIO39: PMOD5.9 (GPIO39), S3.8 (GPIO39)
GPIO40: PMOD5.10 (GPIO40), S3.10 (GPIO40)
GPIO41: PMOD6.1 (GPIO41), S3.13 (GPIO41)
GPIO42: PMOD6.2 (GPIO42), S3.15 (GPIO42)
GPIO43: PMOD6.3 (GPIO43), S3.17 (GPIO43)
GPIO44: PMOD6.4 (GPIO44), S3.19 (GPIO44)
GPIO45: PMOD6.7 (GPIO45), S3.14 (GPIO45)
GPIO46: PMOD6.8 (GPIO46), S3.16 (GPIO46)
GPIO47: PMOD6.9 (GPIO47), S3.18 (GPIO47)
GPIO48: PMOD6.10 (GPIO48), S3.20 (GPIO48)
GPIO49: PMOD7.1 (GPIO49), S3.23 (GPIO49)
GPIO50: PMOD7.2 (GPIO50), S3.25 (GPIO50)
GPIO51: PMOD7.3 (GPIO51), S3.27 (GPIO51)
GPIO52: PMOD7.4 (GPIO52), S3.29 (GPIO52)
GPIO53: PMOD7.7 (GPIO53), S3.24 (GPIO53)
GPIO54: PMOD7.8 (GPIO54), S3.26 (GPIO54)
GPIO55: PMOD7.9 (GPIO55), S3.28 (GPIO55)
GPIO56: PMOD7.10 (GPIO56), S3.30 (GPIO56)
GPIO57: PMOD8.1 (GPIO57), S3.33 (GPIO57)
GPIO58: PMOD8.2 (GPIO58), S3.35 (GPIO58)
GPIO59: PMOD8.3 (GPIO59), S3.37 (GPIO59)
GPIO60: PMOD8.4 (GPIO60), S3.39 (GPIO60)
GPIO61: PMOD8.7 (GPIO61), S3.34 (GPIO61)
GPIO62: PMOD8.8 (GPIO62), S3.36 (GPIO62)
GPIO63: PMOD8.9 (GPIO63), S3.38 (GPIO63)
GPIO64: PMOD8.10 (GPIO64), S3.40 (GPIO64)
QSPI_CS_B: J5.3 (QSPI_CS_B), S4.3 (QSPI_CS_B)
QSPI_MISO: J5.6 (QSPI_MISO), S4.6 (QSPI_MISO)
QSPI_MOSI: J5.5 (QSPI_MOSI), S4.5 (QSPI_MOSI)
QSPI_SCK: J5.4 (QSPI_SCK), S4.4 (QSPI_SCK)

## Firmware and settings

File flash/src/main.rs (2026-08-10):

use std::path::{Path, PathBuf};
use std::process::ExitCode;
use std::thread;
use std::time::{Duration, Instant};

use clap::{Parser, Subcommand, ValueEnum};
use nextmicon_flash::client::{ClientError, DeviceClient};
use nextmicon_flash::protocol::Image;
use nextmicon_flash::serial::{BoardInfo, DeviceManager, SerialError, UsbId};
use thiserror::Error;

#[derive(Debug, Parser)]
#[command(
    name = "nmb",
    version,
    about = "NextMicon FPGA programmer and image manager"
)]
struct Cli {
    /// Restrict discovery to a hexadecimal VID:PID. May be repeated.
    #[arg(long = "usb-id", value_name = "VID:PID", global = true)]
    usb_ids: Vec<UsbId>,

    /// Timeout for one framed serial request.
    #[arg(
        long,
        value_name = "MILLISECONDS",
        default_value_t = 30_000,
        value_parser = clap::value_parser!(u64).range(1..),
        global = true
    )]
    timeout_ms: u64,

    /// Time to wait for the boot image to re-enumerate before flashing.
    #[arg(
        long,
        value_name = "SECONDS",
        default_value_t = 15,
        value_parser = clap::value_parser!(u64).range(1..),
        global = true
    )]
    reenumeration_timeout: u64,

    #[command(subcommand)]
    command: Command,
}

#[derive(Debug, Subcommand)]
enum Command {
    /// List connected NextMicon boards.
    Ls {
        /// Include USB identity and current image role.
        #[arg(short, long)]
        verbose: bool,
    },
    /// Warm-boot the protected boot image or the user image.
    Boot {
        /// Board name reported by `nmb ls`.
        board: String,
        /// Image role to start.
        image: ImageRole,
    },
    /// Erase, program, manifest, and verify the user image.
    Flash {
        /// Board name reported by `nmb ls`.
        board: String,
        /// Raw iCE40 bitstream to program.
        #[arg(value_name = "BITSTREAM")]
        image: PathBuf,
        /// Boot the newly programmed image after verification.
        #[arg(long)]
        boot: bool,
    },
}

#[derive(Clone, Copy, Debug, Eq, PartialEq, ValueEnum)]
enum ImageRole {
    Boot,
    User,
}

impl ImageRole {
    const fn image(self) -> Image {
        match self {
            Self::Boot => Image::Boot,
            Self::User => Image::User,
        }
    }

    const fn label(self) -> &'static str {
        match self {
            Self::Boot => "boot",
            Self::User => "user",
        }
    }
}

fn main() -> ExitCode {
    match run(Cli::parse()) {
        Ok(()) => ExitCode::SUCCESS,
        Err(error) => {
            eprintln!("nmb: {error}");
            ExitCode::FAILURE
        }
    }
}

fn run(cli: Cli) -> Result<(), AppError> {
    let manager = DeviceManager::new(cli.usb_ids);
    let timeout = Duration::from_millis(cli.timeout_ms);

    match cli.command {
        Command::Ls { verbose } => list_boards(&manager, verbose),
        Command::Boot { board, image } => {
            let board = manager.find(&board)?;
            let transport = manager.open(&board, timeout)?;
            let mut client = DeviceClient::new(transport, timeout);
            client.boot(image.image())?;
            println!("{} accepted boot to {}", board.name, image.label());
            Ok(())
        }
        Command::Flash { board, image, boot } => {
            let data = read_image(&image)?;
            let mut board = manager.find(&board)?;

            let active_image = {
                let transport = manager.open(&board, timeout)?;
                let mut client = DeviceClient::new(transport, timeout);
                client.info()?.active_image
            };
            if !active_image.is_boot() {
                eprintln!("Switching {} to the boot image...", board.name);
                {
                    let transport = manager.open(&board, timeout)?;
                    let mut client = DeviceClient::new(transport, timeout);
                    client.boot(Image::Boot)?;
                }
                board = wait_for_image(
                    &manager,
                    &board,
                    Image::Boot,
                    Duration::from_secs(cli.reenumeration_timeout),
                )?;
            }

            eprintln!(
                "Programming {} bytes into {} user image and verifying readback...",
                data.len(),
                board.name
            );
            let transport = manager.open(&board, timeout)?;
            let mut client = DeviceClient::new(transport, timeout);
            let manifest = client.program_user_image(&data)?;
            println!(
                "Programmed {}/user: {} bytes, CRC32 {:08x}, verified",
                board.name, manifest.image_length, manifest.crc32
            );
            if boot {
                client.boot(Image::User)?;
                println!("{} accepted boot to user", board.name);
            }
            Ok(())
        }
    }
}

fn list_boards(manager: &DeviceManager, verbose: bool) -> Result<(), AppError> {
    for board in manager.list()? {
        if verbose {
            let product = board.product.as_deref().unwrap_or("unknown product");
            let active_image = manager
                .open(&board, Duration::from_millis(250))
                .ok()
                .and_then(|transport| {
                    DeviceClient::new(transport, Duration::from_millis(250))
                        .info()
                        .ok()
                })
                .map(|info| match info.active_image {
                    Image::Boot => "boot".to_owned(),
                    Image::User => "user".to_owned(),
                })
                .unwrap_or_else(|| "unknown".to_owned());
            println!(
                "{}\t{}\t{}\t{}\t{}",
                board.name, active_image, board.usb_id, board.port_name, product
            );
        } else {
            println!("{}", board.name);
        }
    }
    Ok(())
}

fn read_image(path: &Path) -> Result<Vec<u8>, AppError> {
    std::fs::read(path).map_err(|source| AppError::ReadImage {
        path: path.to_owned(),
        source,
    })
}

fn wait_for_image(
    manager: &DeviceManager,
    original: &BoardInfo,
    target: Image,
    timeout: Duration,
) -> Result<BoardInfo, AppError> {
    let deadline = Instant::now() + timeout;
    loop {
        let boards = manager.list()?;
        let candidates: Vec<_> = boards
            .iter()
            .filter(|board| original.same_board_as(board))
            .cloned()
            .collect();
        let candidates = if original.serial.is_none() && candidates.is_empty() && boards.len() == 1
        {
            boards
        } else {
            candidates
        };
        for board in candidates {
            let probe_timeout = Duration::from_millis(250);
            if let Ok(transport) = manager.open(&board, probe_timeout) {
                let mut client = DeviceClient::new(transport, probe_timeout);
                if client.info().is_ok_and(|info| info.active_image == target) {
                    return Ok(board);
                }
            }
        }
        if Instant::now() >= deadline {
            return Err(AppError::ReenumerationTimeout {
                board: original.name.clone(),
                timeout,
            });
        }
        thread::sleep(Duration::from_millis(100));
    }
}

#[derive(Debug, Error)]
enum AppError {
    #[error(transparent)]
    Serial(#[from] SerialError),
    #[error(transparent)]
    Client(#[from] ClientError),
    #[error("could not read image {path:?}: {source}")]
    ReadImage {
        path: PathBuf,
        source: std::io::Error,
    },
    #[error("timed out after {timeout:?} waiting for {board:?} to re-enumerate as boot")]
    ReenumerationTimeout { board: String, timeout: Duration },
}

#[cfg(test)]
mod tests {
    use super::*;

    #[test]
    fn parses_named_boot_roles_and_unique_flash_target() {
        let cli = Cli::try_parse_from(["nmb", "boot", "cherry-0123", "user"]).unwrap();
        assert!(matches!(
            cli.command,
            Command::Boot {
                board,
                image: ImageRole::User
            } if board == "cherry-0123"
        ));

        let cli = Cli::try_parse_from(["nmb", "flash", "cherry-0123", "user.bin"]).unwrap();
        assert!(matches!(
            cli.command,
            Command::Flash { board, image, .. }
                if board == "cherry-0123" && image == PathBuf::from("user.bin")
        ));
        assert!(Cli::try_parse_from(["nmb", "boot", "cherry-0123", "2"]).is_err());
    }
}

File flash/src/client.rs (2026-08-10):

use std::time::Duration;

use thiserror::Error;

use crate::manifest::{ImageManifest, ManifestError};
use crate::protocol::{
    BootCommand, BootStatus, CAPABILITY_BOOT, Channel, FLASH_READ_DATA_SIZE, FLASH_WRITE_DATA_SIZE,
    FlashCommand, FlashRequestError, FlashStatus, Frame, Image, InvalidBootStatus,
    InvalidFlashStatus, ProtocolError, encode_erase_slot, encode_flash_read, encode_flash_write,
};

pub trait FrameTransport {
    fn exchange(&mut self, request: &Frame, timeout: Duration) -> Result<Frame, TransportError>;
}

#[derive(Debug, Error)]
#[error("{0}")]
pub struct TransportError(pub String);

#[derive(Clone, Copy, Debug, Eq, PartialEq)]
pub struct DeviceInfo {
    pub active_image: Image,
    pub capabilities: u8,
}

pub struct DeviceClient<T> {
    transport: T,
    timeout: Duration,
    next_sequence: u8,
}

impl<T: FrameTransport> DeviceClient<T> {
    pub fn new(transport: T, timeout: Duration) -> Self {
        Self {
            transport,
            timeout,
            next_sequence: 0,
        }
    }

    pub fn info(&mut self) -> Result<DeviceInfo, ClientError> {
        let response = self.request(Channel::Boot, BootCommand::GetInfo as u8, Vec::new())?;
        if response.len() != 3 {
            return Err(ClientError::ResponseLength {
                operation: "BOOT GET_INFO",
                expected: 3,
                actual: response.len(),
            });
        }
        self.check_boot_status(response[0])?;
        let active_image = Image::try_from(response[1])?;
        if response[2] & CAPABILITY_BOOT == 0 {
            return Err(ClientError::InvalidCapabilities(response[2]));
        }
        Ok(DeviceInfo {
            active_image,
            capabilities: response[2],
        })
    }

    pub fn boot(&mut self, image: Image) -> Result<(), ClientError> {
        let response = self.request(
            Channel::Boot,
            BootCommand::SelectImage as u8,
            vec![image as u8],
        )?;
        if response.len() != 1 {
            return Err(ClientError::ResponseLength {
                operation: "BOOT SELECT_IMAGE",
                expected: 1,
                actual: response.len(),
            });
        }
        self.check_boot_status(response[0])
    }

    /// Erases, writes, manifests, and reads back the single user image.
    ///
    /// The boot image is intentionally inaccessible through this API. Factory
    /// recovery uses the external SPI header rather than normal USB flashing.
    pub fn program_user_image(&mut self, data: &[u8]) -> Result<ImageManifest, ClientError> {
        let image = Image::User;
        let manifest = ImageManifest::for_data(data)?;

        self.erase_user_image()?;
        self.write_at(image.flash_base(), data)?;
        self.write_at(manifest.address(), &manifest.encode())?;
        self.verify_at(image.flash_base(), data)?;
        self.verify_at(manifest.address(), &manifest.encode())?;
        Ok(manifest)
    }

    fn erase_user_image(&mut self) -> Result<(), ClientError> {
        self.flash_command(FlashCommand::EraseSlot, encode_erase_slot().to_vec())
    }

    fn write_at(&mut self, mut address: u32, mut data: &[u8]) -> Result<(), ClientError> {
        while !data.is_empty() {
            let length = data.len().min(FLASH_WRITE_DATA_SIZE);
            let payload = encode_flash_write(address, &data[..length])?;
            self.flash_command(FlashCommand::Write, payload)?;
            address += length as u32;
            data = &data[length..];
        }
        Ok(())
    }

    fn verify_at(&mut self, mut address: u32, mut expected: &[u8]) -> Result<(), ClientError> {
        while !expected.is_empty() {
            let length = expected.len().min(FLASH_READ_DATA_SIZE);
            let actual = self.read_at(address, length)?;
            if actual != expected[..length] {
                let offset = actual
                    .iter()
                    .zip(&expected[..length])
                    .position(|(actual, expected)| actual != expected)
                    .unwrap_or(0);
                return Err(ClientError::VerificationFailed {
                    address: address + offset as u32,
                    expected: expected[offset],
                    actual: actual[offset],
                });
            }
            address += length as u32;
            expected = &expected[length..];
        }
        Ok(())
    }

    fn read_at(&mut self, address: u32, length: usize) -> Result<Vec<u8>, ClientError> {
        let request = encode_flash_read(address, length)?;
        let response = self.request(Channel::Flash, FlashCommand::Read as u8, request.to_vec())?;
        if response.len() != length + 1 {
            return Err(ClientError::ResponseLength {
                operation: "FLASH READ",
                expected: length + 1,
                actual: response.len(),
            });
        }
        self.check_flash_status(response[0])?;
        Ok(response[1..].to_vec())
    }

    fn flash_command(
        &mut self,
        command: FlashCommand,
        payload: Vec<u8>,
    ) -> Result<(), ClientError> {
        let response = self.request(Channel::Flash, command as u8, payload)?;
        if response.len() != 1 {
            return Err(ClientError::ResponseLength {
                operation: "FLASH command",
                expected: 1,
                actual: response.len(),
            });
        }
        self.check_flash_status(response[0])
    }

    fn request(
        &mut self,
        channel: Channel,
        opcode: u8,
        payload: Vec<u8>,
    ) -> Result<Vec<u8>, ClientError> {
        let sequence = self.next_sequence;
        self.next_sequence = self.next_sequence.wrapping_add(1);
        let request = Frame::new(channel, opcode, sequence, payload)?;
        let response = self.transport.exchange(&request, self.timeout)?;
        Ok(response.payload)
    }

    fn check_boot_status(&self, value: u8) -> Result<(), ClientError> {
        let status = BootStatus::try_from(value)?;
        match status {
            BootStatus::Accepted => Ok(()),
            status => Err(ClientError::BootRejected(status)),
        }
    }

    fn check_flash_status(&self, value: u8) -> Result<(), ClientError> {
        let status = FlashStatus::try_from(value)?;
        match status {
            FlashStatus::Accepted => Ok(()),
            status => Err(ClientError::FlashRejected(status)),
        }
    }
}
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
